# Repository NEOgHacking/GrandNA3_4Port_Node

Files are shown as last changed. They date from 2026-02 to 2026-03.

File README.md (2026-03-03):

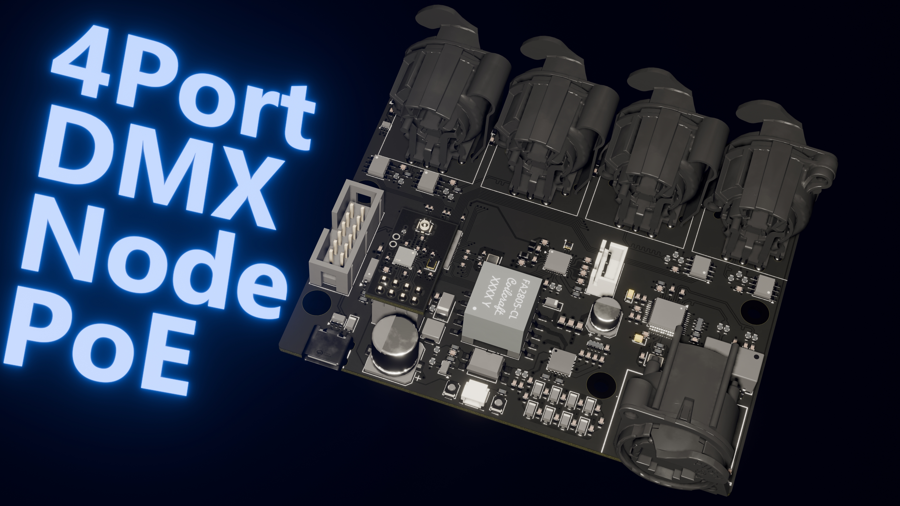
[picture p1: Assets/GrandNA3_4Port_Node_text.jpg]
Render

# GrandNA3_4Port_Node
GrandNA3_4Port_Node is a DMX network node based on the official grandMA3 onPC 4Port Node 4k. My version also has 4DMX outputs with RDM support, a EtherCON connector for sturdy Ethernet connections and a display with a rotating knob for configuration. It also uses the Neutrik halo connectors with adressable rgb leds to show the status of the connection. But it also has some differences. First it unfortunately doesn't unlock any parameters in the GrandMA onPC software, but its 20x cheaper. About $100 instead of $2000.

# Features
This specific DMX node has some really usefull features.
1. 4DMX outputs with RDM support.
2. Neutrik EtherCON connector for a sturdy and lasting connection. Also support for ARTNET and sACN
3. Color display with a rotary encoder for configuration straigt from the unit itself.
4. UPS (uniteruptable power supply) For when the power cuts out but you still need it or just for battery operation.
5. Wifi card slot for wireless operation with the battery.
6. Powered by a rp2350 for its PIO modules so DMX is correctly implemented and not via a hacked uart or bitbanging a pin.
7. PoE (Power over Ethernet) For easy setup and as little wires as possible.
8. USB-C port for power and data to program the rp2350 or configure it.
9. Cheap PCB. The PCB is 100x72mm 4 layer so its cost is low only $7.

# Motivation
I started on making this DMX network node for a few reasons. First i was using a raspberry pi with a usb DMX dongle, this worked but was hard to set up and only got me 1 DMX universe without RDM. It also wasn't the cheapest setup. I wanted it to be cheaper and have more functionallity. Second I once had the opurtunity to use a grandMA3 onPC 4Port Node 4k at school once and realized how usefull it would be. Then my dumb brain said the same sentence it always says: "I can build that myself for cheaper right?" Next thing you know you are 100 hours deep into the project.

# Design
The design process was a heck of a ride, at first i started with the simple DMX part but then got to the ethernet. I really wanted PoE so started with the ride. It was a heck of a long ride, i think it took up 1/3 of the projects time its really complex. Also the most complex schematic from the whole project. The rest went pretty smooth. I had recently done another big project my 3D Printer mainboard and learned allot from that! So the rest was pretty straight forward, always some small chip changes here and there but apart from that it went well. The case design also went quick didn't have to high of standards for that but still wanted it to look good. After a whole day that was done. 
I used KiCad for PCB design, Onshape for 3D design and VScode for Firmware.

# Use
To use this product first get the firmware uploaded via the arduino IDE or PlatformIO Then just plug it into a ethernet setup and plug in your DMX devices. Thats it! Its that simple! For config use the display with the rotating knob to select universes, ethernet settings, ext.

# Schematic
This is a very long schematic. You can find the whole schematics in .PDF format in the individual PCB design folders. But here are some important ones.
First the main schematic of the main PCB.
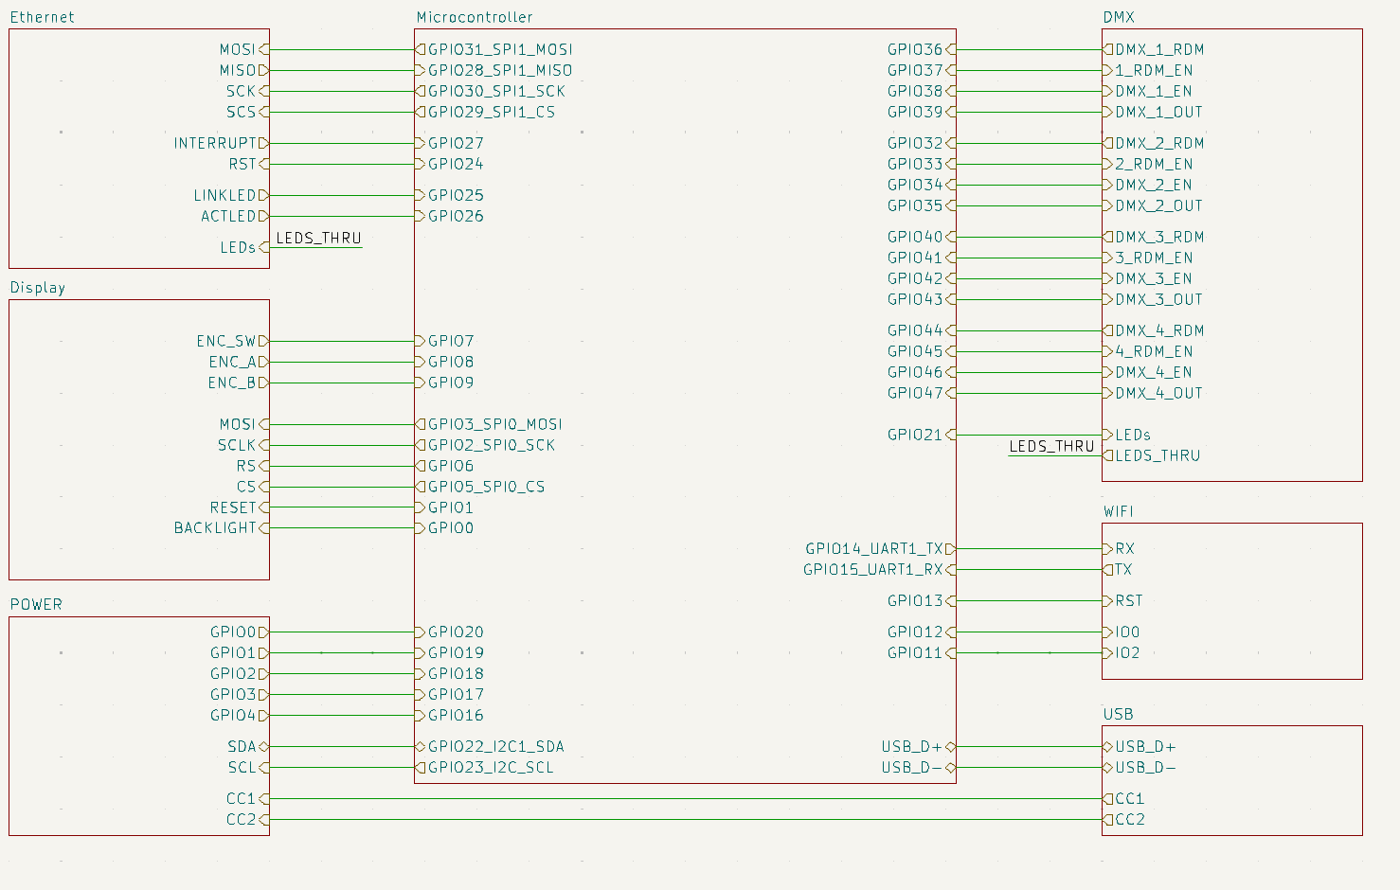
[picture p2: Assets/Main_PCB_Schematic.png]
Main schematic

Then the schematic of the display module.
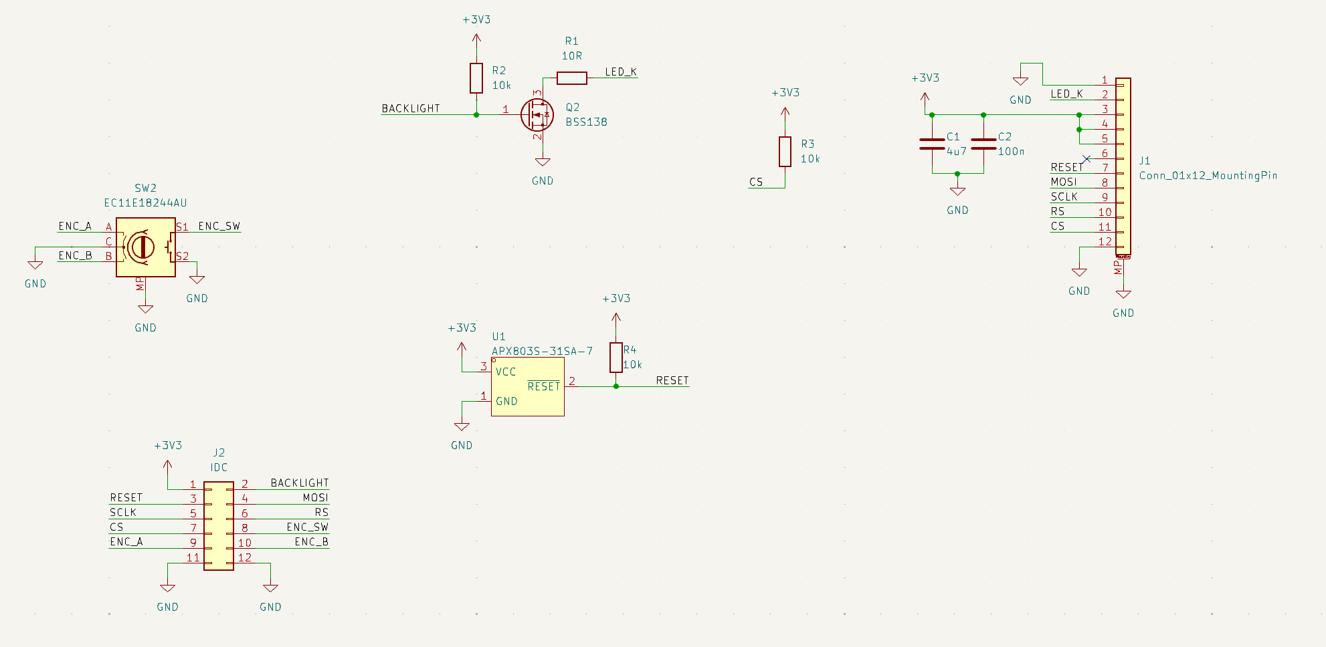
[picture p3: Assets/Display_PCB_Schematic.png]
Display module schematic

And finally the esp wifi module.
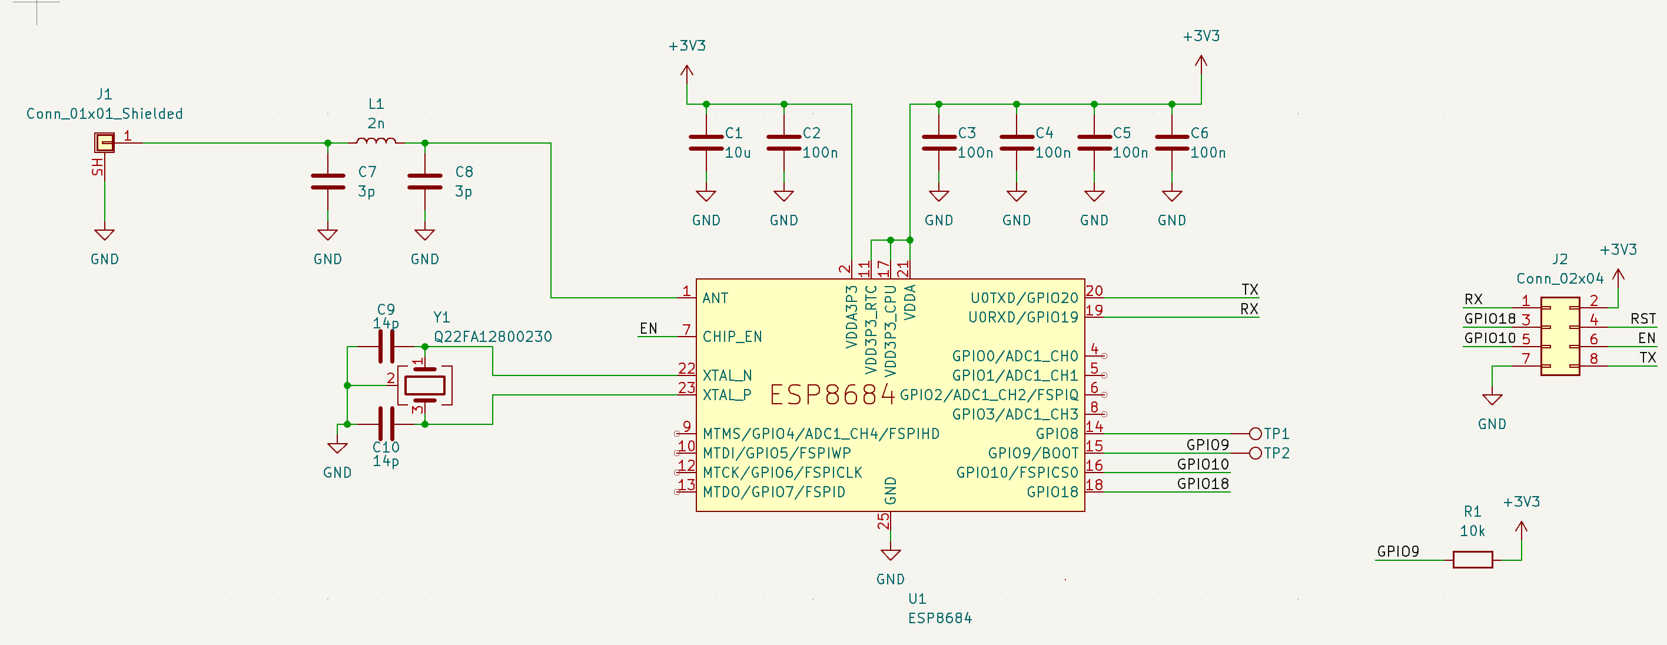
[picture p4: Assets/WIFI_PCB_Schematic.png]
WIFI module schematic


# PCB's
So this project has 3 PCB's, first the main PCB that does all the hard work, then a display PCB with a rotary encoder and support components for a bare LCD and finally a custom made WIFI module PCB based on the esp.
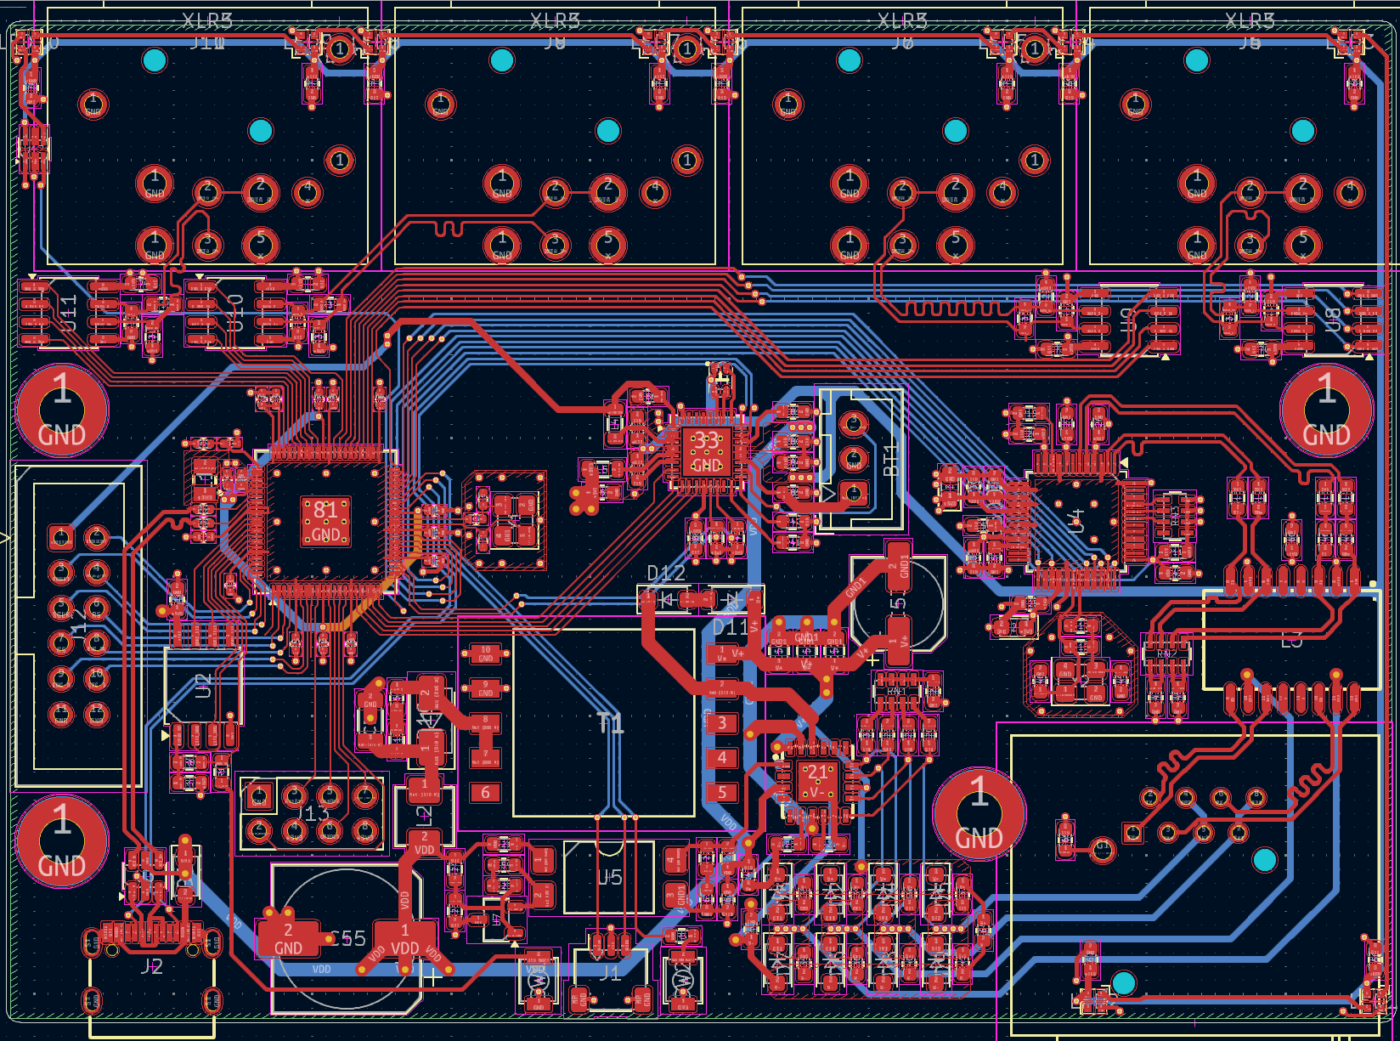
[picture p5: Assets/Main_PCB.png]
Main PCB

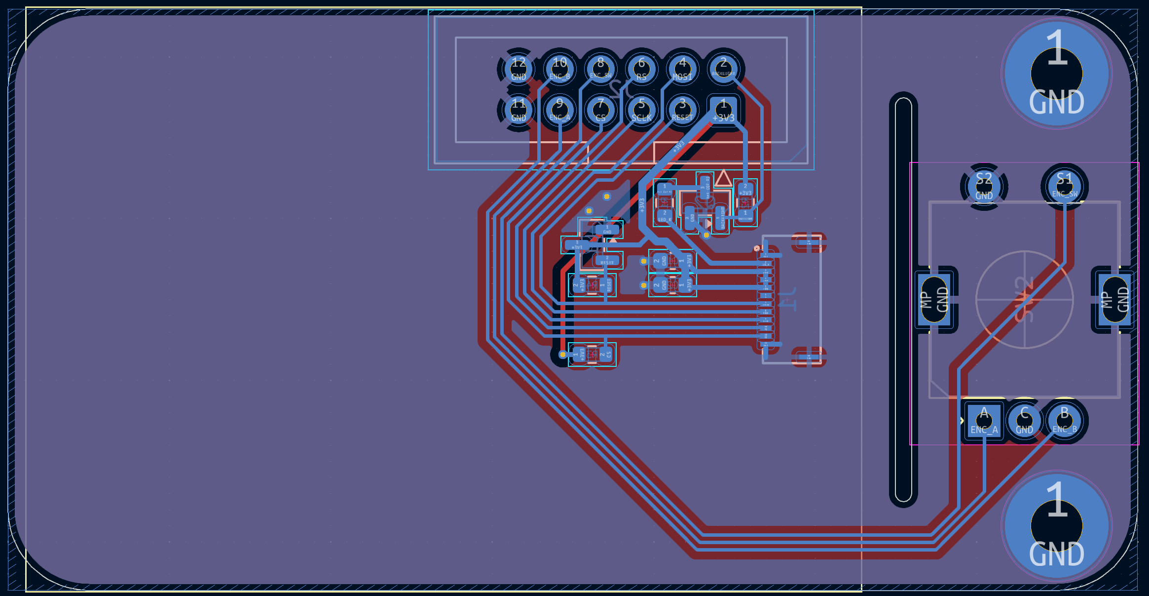
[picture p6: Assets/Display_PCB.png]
Display_module PCB

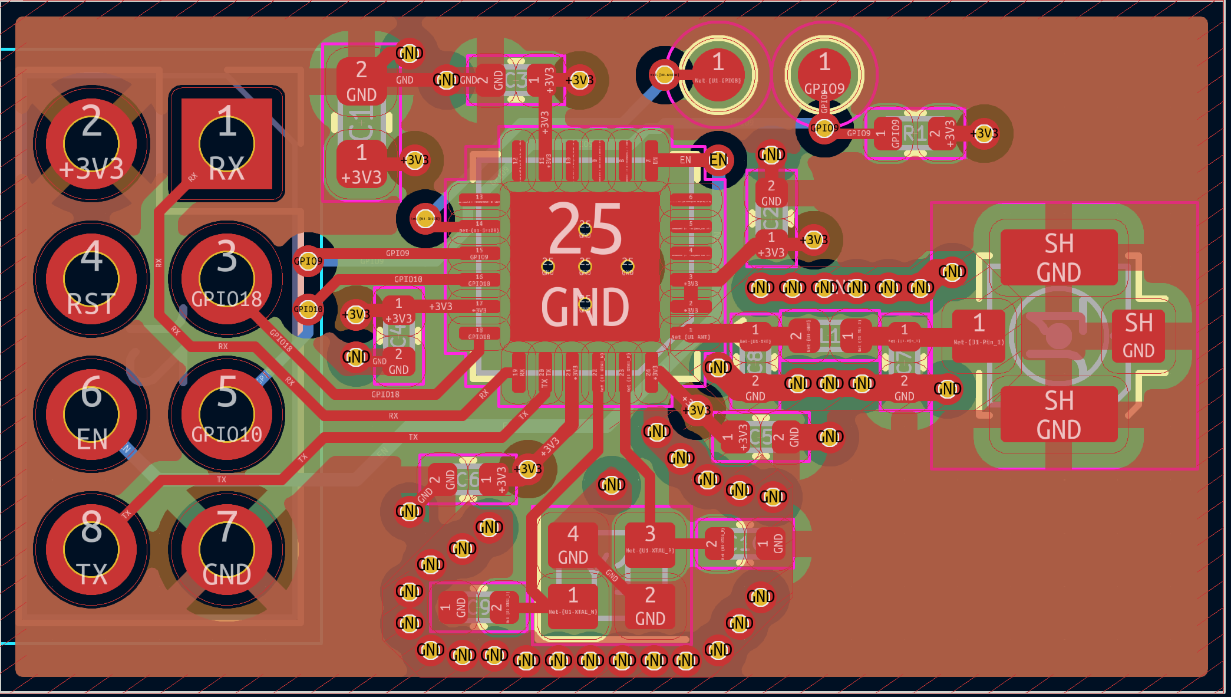
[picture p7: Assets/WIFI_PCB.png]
WIFI_module PCB

(there is a glitch in this game, every project i do i get exactly 3 PCB's)

# Case
For this project there needed to be a case to protect the PCB from the outside world. I did this in onshape and am happy with the end result.
Open_case
Full_case
Here is the Onshape link:
https://cad.onshape.com/documents/7a1aa90c6a7c74ef8699231e/w/3ea57ea1703701009a206be9/e/21fe65d6bda3912845cd8de3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
<details>
  <summary>BOM</summary>
  
# BOM
| Id | Designator | Footprint | Quantity | Designation | Supplier and ref | Column1 | Needed quantity | - | LCSC | MOUSER | Already in another pcb | Enough? | Mrf# | Mfr. | Order Qty. | Unit Price(USD) | Ext.Price(USD) | LCSC#/MOUSER | Package | Min | Mult | SPQ | Availability | Stock Status | Customer Notes | Description | Matched status | Product Link |  |  |  |  |  |  |  |  |  |  |  |  |  |  |  |  |  |  |  |
| --- | --- | --- | --- | --- | --- | --- | --- | --- | --- | --- | --- | --- | --- | --- | --- | --- | --- | --- | --- | --- | --- | --- | --- | --- | --- | --- | --- | --- | --- | --- | --- | --- | --- | --- | --- | --- | --- | --- | --- | --- | --- | --- | --- | --- | --- | --- | --- |
| 17 | BT1 | JST_XH_B3B-XH-A_1x03_P2.50mm_Vertical | 1 | Battery_Cell |  |  | 2 |  | x |  |  |  | B3B-XH-A(LF)(SN) | JST | 10 | $0.05 | $0.50 | C144394 | Through Hole,P=2.5mm | 10 | 10 | 1000 | 61980 | In Stock |  | Connector Header 3 position 2.5mm Pitch 3A Through Hole -25?~+85? | Exact Matches | https://www.lcsc.com/product-detail/C144394.html |  |  |  |  |  |  |  |  |  |  |  |  |  |  |  |  |  |  |  |
| 6 | C12,C7,C5,C13,C11,C4,C6,C3,C9,C10,C8,C1 | C_0402_1005Metric | 12 | 100n |  |  | 24 |  | x |  |  |  | CL05B104KO5NNNC | Samsung Electro-Mechanics | 100 | $0.00 | $0.13 | C1525 | 402 | 100 | 100 | 10000 | 22016000 | In Stock |  | 100nF �10% 16V Ceramic Capacitor X7R 0402 | Exact Matches | https://www.lcsc.com/product-detail/C1525.html |  |  |  |  |  |  |  |  |  |  |  |  |  |  |  |  |  |  |  |
| 37 | C17,C19 | C_0402_1005Metric | 2 | 15p |  |  | 4 |  | x |  |  |  | CL05C150JB5NNNC | Samsung Electro-Mechanics | 100 | $0.00 | $0.37 | C86285 | 402 | 100 | 100 | 10000 | 454800 | In Stock |  | 15pF �5% 50V Ceramic Capacitor C0G 0402 | Exact Matches | https://www.lcsc.com/product-detail/C86285.html |  |  |  |  |  |  |  |  |  |  |  |  |  |  |  |  |  |  |  |
| 3 | C2,C15,C16,C14 | C_0402_1005Metric | 4 | 4u7 |  |  | 8 |  | x |  |  |  | CL05A475KP5NRNC | Samsung Electro-Mechanics | 50 | $0.01 | $0.31 | C368809 | 402 | 50 | 50 | 10000 | 5001000 | In Stock |  | 4.7uF �10% 10V Ceramic Capacitor X5R 0402 | Exact Matches | https://www.lcsc.com/product-detail/C368809.html |  |  |  |  |  |  |  |  |  |  |  |  |  |  |  |  |  |  |  |
| 9 | C20,C23,C57,C33,C21 | C_0603_1608Metric | 5 | 10n |  |  | 10 |  | x |  |  |  | CL10B103KC8NNNC | Samsung Electro-Mechanics | 100 | $0.01 | $0.62 | C84709 | 603 | 100 | 100 | 4000 | 18800 | In Stock |  | 10nF �10% 100V Ceramic Capacitor X7R 0603 | Exact Matches | https://www.lcsc.com/product-detail/C84709.html |  |  |  |  |  |  |  |  |  |  |  |  |  |  |  |  |  |  |  |
| 15 | C22,C36,C39,C41,C34,C38,C63,C37,C65,C47,C40,C35 | C_0603_1608Metric | 12 | 1n |  |  | 24 |  | x |  |  |  | CL10B102KC8NNNC | Samsung Electro-Mechanics | 50 | $0.01 | $0.25 | C153291 | 603 | 50 | 50 | 4000 | 107650 | In Stock |  | 1nF �10% 100V Ceramic Capacitor X7R 0603 | Exact Matches | https://www.lcsc.com/product-detail/C153291.html |  |  |  |  |  |  |  |  |  |  |  |  |  |  |  |  |  |  |  |
| 5 | C27,C76,C72,C70,C73,C64,C79,C60,C28,C74,C29,C88,C43,C78,C61,C71,C30,C66,C69,C68,C25,C42,C75,C67,C45,C31,C18,C26,C77 | C_0603_1608Metric | 29 | 100n |  |  | 58 |  | x |  |  |  | CL10B104KC8NNNC | Samsung Electro-Mechanics | 100 | $0.01 | $0.65 | C15725 | 603 | 50 | 50 | 4000 | 175750 | In Stock |  | 100nF �10% 100V Ceramic Capacitor X7R 0603 | Exact Matches | https://www.lcsc.com/product-detail/C15725.html |  |  |  |  |  |  |  |  |  |  |  |  |  |  |  |  |  |  |  |
| 63 | C32,C24 | CP_EIA-2012-12_Kemet-R | 2 | 10u |  |  | 4 |  | x |  |  |  | T491A106K006AT | KEMET | 5 | $0.18 | $0.91 | C122260 | CASE-A-3216-18(mm) | 5 | 5 | 2000 | 1980 | In Stock |  | 10uF �10% 6.3V Tantalum Capacitors 4?@100kHz CASE-A-3216-18(mm) | Exact Matches | https://www.lcsc.com/product-detail/C122260.html |  |  |  |  |  |  |  |  |  |  |  |  |  |  |  |  |  |  |  |
| 50 | C46,C44 | C_0603_1608Metric | 2 | 6.8n |  |  | 4 |  | x |  |  |  | CL10B682KB8NNNC | Samsung Electro-Mechanics | 100 | $0.01 | $0.68 | C84723 | 603 | 100 | 100 | 4000 | 5300 | In Stock |  | 6.8nF �10% 50V Ceramic Capacitor X7R 0603 | Exact Matches | https://www.lcsc.com/product-detail/C84723.html |  |  |  |  |  |  |  |  |  |  |  |  |  |  |  |  |  |  |  |
| 8 | C48,C49 | C_0603_1608Metric | 2 | 10p |  |  | 4 |  | x |  |  |  | CL10C100JB8NNNC | Samsung Electro-Mechanics | 100 | $0.01 | $0.50 | C1634 | 603 | 100 | 100 | 4000 | 1498600 | In Stock |  | 10pF �5% 50V Ceramic Capacitor C0G 0603 | Exact Matches | https://www.lcsc.com/product-detail/C1634.html |  |  |  |  |  |  |  |  |  |  |  |  |  |  |  |  |  |  |  |
| 41 | C52,C51,C50 | C_0805_2012Metric | 3 | 1u |  |  | 6 |  | x |  |  |  | C2012X7S2A105KT000N | TDK | 10 | $0.11 | $1.12 | C342785 | 805 | 5 | 5 | 2000 | 5645 | In Stock |  | 1uF �10% 100V Ceramic Capacitor X7S 0805 | Exact Matches | https://www.lcsc.com/product-detail/C342785.html |  |  |  |  |  |  |  |  |  |  |  |  |  |  |  |  |  |  |  |
| 57 | C53 | CP_Elec_6.3x5.8 | 1 | 10u |  |  | 2 |  | x |  |  |  | EEEFK1J100P | PANASONIC | 5 | $0.14 | $0.71 | C128459 | SMD,D6.3xL5.8mm | 5 | 5 | 1000 | 1420 | In Stock |  | 10uF �20% 63V Aluminum Electrolytic Capacitors 2000hrs@105? | Exact Matches | https://www.lcsc.com/product-detail/C128459.html |  |  |  |  |  |  |  |  |  |  |  |  |  |  |  |  |  |  |  |
| 69 | C54 | C_0603_1608Metric | 1 | 470p |  |  | 2 |  | x |  |  |  | CL10B471KB8NNNC | Samsung Electro-Mechanics | 100 | $0.01 | $0.56 | C22396 | 603 | 100 | 100 | 4000 | 189700 | In Stock |  | 470pF �10% 50V Ceramic Capacitor X7R 0603 | Exact Matches | https://www.lcsc.com/product-detail/C22396.html |  |  |  |  |  |  |  |  |  |  |  |  |  |  |  |  |  |  |  |
| 44 | C55 | CP_Elec_10x10.5 | 1 | 1000u |  |  | 2 |  | x |  |  |  | EEEFT1E102UP | PANASONIC | 2 | $0.78 | $1.55 | C401766 | SMD,D10xL10.2mm | 1 | 1 | 500 | 4041 | In Stock |  | 1000uF �20% 25V Aluminum Electrolytic Capacitors 2000hrs@105? | Exact Matches | https://www.lcsc.com/product-detail/C401766.html |  |  |  |  |  |  |  |  |  |  |  |  |  |  |  |  |  |  |  |
| 52 | C56 | C_1206_3216Metric | 1 | 100u |  |  | 2 |  | x |  |  |  | CL31A107MQHNNNE | Samsung Electro-Mechanics | 10 | $0.06 | $0.61 | C15008 | 1206 | 10 | 10 | 2000 | 6009890 | In Stock |  | 100uF �20% 6.3V Ceramic Capacitor X5R 1206 | Exact Matches | https://www.lcsc.com/product-detail/C15008.html |  |  |  |  |  |  |  |  |  |  |  |  |  |  |  |  |  |  |  |
| 14 | C58 | C_0603_1608Metric | 1 | 4u7 |  |  | 2 |  | x |  |  |  | CL10A475KP8NNNC | Samsung Electro-Mechanics | 50 | $0.01 | $0.28 | C1705 | 603 | 50 | 50 | 4000 | 13333100 | In Stock |  | 4.7uF �10% 10V Ceramic Capacitor X5R 0603 | Exact Matches | https://www.lcsc.com/product-detail/C1705.html |  |  |  |  |  |  |  |  |  |  |  |  |  |  |  |  |  |  |  |
| 20 | C59 | C_0603_1608Metric | 1 | 3.3n |  |  | 2 |  | x |  |  |  | CL10B332KB8NNNC | Samsung Electro-Mechanics | 20 | $0.01 | $0.11 | C1613 | 603 | 20 | 20 | 4000 | 61420 | In Stock |  | 3.3nF �10% 50V Ceramic Capacitor X7R 0603 | Exact Matches | https://www.lcsc.com/product-detail/C1613.html |  |  |  |  |  |  |  |  |  |  |  |  |  |  |  |  |  |  |  |
| 42 | C62 | C_0603_1608Metric | 1 | 15n |  |  | 2 |  | x |  |  |  | CL10B153KB8NNNC | Samsung Electro-Mechanics | 20 | $0.01 | $0.16 | C296713 | 603 | 20 | 20 | 4000 | 39800 | In Stock |  | 15nF �10% 50V Ceramic Capacitor X7R 0603 | Exact Matches | https://www.lcsc.com/product-detail/C296713.html |  |  |  |  |  |  |  |  |  |  |  |  |  |  |  |  |  |  |  |
| 10 | C80,C81 | C_0603_1608Metric | 2 | 1u |  |  | 4 |  | x |  |  |  | CL10A105KB8NNNC | Samsung Electro-Mechanics | 50 | $0.01 | $0.28 | C15849 | 603 | 50 | 50 | 4000 | 4548950 | In Stock |  | 1uF �10% 50V Ceramic Capacitor X5R 0603 | Exact Matches | https://www.lcsc.com/product-detail/C15849.html |  |  |  |  |  |  |  |  |  |  |  |  |  |  |  |  |  |  |  |
| 53 | C82,C86,C87,C83,C84 | C_0603_1608Metric | 5 | 10u |  |  | 10 |  | x |  |  |  | CL10A106KP8NNNC | Samsung Electro-Mechanics | 50 | $0.01 | $0.33 | C19702 | 603 | 50 | 50 | 4000 | 13475400 | In Stock |  | 10uF �10% 10V Ceramic Capacitor X5R 0603 | Exact Matches | https://www.lcsc.com/product-detail/C19702.html |  |  |  |  |  |  |  |  |  |  |  |  |  |  |  |  |  |  |  |
| 58 | C85 | C_0603_1608Metric | 1 | 2u2 |  |  | 2 |  | x |  |  |  | CL10A225KO8NNNC | Samsung Electro-Mechanics | 50 | $0.01 | $0.31 | C23630 | 603 | 50 | 50 | 4000 | 5941500 | In Stock |  | 2.2uF �10% 16V Ceramic Capacitor X5R 0603 | Exact Matches | https://www.lcsc.com/product-detail/C23630.html |  |  |  |  |  |  |  |  |  |  |  |  |  |  |  |  |  |  |  |
| 32 | D1 | D_SOD-123F | 1 | DSK24L |  |  | 2 |  | x |  |  |  | DSK24L | LGE | 10 | $0.06 | $0.62 | C19272974 | SOD-123FL | 10 | 10 | 3000 | 2600 | In Stock |  | Diode Independent 40V 2A Surface Mount SOD-123FL | Exact Matches | https://www.lcsc.com/product-detail/C19272974.html |  |  |  |  |  |  |  |  |  |  |  |  |  |  |  |  |  |  |  |
| 56 | D10 | D_SMA | 1 | SS34 |  |  | 2 |  | x |  |  |  | SS34 | GOODWORK | 20 | $0.03 | $0.56 | C908680 | SMA(DO-214AC) | 20 | 20 | 5000 | 202260 | In Stock |  | Diode Independent 40V 3A Surface Mount SMA(DO-214AC) | Exact Matches | https://www.lcsc.com/product-detail/C908680.html |  |  |  |  |  |  |  |  |  |  |  |  |  |  |  |  |  |  |  |
| 49 | D11 | D_SOD-123 | 1 | 1N4148W |  |  | 2 |  | x |  |  |  | 1N4148W-E3-08 | VISHAY | 5 | $0.03 | $0.17 | C241939 | SOD-123 | 5 | 5 | 3000 | 71145 | In Stock |  | Diode Independent 75V 150mA Surface Mount SOD-123 | Exact Matches | https://www.lcsc.com/product-detail/C241939.html |  |  |  |  |  |  |  |  |  |  |  |  |  |  |  |  |  |  |  |
| 66 | D12 | D_SOD-123F | 1 | DFTL30A |  |  | 2 |  | x |  |  |  | P4FL30A_R1_00001 | PANJIT | 5 | $0.09 | $0.43 | C2902532 | SOD-123FL | 5 | 5 | 3000 | 2220 | In Stock |  | 48.4VC Clamp 8.3A@10/1000us Ipp TVS DIODE SOD-123FL | Exact Matches | https://www.lcsc.com/product-detail/C2902532.html |  |  |  |  |  |  |  |  |  |  |  |  |  |  |  |  |  |  |  |
| 11 | D13 | LED-SMD_4P-L1.6-W1.5-TR | 1 | LED_ABGR |  |  | 2 |  | x |  |  |  | DY-S161506BRGC-T5-4T-03 | TONYU | 10 | $0.04 | $0.37 | C7280953 | SMD,1.6x1.5mm | 10 | 10 | 4000 | 1640 | In Stock |  | Red, Green, Blue 630nm LED Indication - Discrete 1.8V~2.4V SMD,1.5x1.6mm | Exact Matches | https://www.lcsc.com/product-detail/C7280953.html |  |  |  |  |  |  |  |  |  |  |  |  |  |  |  |  |  |  |  |
| 28 | D2,D7,D5,D6,D9,D3,D4,D8 | D_SOD-123F | 8 | SL110PL-TP |  |  | 16 |  | x |  |  |  | SL110PL-TP | MCC | 20 | $0.15 | $3.07 | C7080765 | SOD-123FL | 10 | 10 | 2500 | 4140 | In Stock |  | Diode 100V 1A Surface Mount SOD-123FL | Exact Matches | https://www.lcsc.com/product-detail/C7080765.html |  |  |  |  |  |  |  |  |  |  |  |  |  |  |  |  |  |  |  |
| 62 | IC1 | QFN-32-1EP_5x5mm_P0.5mm_EP3.45x3.45mm_ThermalVias | 1 | NPM1300-QEAA-R7 |  |  | 2 |  |  | x |  |  | nPM1300-QEAA-R7 | Nordic Semiconductor | 2 | $1.54 | $3.08 | 949-NPM1300-QEAA-R7 |  |  |  |  |  |  |  |  |  | https://nl.mouser.com/ProductDetail/Nordic-Semiconductor/nPM1300-QEAA-R7?qs=3pZoU%2F6IRTj0hxAp51B2zA%3D%3D |  |  |  |  |  |  |  |  |  |  |  |  |  |  |  |  |  |  |  |
| 33 | J1 | JST_SH_SM03B-SRSS-TB_1x03-1MP_P1.00mm_Horizontal | 1 | Conn_01x03_MountingPin |  |  | 2 |  | x |  |  |  | SM03B-SRSS-TB(LF)(SN) | JST | 5 | $0.17 | $0.87 | C160403 | SMD,P=1mm,Surface Mount,Right Angle | 5 | 5 | 3000 | 47315 | In Stock |  | Connector Header 3 position 1mm Pitch 1A Surface Mount, Right Angle -25?~+85? | Exact Matches | https://www.lcsc.com/product-detail/C160403.html |  |  |  |  |  |  |  |  |  |  |  |  |  |  |  |  |  |  |  |
| 39 | J12 | IDC-Header_2x06_P2.54mm_Vertical | 1 | IDC |  |  | 2 |  | x |  |  |  | 2.54-2*6P | BOOMELE(Boom Precision Elec) | 5 | $0.11 | $0.57 | C9136 | Through Hole,P=2.54mm | 5 | 5 | 220 | 19840 | In Stock |  | Connector IDC Header Through Hole 12 position 2.54mm | Exact Matches | https://www.lcsc.com/product-detail/C9136.html |  |  |  |  |  |  |  |  |  |  |  |  |  |  |  |  |  |  |  |
| 51 | J13 | PinSocket_2x04_P2.54mm_Vertical | 1 | Conn_02x04 |  |  | 2 |  | x |  |  |  | PM254V-12-08-H85 | XFCN | 5 | $0.11 | $0.56 | C2834799 | Through Hole,P=2.54mm | 5 | 5 | 1000 | 26375 | In Stock |  | Female Header 8 Position 2.54mm Pitch Dual Row Through Hole -40?~+105? | Exact Matches | https://www.lcsc.com/product-detail/C2834799.html |  |  |  |  |  |  |  |  |  |  |  |  |  |  |  |  |  |  |  |
| 13 | J2 | USB-C_SMD-TYPE-C-31-M-12_1 | 1 | USB_C_Receptacle_USB2.0_14P |  |  | 2 |  | x |  |  |  | TYPE-C-31-M-12 | Korean Hroparts Elec | 5 | $0.17 | $0.84 | C165948 | SMD | 5 | 5 | 1000 | 263130 | In Stock |  | USB-C (USB TYPE-C) Receptacle Connector 16 Position Surface Mount | Exact Matches | https://www.lcsc.com/product-detail/C165948.html |  |  |  |  |  |  |  |  |  |  |  |  |  |  |  |  |  |  |  |
| 1 | J3 | NE8FAHLRDAE | 1 | RJ45 |  |  | 2 |  |  | x |  |  | NE8FAH-LR-DAE | Neutrik | 2 | $6.73 | $13.46 | 568-NE8FAH-LR-DAE |  |  |  |  |  |  |  |  |  | https://nl.mouser.com/ProductDetail/Neutrik/NE8FAH-LR-DAE?qs=4ASt3YYao0WhX9cY4j%252BFSA%3D%3D |  |  |  |  |  |  |  |  |  |  |  |  |  |  |  |  |  |  |  |
| 12 | J4,J8,J10,J6 | NC5FAH1-LR-DAE | 4 | XLR5 |  |  | 4 |  |  | x |  |  | NC5FAH1-LR-DAE | Neutrik | 4 | $7.79 | $31.16 | 568-NC5FAH1-LR-DAE |  |  |  |  |  |  |  |  |  | https://nl.mouser.com/ProductDetail/Neutrik/NC5FAH1-LR-DAE?qs=6avfeC6zeS5u3oz5Q9UQlw%3D%3D |  |  |  |  |  |  |  |  |  |  |  |  |  |  |  |  |  |  |  |
| 47 | J7,J11,J5,J9 | NC3FAH2-LR-DAE | 4 | XLR3 |  |  | 4 |  |  | x |  |  | NC3FAH2-LR-DAE | Neutrik | 4 | $4.33 | $17.32 | 568-NC3FAH2-LR-DAE |  |  |  |  |  |  |  |  |  | https://nl.mouser.com/ProductDetail/Neutrik/NC3FAH2-LR-DAE?qs=4ASt3YYao0XSl5KoEkZrIA%3D%3D |  |  |  |  |  |  |  |  |  |  |  |  |  |  |  |  |  |  |  |
| 21 | L1 | IND-SMD_L2.0-W1.6_AOTA-B201610S3R3-101-T | 1 | 3.3u |  |  | 2 |  | x |  |  |  | AOTA-B201610S3R3-101-T | ABRACON | 5 | $0.29 | $1.44 | C42411119 | 806 | 5 | 5 | 3000 | 15360 | In Stock |  | 2.1A 3.3uH 115m? 2.4A Molded Inductor 0806 Fixed Inductors RoHS | Exact Matches | https://www.lcsc.com/product-detail/C42411119.html |  |  |  |  |  |  |  |  |  |  |  |  |  |  |  |  |  |  |  |
| 48 | L2 | L_Vishay_IHLP-1616 | 1 | 1u |  |  | 2 |  | x |  |  |  | IHLP1616BZER1R0M11 | VISHAY | 2 | $1.63 | $3.26 | C844978 | 1616 | 1 | 1 | 4000 | 79 | In Stock |  | 4.5A 1uH 27m? 5A �20% 1616 Fixed Inductors RoHS | Exact Matches | https://www.lcsc.com/product-detail/C844978.html |  |  |  |  |  |  |  |  |  |  |  |  |  |  |  |  |  |  |  |
| 22 | L3 | XFMR-SMD_16P-L12.7-W7.1-P1.27-LS9.4-BL | 1 | H2019NLT |  |  | 2 |  | x |  |  |  | H2019NLT | PULSE | 2 | $0.74 | $1.49 | C110250 | SMD,12.7x7.1mm | 1 | 1 | 600 | 2085 | In Stock |  | LAN Transformer 1CT:1CT Surface Mount,12.7x7.1mm | Exact Matches | https://www.lcsc.com/product-detail/C110250.html |  |  |  |  |  |  |  |  |  |  |  |  |  |  |  |  |  |  |  |
| 30 | L4,L5 | L_0805_2012Metric | 2 | 2u2 |  |  | 4 |  | x |  |  |  | MLP2012H2R2MT0S1 | TDK | 10 | $0.08 | $0.84 | C383369 | 805 | 10 | 10 | 4000 | 89820 | In Stock |  | 1A 2.2uH 195m? �20% 0805 Fixed Inductors RoHS | Exact Matches | https://www.lcsc.com/product-detail/C383369.html |  |  |  |  |  |  |  |  |  |  |  |  |  |  |  |  |  |  |  |
| 16 | LED1,LED5,LED6,LED3,LED8,LED10,LED9,LED2,LED4,LED7 | LED-SMD_4P-L1.5-W1.5-BL | 10 | SK6805-EC15 |  |  | 20 |  | x |  |  |  | SK6805-EC15 | OPSCO Optoelectronics | 45 | $0.09 | $4.04 | C2890035 | SMD-4P,1.5x1.5mm | 5 | 5 | 4500 | 259070 | In Stock |  | SMD-4P,1.5x1.5mm LED Addressable, Specialty RoHS | Exact Matches | https://www.lcsc.com/product-detail/C2890035.html |  |  |  |  |  |  |  |  |  |  |  |  |  |  |  |  |  |  |  |
| 29 | R1,R27,R3 | R_0603_1608Metric | 3 | 1k |  |  | 6 |  | x |  |  |  | RC0603FR-071KL | YAGEO | 100 | $0.00 | $0.14 | C22548 | 603 | 100 | 100 | 5000 | 4596000 | In Stock |  | 100mW 1k? 75V Thick Film Resistor �100ppm/? �1% 0603 Chip Resistor - Surface Mount RoHS | Exact Matches | https://www.lcsc.com/product-detail/C22548.html |  |  |  |  |  |  |  |  |  |  |  |  |  |  |  |  |  |  |  |
| 34 | R11,R43,R7,R42 | R_0603_1608Metric | 4 | 10k |  |  | 8 |  | x |  |  |  | RC0603FR-0710KL | YAGEO | 100 | $0.00 | $0.14 | C98220 | 603 | 100 | 100 | 5000 | 9034300 | In Stock |  | 100mW 10k? 75V Thick Film Resistor �100ppm/? �1% 0603 Chip Resistor - Surface Mount RoHS | Exact Matches | https://www.lcsc.com/product-detail/C98220.html |  |  |  |  |  |  |  |  |  |  |  |  |  |  |  |  |  |  |  |
| 19 | R13,R12,R15,R14 | R_0603_1608Metric | 4 | 33R |  |  | 8 |  | x |  |  |  | RC0603FR-0733RL | YAGEO | 100 | $0.00 | $0.15 | C108661 | 603 | 100 | 100 | 5000 | 1912100 | In Stock |  | 100mW 33? 75V Thick Film Resistor �100ppm/? �1% 0603 Chip Resistor - Surface Mount RoHS | Exact Matches | https://www.lcsc.com/product-detail/C108661.html |  |  |  |  |  |  |  |  |  |  |  |  |  |  |  |  |  |  |  |
| 38 | R16 | R_0603_1608Metric | 1 | 1M |  |  | 2 |  | x |  |  |  | RC0603FR-071ML | YAGEO | 100 | $0.00 | $0.15 | C105578 | 603 | 100 | 100 | 5000 | 711300 | In Stock |  | 100mW 1M? 75V Thick Film Resistor �100ppm/? �1% 0603 Chip Resistor - Surface Mount RoHS | Exact Matches | https://www.lcsc.com/product-detail/C105578.html |  |  |  |  |  |  |  |  |  |  |  |  |  |  |  |  |  |  |  |
| 2 | R18 | R_0603_1608Metric | 1 | 10R |  |  | 2 |  | x |  |  |  | RC0603FR-0710RL | YAGEO | 100 | $0.00 | $0.43 | C109318 | 603 | 100 | 100 | 5000 | 1937200 | In Stock |  | 100mW 10? 75V Thick Film Resistor �1% �200ppm/? 0603 Chip Resistor - Surface Mount RoHS | Exact Matches | https://www.lcsc.com/product-detail/C109318.html |  |  |  |  |  |  |  |  |  |  |  |  |  |  |  |  |  |  |  |
| 72 | R19 | R_0603_1608Metric | 1 | 12.4k |  |  | 2 |  | x |  |  |  | RC0603FR-0712K4L | YAGEO | 100 | $0.00 | $0.15 | C137798 | 603 | 100 | 100 | 5000 | 38200 | In Stock |  | 100mW 12.4k? 75V Thick Film Resistor �100ppm/? �1% 0603 Chip Resistor - Surface Mount RoHS | Exact Matches | https://www.lcsc.com/product-detail/C137798.html |  |  |  |  |  |  |  |  |  |  |  |  |  |  |  |  |  |  |  |
| 54 | R2 | R_0402_1005Metric | 1 | 33R |  |  | 2 |  | x |  |  |  | RC0402FR-0733RL | YAGEO | 100 | $0.00 | $0.08 | C138002 | 402 | 100 | 100 | 10000 | 1384200 | In Stock |  | 62.5mW 33? 50V Thick Film Resistor �100ppm/? �1% 0402 Chip Resistor - Surface Mount RoHS | Exact Matches | https://www.lcsc.com/product-detail/C138002.html |  |  |  |  |  |  |  |  |  |  |  |  |  |  |  |  |  |  |  |
| 73 | R20 | R_0603_1608Metric | 1 | 4.99k |  |  | 2 |  | x |  |  |  | RC0603FR-074K99L | YAGEO | 100 | $0.00 | $0.15 | C114621 | 603 | 100 | 100 | 5000 | 164800 | In Stock |  | 100mW 4.99k? 75V Thick Film Resistor �100ppm/? �1% 0603 Chip Resistor - Surface Mount RoHS | Exact Matches | https://www.lcsc.com/product-detail/C114621.html |  |  |  |  |  |  |  |  |  |  |  |  |  |  |  |  |  |  |  |
| 24 | R21 | R_0603_1608Metric | 1 | 2.05k |  |  | 2 |  | x |  |  |  | RC0603FR-072K05L | YAGEO | 100 | $0.00 | $0.14 | C137751 | 603 | 100 | 100 | 5000 | 7700 | In Stock |  | 100mW 2.05k? 75V Thick Film Resistor �100ppm/? �1% 0603 Chip Resistor - Surface Mount RoHS | Exact Matches | https://www.lcsc.com/product-detail/C137751.html |  |  |  |  |  |  |  |  |  |  |  |  |  |  |  |  |  |  |  |
| 46 | R22,R40,R23,R17,R8 | R_0603_1608Metric | 5 | 0R |  |  | 10 |  | x |  |  |  | RC0603FR-070RL | YAGEO | 100 | $0.00 | $0.13 | C100044 | 603 | 100 | 100 | 5000 | 2174100 | In Stock |  | 0? 100mW 75V Thick Film Resistor �1% 0603 Chip Resistor - Surface Mount RoHS | Exact Matches | https://www.lcsc.com/product-detail/C100044.html |  |  |  |  |  |  |  |  |  |  |  |  |  |  |  |  |  |  |  |
| 55 | R24 | R_0603_1608Metric | 1 | 36.5k |  |  | 2 |  | x |  |  |  | RC0603FR-0736K5L | YAGEO | 100 | $0.00 | $0.14 | C137738 | 603 | 100 | 100 | 5000 | 20500 | In Stock |  | 36.5k? 100mW 75V Thick Film Resistor �100ppm/? �1% 0603 Chip Resistor - Surface Mount RoHS | Exact Matches | https://www.lcsc.com/product-detail/C137738.html |  |  |  |  |  |  |  |  |  |  |  |  |  |  |  |  |  |  |  |
| 68 | R25 | R_0603_1608Metric | 1 | 12.1k |  |  | 2 |  | x |  |  |  | RC0603FR-0712K1L | YAGEO | 100 | $0.00 | $0.18 | C123417 | 603 | 100 | 100 | 5000 | 0 | Backordered |  | 100mW 12.1k? 75V Thick Film Resistor �100ppm/? �1% 0603 Chip Resistor - Surface Mount RoHS | Exact Matches | https://www.lcsc.com/product-detail/C123417.html |  |  |  |  |  |  |  |  |  |  |  |  |  |  |  |  |  |  |  |
| 67 | R26 | R_0603_1608Metric | 1 | 24.9k |  |  | 2 |  | x |  |  |  | RC0603FR-0724K9L | YAGEO | 100 | $0.00 | $0.15 | C137761 | 603 | 100 | 100 | 5000 | 0 | Backordered |  | 100mW 24.9k? 75V Thick Film Resistor �100ppm/? �1% 0603 Chip Resistor - Surface Mount RoHS | Exact Matches | https://www.lcsc.com/product-detail/C137761.html |  |  |  |  |  |  |  |  |  |  |  |  |  |  |  |  |  |  |  |
| 4 | R29,R38,R28,R30,R39,R31,R36,R37 | R_0603_1608Metric | 8 | 348R |  |  | 16 |  | x |  |  |  | RC0603FR-07348RL | YAGEO | 100 | $0.00 | $0.14 | C137742 | 603 | 100 | 100 | 5000 | 6700 | In Stock |  | 100mW 348? 75V Thick Film Resistor �100ppm/? �1% 0603 Chip Resistor - Surface Mount RoHS | Exact Matches | https://www.lcsc.com/product-detail/C137742.html |  |  |  |  |  |  |  |  |  |  |  |  |  |  |  |  |  |  |  |
| 26 | R33,R32,R35,R34 | R_0603_1608Metric | 4 | 133R |  |  | 8 |  | x |  |  |  | RC0603FR-07133RL | YAGEO | 100 | $0.00 | $0.07 | C273752 | 603 | 100 | 100 | 5000 | 0 | Backordered |  | 133? 100mW 75V Thick Film Resistor �100ppm/? �1% 0603 Chip Resistor - Surface Mount RoHS | Exact Matches | https://www.lcsc.com/product-detail/C273752.html |  |  |  |  |  |  |  |  |  |  |  |  |  |  |  |  |  |  |  |
| 61 | R41 | R_0603_1608Metric | 1 | 430k |  |  | 2 |  | x |  |  |  | RC0603FR-07430KL | YAGEO | 100 | $0.00 | $0.15 | C482869 | 603 | 100 | 100 | 5000 | 30900 | In Stock |  | 430k? 100mW 75V Thick Film Resistor �100ppm/? �1% 0603 Chip Resistor - Surface Mount RoHS | Exact Matches | https://www.lcsc.com/product-detail/C482869.html |  |  |  |  |  |  |  |  |  |  |  |  |  |  |  |  |  |  |  |
| 7 | R5,R4 | R_0402_1005Metric | 2 | 27R |  |  | 4 |  | x |  |  |  | RC0402FR-0727RL | YAGEO | 100 | $0.00 | $0.09 | C138021 | 402 | 100 | 100 | 10000 | 134000 | In Stock |  | 27? �1% 62.5mW 0402 Thick Film Resistor | Exact Matches | https://www.lcsc.com/product-detail/C138021.html |  |  |  |  |  |  |  |  |  |  |  |  |  |  |  |  |  |  |  |
| 64 | R6 | R_0402_1005Metric | 1 | 1k |  |  | 2 |  | x |  |  |  | RC0402FR-071KL | YAGEO | 100 | $0.00 | $0.08 | C106235 | 402 | 100 | 100 | 10000 | 5619500 | In Stock |  | 1k? 62.5mW 50V Thick Film Resistor �100ppm/? �1% 0402 Chip Resistor - Surface Mount RoHS | Exact Matches | https://www.lcsc.com/product-detail/C106235.html |  |  |  |  |  |  |  |  |  |  |  |  |  |  |  |  |  |  |  |
| 45 | REF**,REF**,REF** | NLR-LB | 3 | NLR-LB |  |  | 6 |  |  | x |  |  | NLR-LB | Neutrik | 6 | $1.01 | $6.06 | 568-NLR-LB |  |  |  |  |  |  |  |  |  | https://nl.mouser.com/ProductDetail/Neutrik/NLR-LB?qs=Imq1NPwxi76abBKVKeKReg%3D%3D |  |  |  |  |  |  |  |  |  |  |  |  |  |  |  |  |  |  |  |
| 36 | RN1,RN2 | R_Array_Concave_4x0603 | 2 | 75R |  |  | 4 |  | x |  |  |  | RTA03-4D750JTP | RALEC | 100 | $0.01 | $0.50 | C102680 | 0603x4 | 100 | 100 | 5000 | 584400 | In Stock |  | 4 �5% 75? 62.5mW �200ppm/? 0603x4 Resistor Networks, Arrays RoHS | Exact Matches | https://www.lcsc.com/product-detail/C102680.html |  |  |  |  |  |  |  |  |  |  |  |  |  |  |  |  |  |  |  |
| 59 | RN3 | R_Array_Concave_4x0603 | 1 | 10k |  |  | 2 |  | x |  |  |  | YC164-FR-0710KL | YAGEO | 50 | $0.01 | $0.47 | C110924 | 0603x4 | 50 | 50 | 5000 | 15400 | In Stock |  | 4 �1% 10k? 62.5mW �200ppm/? 0603x4 Resistor Networks, Arrays RoHS | Exact Matches | https://www.lcsc.com/product-detail/C110924.html |  |  |  |  |  |  |  |  |  |  |  |  |  |  |  |  |  |  |  |
| 18 | SW2,SW1 | SW_SPST_B3U-1000P | 2 | SW_Push |  |  | 4 |  | x |  |  |  | B3U-1000P | OMRON | 5 | $0.22 | $1.09 | C231329 | SMD,3x2.5mm | 5 | 5 | 3500 | 107795 | In Stock |  | Tactile Switch SPST 153gf 1.6mm SMD (SMT) Tab 3mm x 2.5mm Surface Mount | Exact Matches | https://www.lcsc.com/product-detail/C231329.html |  |  |  |  |  |  |  |  |  |  |  |  |  |  |  |  |  |  |  |
| 65 | T1 | FA2924ALD | 1 | FA2805 |  |  | 2 |  |  | x |  |  | FA2805-CLD | Coilcraft | 2 | $4.94 | $9.88 | 994-FA2805-CLD |  |  |  |  |  |  |  |  |  | https://nl.mouser.com/ProductDetail/Coilcraft/FA2805-CLD?qs=ZYnrCdKdyef%252BZjF1kFFBVA%3D%3D |  |  |  |  |  |  |  |  |  |  |  |  |  |  |  |  |  |  |  |
| 43 | U1 | QFN-80-1EP_10x10mm_P0.4mm_EP3.4x3.4mm | 1 | RP2350B |  |  | 2 |  |  | x |  |  | SC1510(13)-A4 | Raspberry Pi | 2 | $0.90 | $1.79 | 358-SC151013 |  |  |  |  |  |  |  |  |  | https://nl.mouser.com/ProductDetail/Raspberry-Pi/SC151013-A4?qs=jcD%2FCkGBYeM5TtP1Ew4BSg%3D%3D |  |  |  |  |  |  |  |  |  |  |  |  |  |  |  |  |  |  |  |
| 31 | U10,U8,U9,U11 | SOIC-8_3.9x4.9mm_P1.27mm | 4 | MAX3485 |  |  | 8 |  | x |  |  |  | MAX3485EESA+T | MAXIM | 8 | $2.30 | $18.38 | C9943 | SOIC-8 | 1 | 1 | 2500 | 12603 | In Stock |  | 3V~3.6V Transceiver 12Mbps Half-Duplex SOIC-8 Drivers, Receivers, Transceivers RoHS | Exact Matches | https://www.lcsc.com/product-detail/C9943.html |  |  |  |  |  |  |  |  |  |  |  |  |  |  |  |  |  |  |  |
| 25 | U12 | SOT-363_SC-70-6 | 1 | TXS0101DCK |  |  | 2 |  | x |  |  |  | TXS0101DCKR | TI | 2 | $0.52 | $1.04 | C132031 | SC-70-6 | 1 | 1 | 3000 | 660 | In Stock |  | 24Mbps 1 1 SC-70-6 Translators, Level Shifters RoHS | Exact Matches | https://www.lcsc.com/product-detail/C132031.html |  |  |  |  |  |  |  |  |  |  |  |  |  |  |  |  |  |  |  |
| 70 | U2 | SOIC-8_5.3x5.3mm_P1.27mm | 1 | W25Q128JVS |  |  | 2 |  | x |  |  |  | W25Q128JVSIQ | Winbond | 5 | $2.34 | $11.69 | C97521 | SOIC-8-208mil | 5 | 5 | 2000 | 59900 | In Stock |  | 2.7V~3.6V 128Mbit 133MHz SPI SOIC-8-208mil Memory (ICs) RoHS | Exact Matches | https://www.lcsc.com/product-detail/C97521.html |  |  |  |  |  |  |  |  |  |  |  |  |  |  |  |  |  |  |  |
| 27 | U3 | SOT-23-6 | 1 | USBLC6-2SC6 |  |  | 2 |  | x |  |  |  | USBLC6-2SC6 | ST | 5 | $0.14 | $0.69 | C7519 | SOT-23-6L | 5 | 5 | 3000 | 29740 | In Stock |  | 17VC Clamp 5A Ipp ESD DIODE SOT-23-6L | Exact Matches | https://www.lcsc.com/product-detail/C7519.html |  |  |  |  |  |  |  |  |  |  |  |  |  |  |  |  |  |  |  |
| 60 | U4 | LQFP-48_7x7mm_P0.5mm | 1 | W5500 |  |  | 2 |  | x |  |  |  | W5500 | WIZNET | 2 | $2.78 | $5.56 | C32843 | LQFP-48(7x7) | 1 | 1 | 2500 | 40852 | In Stock |  | 8 SPI LQFP-48(7x7) Interface Controllers RoHS | Exact Matches | https://www.lcsc.com/product-detail/C32843.html |  |  |  |  |  |  |  |  |  |  |  |  |  |  |  |  |  |  |  |
| 71 | U5 | SMDIP-4_W9.53mm_Clearance8mm | 1 | VO618A-3X017T |  |  | 2 |  | x |  |  |  | VO618A-3X017T | VISHAY | 5 | $0.38 | $1.89 | C143748 | SMD-4P | 5 | 5 | 1000 | 4355 | In Stock |  | 50mA 250mV@2.5mA,1mA 80V 6V 1.1V DC SMD-4P Transistor, Photovoltaic Output Optoisolators RoHS | Exact Matches | https://www.lcsc.com/product-detail/C143748.html |  |  |  |  |  |  |  |  |  |  |  |  |  |  |  |  |  |  |  |
| 74 | U6 | QFN-20_L5.0-W5.0-P0.80-TL-EP2.8 | 1 | SI3402-B-GMR |  |  | 2 |  | x |  |  |  | SI3402-B-GMR | SILICON LABS | 2 | $2.96 | $5.93 | C510771 | QFN-20-EP(5x5) | 1 | 1 | 2500 | 91 | In Stock |  | 37V~57V QFN-20-EP(5x5) Drivers, Receivers, Transceivers RoHS | Exact Matches | https://www.lcsc.com/product-detail/C510771.html |  |  |  |  |  |  |  |  |  |  |  |  |  |  |  |  |  |  |  |
| 35 | U7 | TSOT-23 | 1 | TLV431 |  |  | 2 |  | x |  |  |  | TLV431BQDBZR | TI | 5 | $0.23 | $1.16 | C398374 | SOT-23-3 | 5 | 5 | 3000 | 11190 | In Stock |  | 1.24V~6V �0.5% 1.24V~6V 15mA Adjustable SOT-23-3 Voltage Reference RoHS | Exact Matches | https://www.lcsc.com/product-detail/C398374.html |  |  |  |  |  |  |  |  |  |  |  |  |  |  |  |  |  |  |  |
| 40 | Y1 | Crystal_SMD_3225-4Pin_3.2x2.5mm | 1 | ABM8-272-T3 |  |  | 2 |  | x |  |  |  | ABM8-272-T3 | ABRACON | 5 | $0.33 | $1.64 | C20625731 | SMD3225-4P | 5 | 5 | 3000 | 0 | Backordered |  | �30ppm 10pF �30ppm SMD3225-4P Crystals RoHS | Exact Matches | https://www.lcsc.com/product-detail/C20625731.html |  |  |  |  |  |  |  |  |  |  |  |  |  |  |  |  |  |  |  |
| 23 | Y2 | Crystal_SMD_3225-4Pin_3.2x2.5mm | 1 | ABM8-25.000MHZ-10-D1G-T |  |  | 2 |  | x |  |  |  | ABM8-25.000MHZ-10-D1G-T | ABRACON | 2 | $0.84 | $1.68 | C5366868 | SMD3225-4P | 1 | 1 | 1000 | 436 | In Stock |  | �15ppm 10pF �10ppm SMD3225-4P Crystals RoHS | Exact Matches | https://www.lcsc.com/product-detail/C5366868.html |  |  |  |  |  |  |  |  |  |  |  |  |  |  |  |  |  |  |  |
| Id | Designator | Footprint | Quantity | Designation | Supplier and ref | Column1 | Needed quantity | - | LCSC | MOUSER | Already in another pcb | -- | Mrf# | Mfr. | Order Qty. | Unit Price(USD) | Ext.Price(USD) | LCSC#/MOUSER | Package | Min | Mult | SPQ | Availability | Stock Status | Customer Notes | Description | Matched status | Product Link |  |  |  |  |  |  |  |  |  |  |  |  |  |  |  |  |  |  |  |
| 5 | C1 | C_0603_1608Metric | 1 | 4u7 |  |  | 2 |  |  |  | x |  |  |  |  |  |  |  |  |  |  |  |  |  |  |  |  |  |  |  |  |  |  |  |  |  |  |  |  |  |  |  |  |  |  |  |  |
| 8 | C2 | C_0603_1608Metric | 1 | 100n |  |  | 2 |  |  |  | x |  |  |  |  |  |  |  |  |  |  |  |  |  |  |  |  |  |  |  |  |  |  |  |  |  |  |  |  |  |  |  |  |  |  |  |  |
| 4 | J1 | FPC-SMD_5034801200 | 1 | Conn_01x12_MountingPin |  |  | 2 |  | x |  |  |  | 5034801200 | MOLEX | 5 | $0.36 | $1.78 | C587969 | SMD,P=0.5mm,Surface Mount,Right Angle | 5 | 5 | 3000 | 19735 | In Stock |  | FFC/FPC Connector 12 Position 0.5mm Pitch Double-Sided Contacts, Top and Bottom Entry Surface Mount, Right Angle -40?~+85? | Exact Matches | https://www.lcsc.com/product-detail/C587969.html |  |  |  |  |  |  |  |  |  |  |  |  |  |  |  |  |  |  |  |
| 9 | J2 | IDC-Header_2x06_P2.54mm_Vertical | 1 | IDC |  |  | 2 |  |  |  | x |  |  |  |  |  |  |  |  |  |  |  |  |  |  |  |  |  |  |  |  |  |  |  |  |  |  |  |  |  |  |  |  |  |  |  |  |
| 3 | Q2 | SOT-23 | 1 | BSS138 |  |  | 2 |  | x |  |  |  | BSS138LT1G | onsemi | 10 | $0.04 | $0.41 | C82045 | SOT-23 | 10 | 10 | 3000 | 267340 | In Stock |  | N-Channel 50V 200mA 225mW Surface Mount SOT-23 | Exact Matches | https://www.lcsc.com/product-detail/C82045.html |  |  |  |  |  |  |  |  |  |  |  |  |  |  |  |  |  |  |  |
| 7 | R1 | R_0603_1608Metric | 1 | 10R |  |  | 2 |  |  |  | x |  |  |  |  |  |  |  |  |  |  |  |  |  |  |  |  |  |  |  |  |  |  |  |  |  |  |  |  |  |  |  |  |  |  |  |  |
| 2 | R2,R4,R3 | R_0603_1608Metric | 3 | 10k |  |  | 6 |  |  |  | x |  |  |  |  |  |  |  |  |  |  |  |  |  |  |  |  |  |  |  |  |  |  |  |  |  |  |  |  |  |  |  |  |  |  |  |  |
| 1 | SW2 | RotaryEncoder_Alps_EC11E-Switch_Vertical_H20mm | 1 | EC11E18244AU |  |  | 2 |  | x |  |  |  | EC11E18244AU | ALPSALPINE | 2 | $2.12 | $4.23 | C202365 | Through Hole | 1 | 1 | 120 | 2382 | In Stock |  | Through Hole Encoders RoHS | Exact Matches | https://www.lcsc.com/product-detail/C202365.html |  |  |  |  |  |  |  |  |  |  |  |  |  |  |  |  |  |  |  |
| 6 | U1 | SOT-23 | 1 | APX803S-31SA-7 |  |  | 2 |  | x |  |  |  | APX803S-31SA-7 | DIODES | 5 | $0.18 | $0.90 | C129757 | SOT-23 | 5 | 5 | 3000 | 4525 | In Stock |  | 240ms Active Low 1V~5.5V 1 SOT-23 Supervisors RoHS | Exact Matches | https://www.lcsc.com/product-detail/C129757.html |  |  |  |  |  |  |  |  |  |  |  |  |  |  |  |  |  |  |  |
| Id | Designator | Footprint | Quantity | Designation | Supplier and ref | Column1 | Needed quantity | - | LCSC | MOUSER | Already in another pcb | -- | Mrf# | Mfr. | Order Qty. | Unit Price(USD) | Ext.Price(USD) | LCSC#/MOUSER | Package | Min | Mult | SPQ | Availability | Stock Status | Customer Notes | Description | Matched status | Product Link |  |  |  |  |  |  |  |  |  |  |  |  |  |  |  |  |  |  |  |
| 6 | C1 | C_0603_1608Metric | 1 | 10u |  |  | 2 |  | x |  |  |  | CL10B106MQ8NRNC | Samsung Electro-Mechanics | 2 | $0.08 | $0.15 | C3039698 | 603 | 2 | 2 | 4000 | 25412 | In Stock |  | 10uF �20% 6.3V Ceramic Capacitor X7R 0603 | Exact Matches | https://www.lcsc.com/product-detail/C3039698.html |  |  |  |  |  |  |  |  |  |  |  |  |  |  |  |  |  |  |  |
| 7 | C10,C9 | C_0402_1005Metric | 2 | 14p |  |  | 4 |  | x |  |  |  | 0402CG140J500NT | FH | 100 | $0.00 | $0.16 | C3037644 | 402 | 100 | 100 | 10000 | 41300 | In Stock |  | 14pF �5% 50V Ceramic Capacitor C0G 0402 | Exact Matches | https://www.lcsc.com/product-detail/C3037644.html |  |  |  |  |  |  |  |  |  |  |  |  |  |  |  |  |  |  |  |
| 1 | C2,C4,C5,C3,C6 | C_0402_1005Metric | 5 | 100n |  |  | 10 |  |  |  | x |  |  |  |  |  |  |  |  |  |  |  |  |  |  |  |  |  |  |  |  |  |  |  |  |  |  |  |  |  |  |  |  |  |  |  |  |
| 5 | C7,C8 | C_0402_1005Metric | 2 | 3p |  |  | 4 |  | x |  |  |  | CC0402BRNPO9BN3R0 | YAGEO | 100 | $0.00 | $0.26 | C327228 | 402 | 100 | 100 | 10000 | 17400 | In Stock |  | 3pF 50V Ceramic Capacitor NP0 0402 | Exact Matches | https://www.lcsc.com/product-detail/C327228.html |  |  |  |  |  |  |  |  |  |  |  |  |  |  |  |  |  |  |  |
| 9 | J1 | U.FL_Molex_MCRF_73412-0110_Vertical | 1 | Conn_01x01_Shielded |  |  | 2 |  | x |  |  |  | 734120110 | MOLEX | 2 | $0.62 | $1.25 | C434806 | SMD | 1 | 1 | 5000 | 279 | In Stock |  | Connector Receptacle IPEX Male Pin Surface Mount | Exact Matches | https://www.lcsc.com/product-detail/C434806.html |  |  |  |  |  |  |  |  |  |  |  |  |  |  |  |  |  |  |  |
| 11 | J2 | PinHeader_2x04_P2.54mm_Vertical | 1 | Conn_02x04 |  |  | 2 |  | x |  |  |  | PZ254V-12-8P | XFCN | 10 | $0.04 | $0.40 | C492421 | Through Hole,P=2.54mm | 10 | 10 | 1000 | 148950 | In Stock |  | Pin Header 8 Position 2.54mm Pitch Dual Row Through Hole -40?~+105? | Exact Matches | https://www.lcsc.com/product-detail/C492421.html |  |  |  |  |  |  |  |  |  |  |  |  |  |  |  |  |  |  |  |
| 3 | L1 | L_0402_1005Metric | 1 | 2n |  |  | 2 |  | x |  |  |  | MLG1005S2N0BT000 | TDK | 10 | $0.01 | $0.09 | C76769 | 402 | 10 | 10 | 10000 | 67470 | In Stock |  | 900mA 2nH 70m? Multilayer inductor 0402 Fixed Inductors RoHS | Exact Matches | https://www.lcsc.com/product-detail/C76769.html |  |  |  |  |  |  |  |  |  |  |  |  |  |  |  |  |  |  |  |
| 4 | R1 | R_0402_1005Metric | 1 | 10k |  |  | 2 |  | x |  |  |  | RC0402FR-0710KL | YAGEO | 100 | $0.00 | $0.08 | C60490 | 402 | 100 | 100 | 10000 | 5173500 | In Stock |  | 62.5mW 10k? 50V Thick Film Resistor �100ppm/? �1% 0402 Chip Resistor - Surface Mount RoHS | Exact Matches | https://www.lcsc.com/product-detail/C60490.html |  |  |  |  |  |  |  |  |  |  |  |  |  |  |  |  |  |  |  |
| 2 | TP2,TP1 | TestPoint_Pad_D1.0mm | 2 | TestPoint |  |  | 4 |  |  |  |  |  |  |  |  |  |  |  |  |  |  |  |  |  |  |  |  |  |  |  |  |  |  |  |  |  |  |  |  |  |  |  |  |  |  |  |  |
| 8 | U1 | QFN-24-1EP_4x4mm_P0.5mm_EP2.8x2.8mm | 1 | ESP8684 |  |  | 2 |  | x |  |  |  | ESP8684H4X | ESPRESSIF | 2 | $1.54 | $3.08 | C48929155 | QFN-24(4x4) | 1 | 1 | 5000 | 4843 | In Stock |  | QFN-24(4x4) RF Transceiver ICs RoHS | Exact Matches | https://www.lcsc.com/product-detail/C48929155.html |  |  |  |  |  |  |  |  |  |  |  |  |  |  |  |  |  |  |  |
| 10 | Y1 | Crystal_SMD_SeikoEpson_FA128-4Pin_2.0x1.6mm | 1 | Q22FA12800230 |  |  | 2 |  |  |  |  |  | Q22FA12800230 | EPSON | 5 | $0.33 | $1.63 | C255886 | SMD2016-4P | 5 | 5 | 3000 | 1585 | In Stock |  | Crystal 26MHz �10ppm 10pF 60? SMD2016-4P | Exact Matches | https://www.lcsc.com/product-detail/C255886.html |  |  |  |  |  |  |  |  |  |  |  |  |  |  |  |  |  |  |  |
| x | x | x | 1 | IDC interconnect cable |  |  | 2 |  | x |  |  |  | IDC-265126-200-12P | DEALON | 2 | $0.30 | $0.60 | C7465811 | - | 1 | 1 | 250 | 119 | In Stock |  | Wire Wrap RoHS | Exact Matches | https://www.lcsc.com/product-detail/C7465811.html |  |  |  |  |  |  |  |  |  |  |  |  |  |  |  |  |  |  |  |
| x | x | x | 1 | 2 Inch 240x320 lcd display |  |  | 2 |  | x |  |  |  | HS20HS072RX | HS | 2 | $3.46 | $6.93 | C5329582 | - | 1 | 1 | 1 | 242 | In Stock |  | 2 320x240 ST7789 SPI LCD, OLED, Graphic RoHS | Exact Matches | https://www.lcsc.com/product-detail/C5329582.html |  |  |  |  |  |  |  |  |  |  |  |  |  |  |  |  |  |  |  |
|  |  |  |  | PKCELL Li-Po Battery 3.7V 2000mAh |  |  | 2 |  |  |  |  |  | Li-Po Battery 3.7V 2000mAh - JST-PH - LP803860 | PKCELL | 2 | $8.69 | $17.37 |  |  |  |  |  |  |  |  | Li-Po Battery 3.7V 2000mAh - JST-PH - LP803860 |  | https://www.tinytronics.nl/en/power/batteries/li-po/pkcell-li-po-battery-3.7v-2000mah-jst-ph-lp803860 |  |  |  |  |  |  |  |  |  |  |  |  |  |  |  |  |  |  |  |
|  |  |  |  |  |  |  |  |  |  |  |  |  | JLCPCB Main PCB inc. Stencil |  |  |  | $14.11 |  |  |  |  |  |  |  |  |  |  |  |  |  |  |  |  |  |  |  |  |  |  |  |  |  |  |  |  |  |  |
|  |  |  |  |  |  |  |  |  |  |  |  |  | JLCPCB WIFI PCB inc. Stencil |  |  |  | $5.05 |  |  |  |  |  |  |  |  |  |  |  |  |  |  |  |  |  |  |  |  |  |  |  |  |  |  |  |  |  |  |
|  |  |  |  |  |  |  |  |  |  |  |  |  | JLCPCB Display PCB inc. Stencil |  |  |  | $7.05 |  |  |  |  |  |  |  |  |  |  |  |  |  |  |  |  |  |  |  |  |  |  |  |  |  |  |  |  |  |  |
|  |  |  |  |  |  |  |  |  |  |  |  |  | shipping LCSC |  |  |  | $14.87 |  |  |  |  |  |  |  |  |  |  |  |  |  |  |  |  |  |  |  |  |  |  |  |  |  |  |  |  |  |  |
|  |  |  |  |  |  |  |  |  |  |  |  |  | Shipping JLCPCB |  |  |  | $14.89 |  |  |  |  |  |  |  |  |  |  |  |  |  |  |  |  |  |  |  |  |  |  |  |  |  |  |  |  |  |  |
|  |  |  |  |  |  |  |  |  |  |  |  |  | Shipping Tinytronics |  |  |  | $6.90 |  |  |  |  |  |  |  |  |  |  |  |  |  |  |  |  |  |  |  |  |  |  |  |  |  |  |  |  |  |  |
|  |  |  |  |  |  |  |  |  |  |  |  |  | Shipping Mouser |  |  |  | $- |  |  |  |  |  |  |  |  |  |  |  |  |  |  |  |  |  |  |  |  |  |  |  |  |  |  |  |  |  |  |
|  |  |  |  |  |  |  |  |  |  |  |  |  | Total |  |  |  | $269.39 |  |  |  |  |  |  |  |  |  |  |  |  |  |  |  |  |  |  |  |  |  |  |  |  |  |  |  |  |  |  |

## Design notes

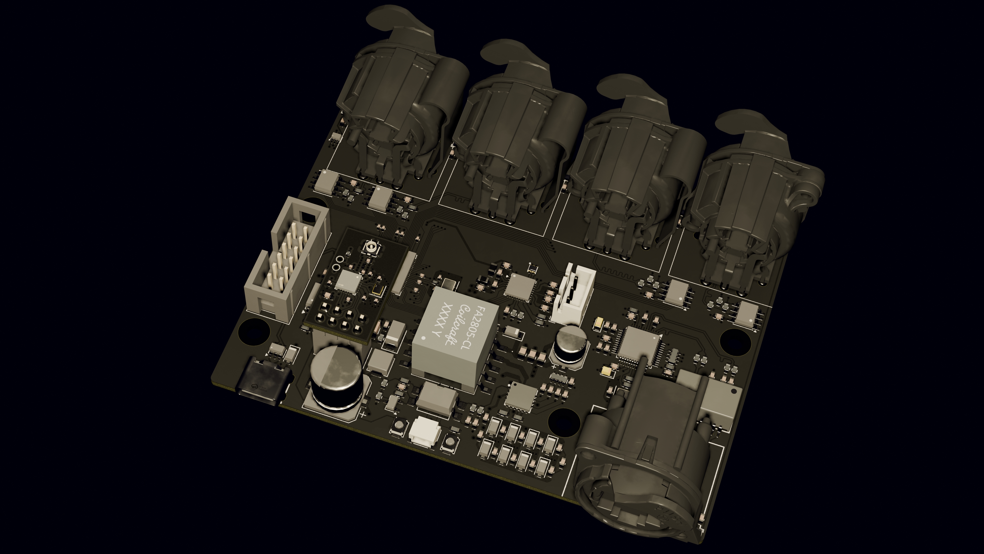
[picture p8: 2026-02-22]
3D/GrandNA3_4Port_Node.jpg

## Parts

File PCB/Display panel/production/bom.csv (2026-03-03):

Designator | Footprint | Quantity | Value | LCSC Part #
C1 | 0603 | 1 | 4u7
C2 | 0603 | 1 | 100n
J1 | FPC-SMD_5034801200 | 1 | Conn_01x12_MountingPin
J2 | IDC-Header_2x06_P2.54mm_Vertical | 1 | IDC
Q2 | SOT-23 | 1 | BSS138
R1 | 0603 | 1 | 10R
R2, R3, R4 | 0603 | 3 | 10k
SW2 | RotaryEncoder_Alps_EC11E-Switch_Vertical_H20mm | 1 | EC11E18244AU
U1 | SOT-23 | 1 | APX803S-31SA-7 | C129757

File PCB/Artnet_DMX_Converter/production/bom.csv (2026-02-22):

Designator | Footprint | Quantity | Value | LCSC Part #
BT1 | JST_XH_B3B-XH-A_1x03_P2.50mm_Vertical | 1 | Battery_Cell
C1, C10, C11, C12, C13, C3, C4, C5, C6, C7, C8, C9 | 0402 | 12 | 100n
C14, C15, C16 | 0402 | 3 | 4.7u
C17, C19 | 0402 | 2 | 15p
C18, C25, C26, C27, C28, C29, C30, C31, C42, C43, C45, C60, C61, C64, C66, C67, C68, C69, C70, C71, C72, C73, C74, C75, C76, C77, C78, C79, C88 | 0603 | 29 | 100n
C2 | 0402 | 1 | 4u7
C20, C21, C23, C33, C57 | 0603 | 5 | 10n
C22, C34, C35, C36, C37, C38, C39, C40, C41, C47, C63, C65 | 0603 | 12 | 1n
C24, C32 | CP_EIA-2012-12_Kemet-R | 2 | 10u
C44, C46 | 0603 | 2 | 6.8n
C48, C49 | 0603 | 2 | 10p
C50, C51, C52 | 0805 | 3 | 1u
C53 | CP_Elec_6.3x5.8 | 1 | 12u
C54 | 0603 | 1 | 470p
C55 | CP_Elec_10x10.5 | 1 | 1000u
C56 | 1206 | 1 | 100u
C58 | 0603 | 1 | 4u7
C59 | 0603 | 1 | 3.3n
C62 | 0603 | 1 | 15n
C80, C81 | 0603 | 2 | 1u
C82, C83, C84, C86, C87 | 0603 | 5 | 10u
C85 | 0603 | 1 | 2u2
D1 | D_SOD-123F | 1 | DSK24L
D10 | D_SMA | 1 | SS34
D11 | D_SOD-123 | 1 | 1N4148W
D12 | D_SOD-123F | 1 | DFTL30A
D13 | LED-SMD_4P-L1.6-W1.5-TR | 1 | LED_ABGR
D2, D3, D4, D5, D6, D7, D8, D9 | D_SOD-123F | 8 | SL110PL-TP
IC1 | QFN-32-1EP_5x5mm_P0.5mm_EP3.45x3.45mm_ThermalVias | 1 | NPM1300-QEAA-R7
J1 | JST_SH_SM03B-SRSS-TB_1x03-1MP_P1.00mm_Horizontal | 1 | Conn_01x03_MountingPin
J10, J4, J6, J8 | NC5FAH1-LR-DAE | 4 | XLR5
J11, J5, J7, J9 | NC3FAH2-LR-DAE | 4 | XLR3
J12 | IDC-Header_2x06_P2.54mm_Vertical | 1 | IDC
J13 | PinSocket_2x04_P2.54mm_Vertical | 1 | Conn_02x04
J2 | USB-C_SMD-TYPE-C-31-M-12_1 | 1 | USB_C_Receptacle_USB2.0_14P
J3 | NE8FAHLRDAE | 1 | RJ45
L1 | IND-SMD_L2.0-W1.6_AOTA-B201610S3R3-101-T | 1 | 3.3u
L2 | L_Vishay_IHLP-1616 | 1 | 1u
L3 | XFMR-SMD_16P-L12.7-W7.1-P1.27-LS9.4-BL | 1 | H2019NLT | C110250
L4, L5 | 0805 | 2 | 2u2
LED1, LED10, LED2, LED3, LED4, LED5, LED6, LED7, LED8, LED9 | LED-SMD_4P-L1.5-W1.5-BL | 10 | SK6805-EC15 | C2890035
R1, R27, R3 | 0603 | 3 | 1k
R11, R42, R43, R7 | 0603 | 4 | 10k
R12, R13, R14, R15 | 0603 | 4 | 33R
R16 | 0603 | 1 | 1M
R17, R22, R23, R8 | 0603 | 4 | 0R
R18 | 0603 | 1 | 10R
R19 | 0603 | 1 | 12.4k
R2 | 0402 | 1 | 33R
R20 | 0603 | 1 | 4.99k
R21 | 0603 | 1 | 2.05k
R24 | 0603 | 1 | 36.5k
R25 | 0603 | 1 | 12.1k
R26 | 0603 | 1 | 24.9k
R28, R29, R30, R31, R36, R37, R38, R39 | 0603 | 8 | 348R
R32, R33, R34, R35 | 0603 | 4 | 133R
R4, R5 | 0402 | 2 | 27R
R40, R41 | 0603 | 2 | 430k
R6 | 0402 | 1 | 1k
RN1, RN2 | R_Array_Concave_4x0603 | 2 | 75R
RN3 | R_Array_Concave_4x0603 | 1 | 10k
SW1, SW2 | SW_SPST_B3U-1000P | 2 | SW_Push
T1 | FA2924ALD | 1 | FA2805
U1 | QFN-80-1EP_10x10mm_P0.4mm_EP3.4x3.4mm | 1 | RP2350B
U10, U11, U8, U9 | SOIC-8_3.9x4.9mm_P1.27mm | 4 | MAX3485
U12 | SOT-363_SC-70-6 | 1 | TXS0101DCK
U2 | SOIC-8_5.3x5.3mm_P1.27mm | 1 | W25Q128JVS
U3 | SOT-23-6 | 1 | USBLC6-2SC6
U4 | LQFP-48_7x7mm_P0.5mm | 1 | W5500
U5 | SMDIP-4_W9.53mm_Clearance8mm | 1 | VO618A-3X019T
U6 | QFN-20_L5.0-W5.0-P0.80-TL-EP2.8 | 1 | SI3402-B-GMR | C510771
U7 | TSOT-23 | 1 | TLV431
Y1 | Crystal_SMD_3225-4Pin_3.2x2.5mm | 1 | ABM8-272-T3
Y2 | Crystal_SMD_3225-4Pin_3.2x2.5mm | 1 | ABM8-25.000MHZ-10-D1G-T

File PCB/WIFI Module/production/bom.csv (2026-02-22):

Designator | Footprint | Quantity | Value | LCSC Part #
C1 | 0603 | 1 | 10u
C10, C9 | 0402 | 2 | 14p
C2, C3, C4, C5, C6 | 0402 | 5 | 100n
C7, C8 | 0402 | 2 | 3p
J1 | U.FL_Molex_MCRF_73412-0110_Vertical | 1 | Conn_01x01_Shielded
J2 | PinHeader_2x04_P2.54mm_Vertical | 1 | Conn_02x04
L1 | 0402 | 1 | 2n
R1 | 0402 | 1 | 10k
TP1, TP2 | TestPoint_Pad_D1.0mm | 2 | TestPoint
U1 | QFN-24-1EP_4x4mm_P0.5mm_EP2.8x2.8mm | 1 | ESP8684
Y1 | Crystal_SMD_SeikoEpson_FA128-4Pin_2.0x1.6mm | 1 | Q22FA12800230

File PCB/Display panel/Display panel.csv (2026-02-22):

Id | Designator | Footprint | Quantity | Designation | Supplier and ref
1 | SW2 | RotaryEncoder_Alps_EC11E-Switch_Vertical_H20mm | 1 | EC11E18244AU
2 | R2,R4,R3 | R_0603_1608Metric | 3 | 10k
3 | Q2 | SOT-23 | 1 | BSS138
4 | J1 | FPC-SMD_5034801200 | 1 | Conn_01x12_MountingPin
5 | C1 | C_0603_1608Metric | 1 | 4u7
6 | U1 | SOT-23 | 1 | APX803S-31SA-7
7 | R1 | R_0603_1608Metric | 1 | 10R
8 | C2 | C_0603_1608Metric | 1 | 100n
9 | J2 | IDC-Header_2x06_P2.54mm_Vertical | 1 | IDC

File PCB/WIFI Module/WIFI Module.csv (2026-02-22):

Id | Designator | Footprint | Quantity | Designation | Supplier and ref
1 | C2,C4,C5,C3,C6 | C_0402_1005Metric | 5 | 100n
2 | TP2,TP1 | TestPoint_Pad_D1.0mm | 2 | TestPoint
3 | L1 | L_0402_1005Metric | 1 | 2n
4 | R1 | R_0402_1005Metric | 1 | 10k
5 | C7,C8 | C_0402_1005Metric | 2 | 3p
6 | C1 | C_0603_1608Metric | 1 | 10u
7 | C10,C9 | C_0402_1005Metric | 2 | 14p
8 | U1 | QFN-24-1EP_4x4mm_P0.5mm_EP2.8x2.8mm | 1 | ESP8684
9 | J1 | U.FL_Molex_MCRF_73412-0110_Vertical | 1 | Conn_01x01_Shielded
10 | Y1 | Crystal_SMD_SeikoEpson_FA128-4Pin_2.0x1.6mm | 1 | Q22FA12800230
11 | J2 | PinHeader_2x04_P2.54mm_Vertical | 1 | Conn_02x04

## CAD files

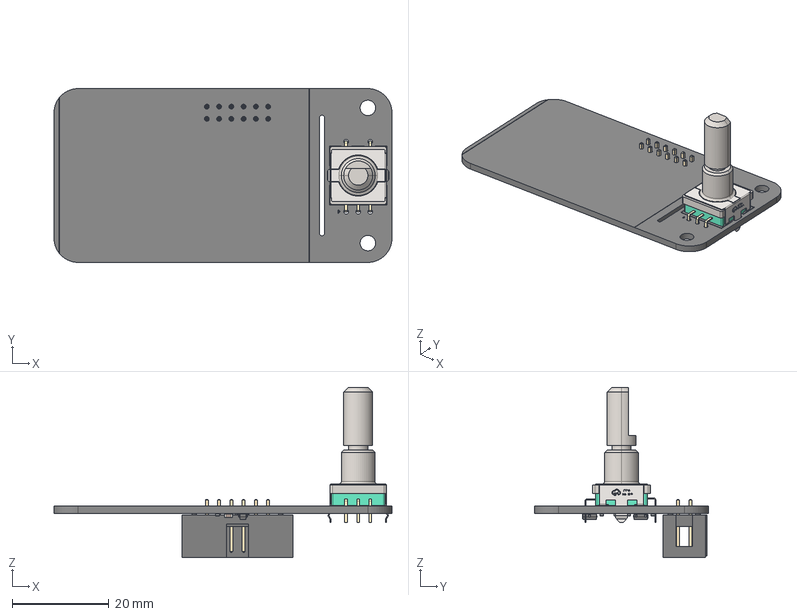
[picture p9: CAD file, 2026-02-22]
PCB/Display panel/Display panel.step
70.0 x 36.0 x 35.3 mm
SW-TH_EC11XXXXXXXX-L11.7-W12.0-H24.5-P2.5-LS14.5
R_0603_1608Metric x 4
SOT-23 x 2
C_0603_1608Metric x 2
IDC-Header_2x06_P2.54mm_Vertical
Display panel_silkscreen x 2
Display panel_PCB

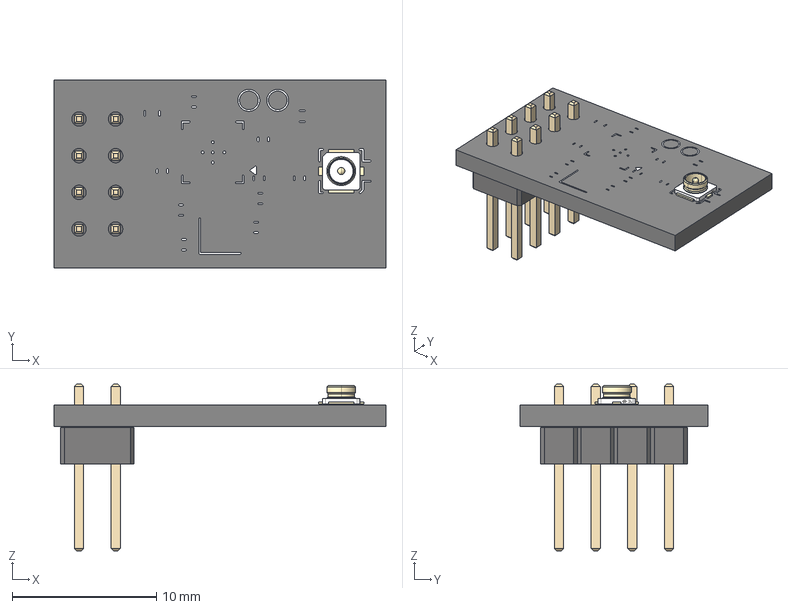
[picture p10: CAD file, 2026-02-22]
PCB/WIFI Module/WIFI Module.step
23.0 x 13.0 x 11.5 mm
ANT-SMD_73412-0110
PinHeader_2x04_P2.54mm_Vertical
WIFI Module_silkscreen x 2
WIFI Module_PCB

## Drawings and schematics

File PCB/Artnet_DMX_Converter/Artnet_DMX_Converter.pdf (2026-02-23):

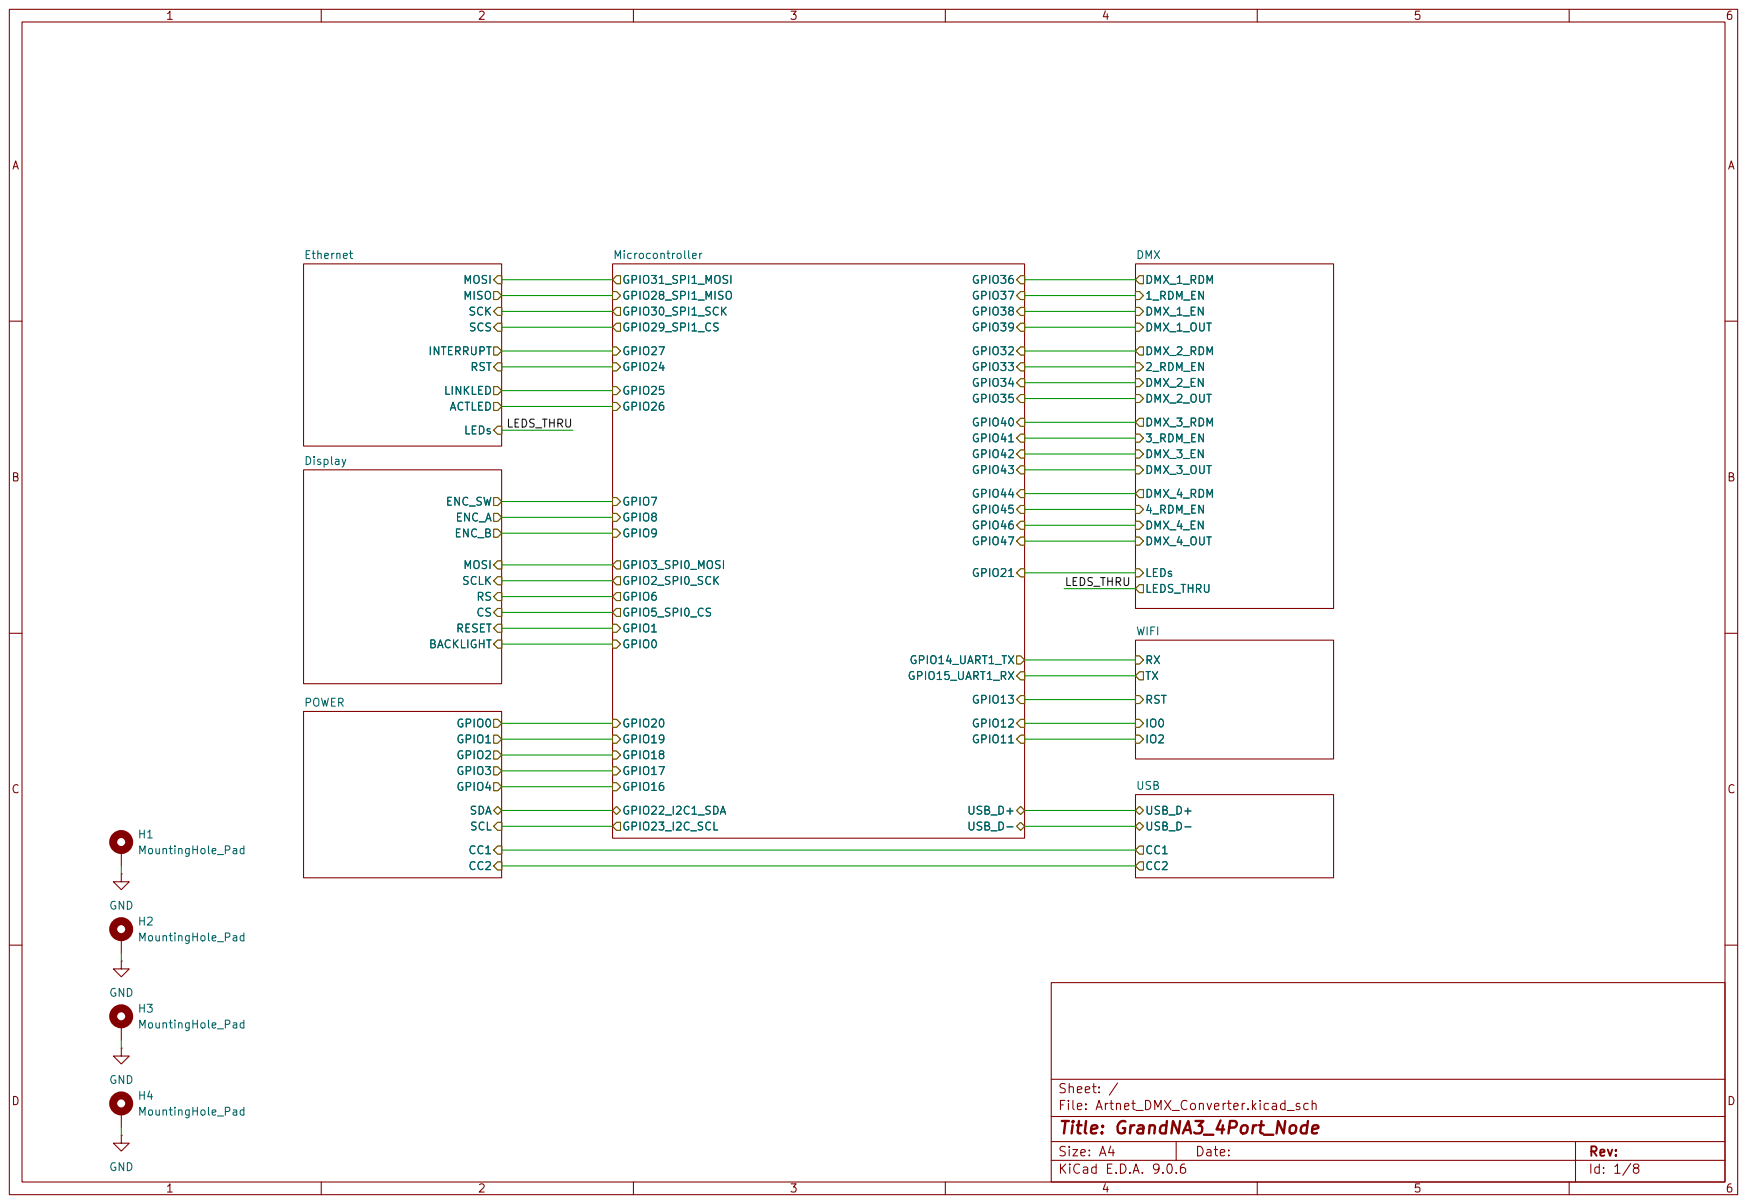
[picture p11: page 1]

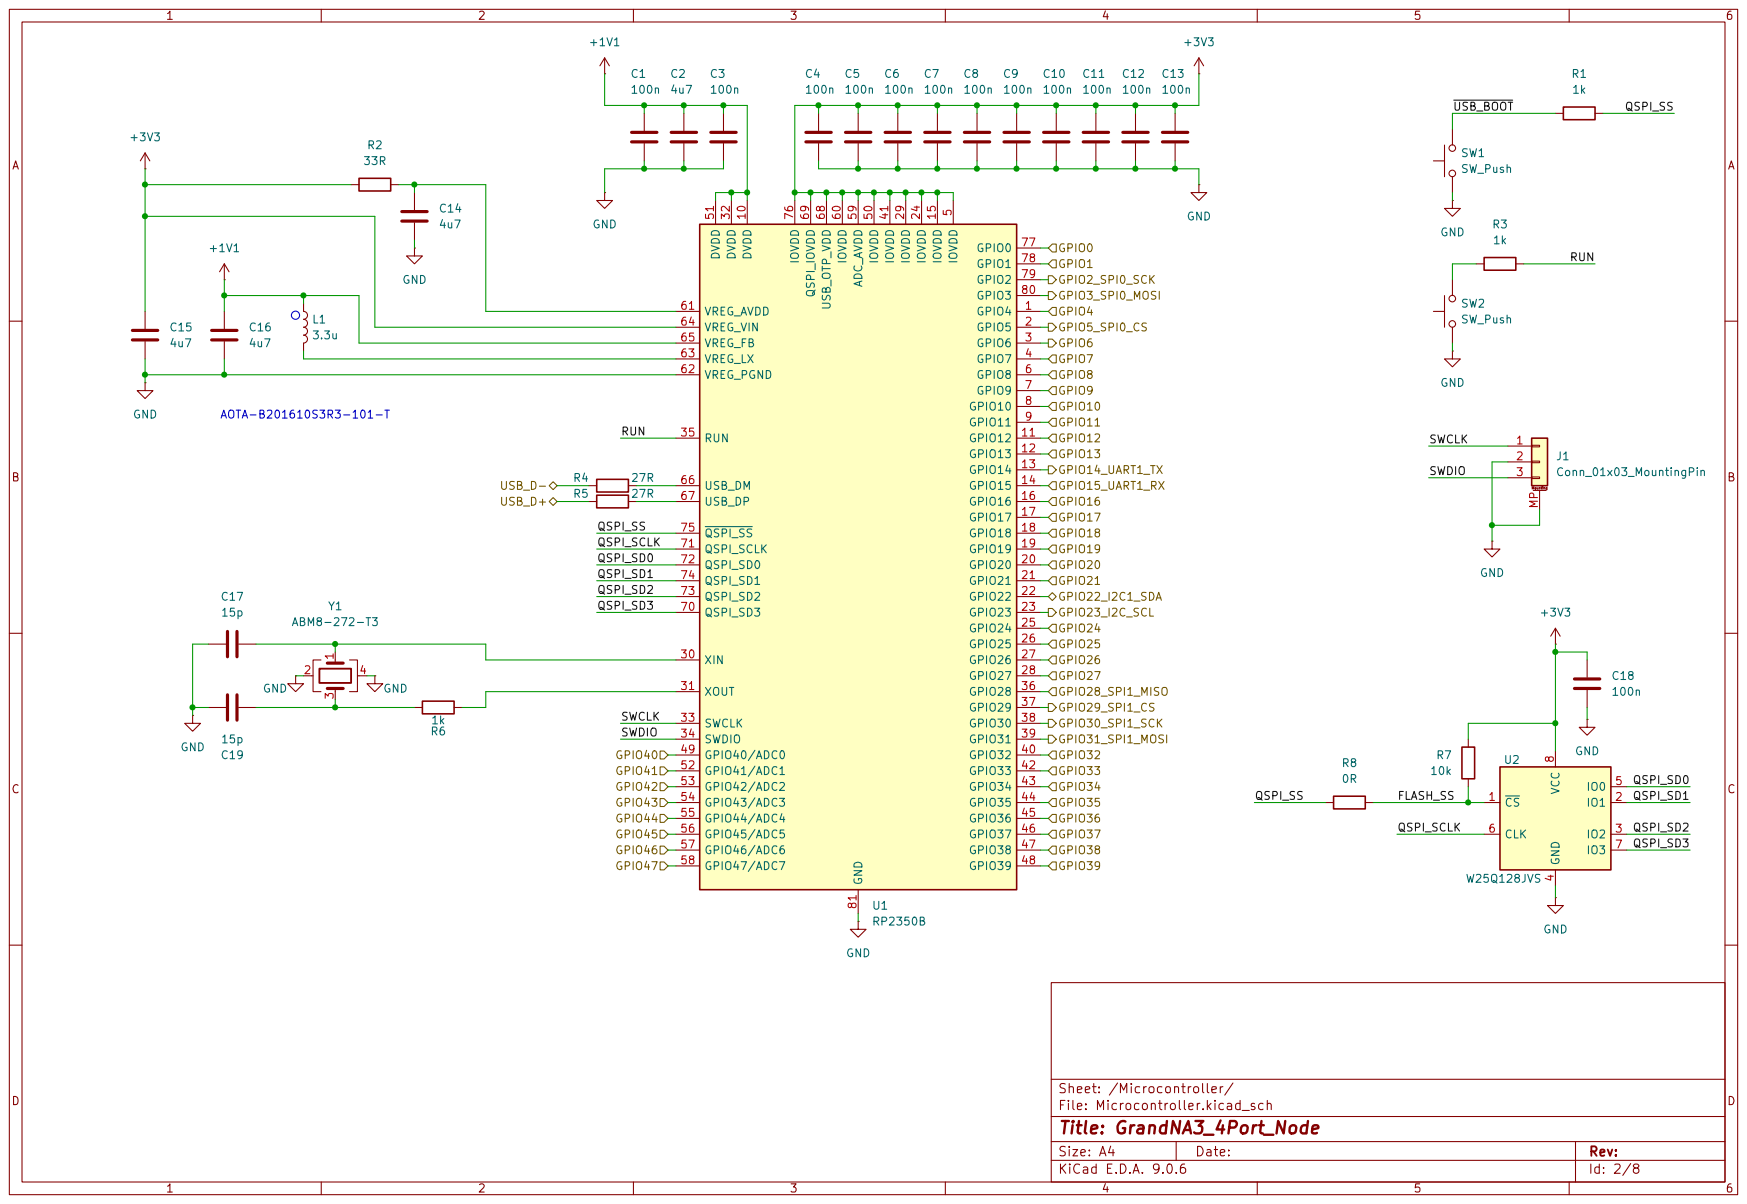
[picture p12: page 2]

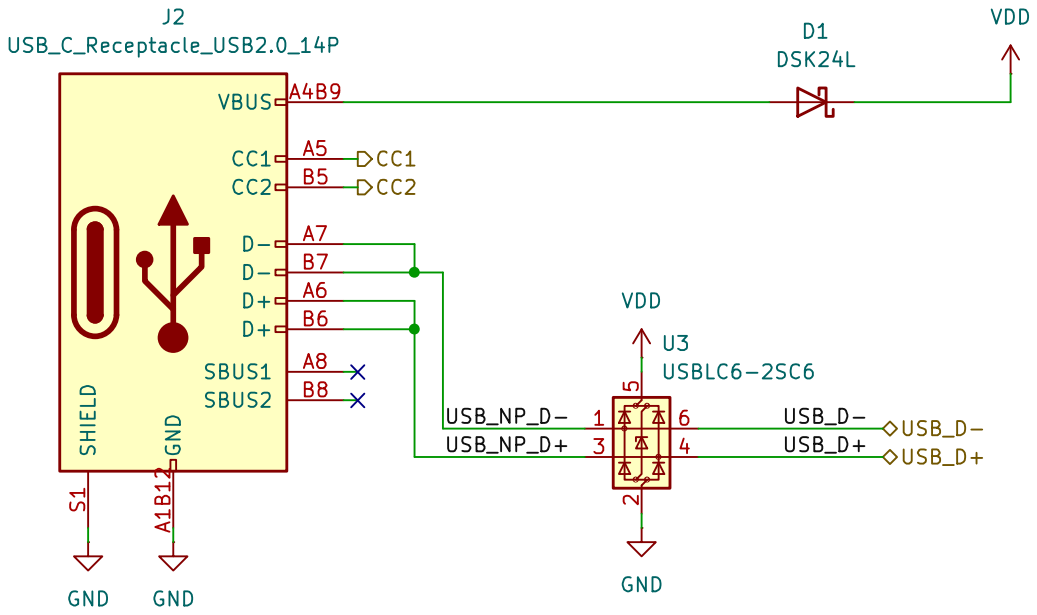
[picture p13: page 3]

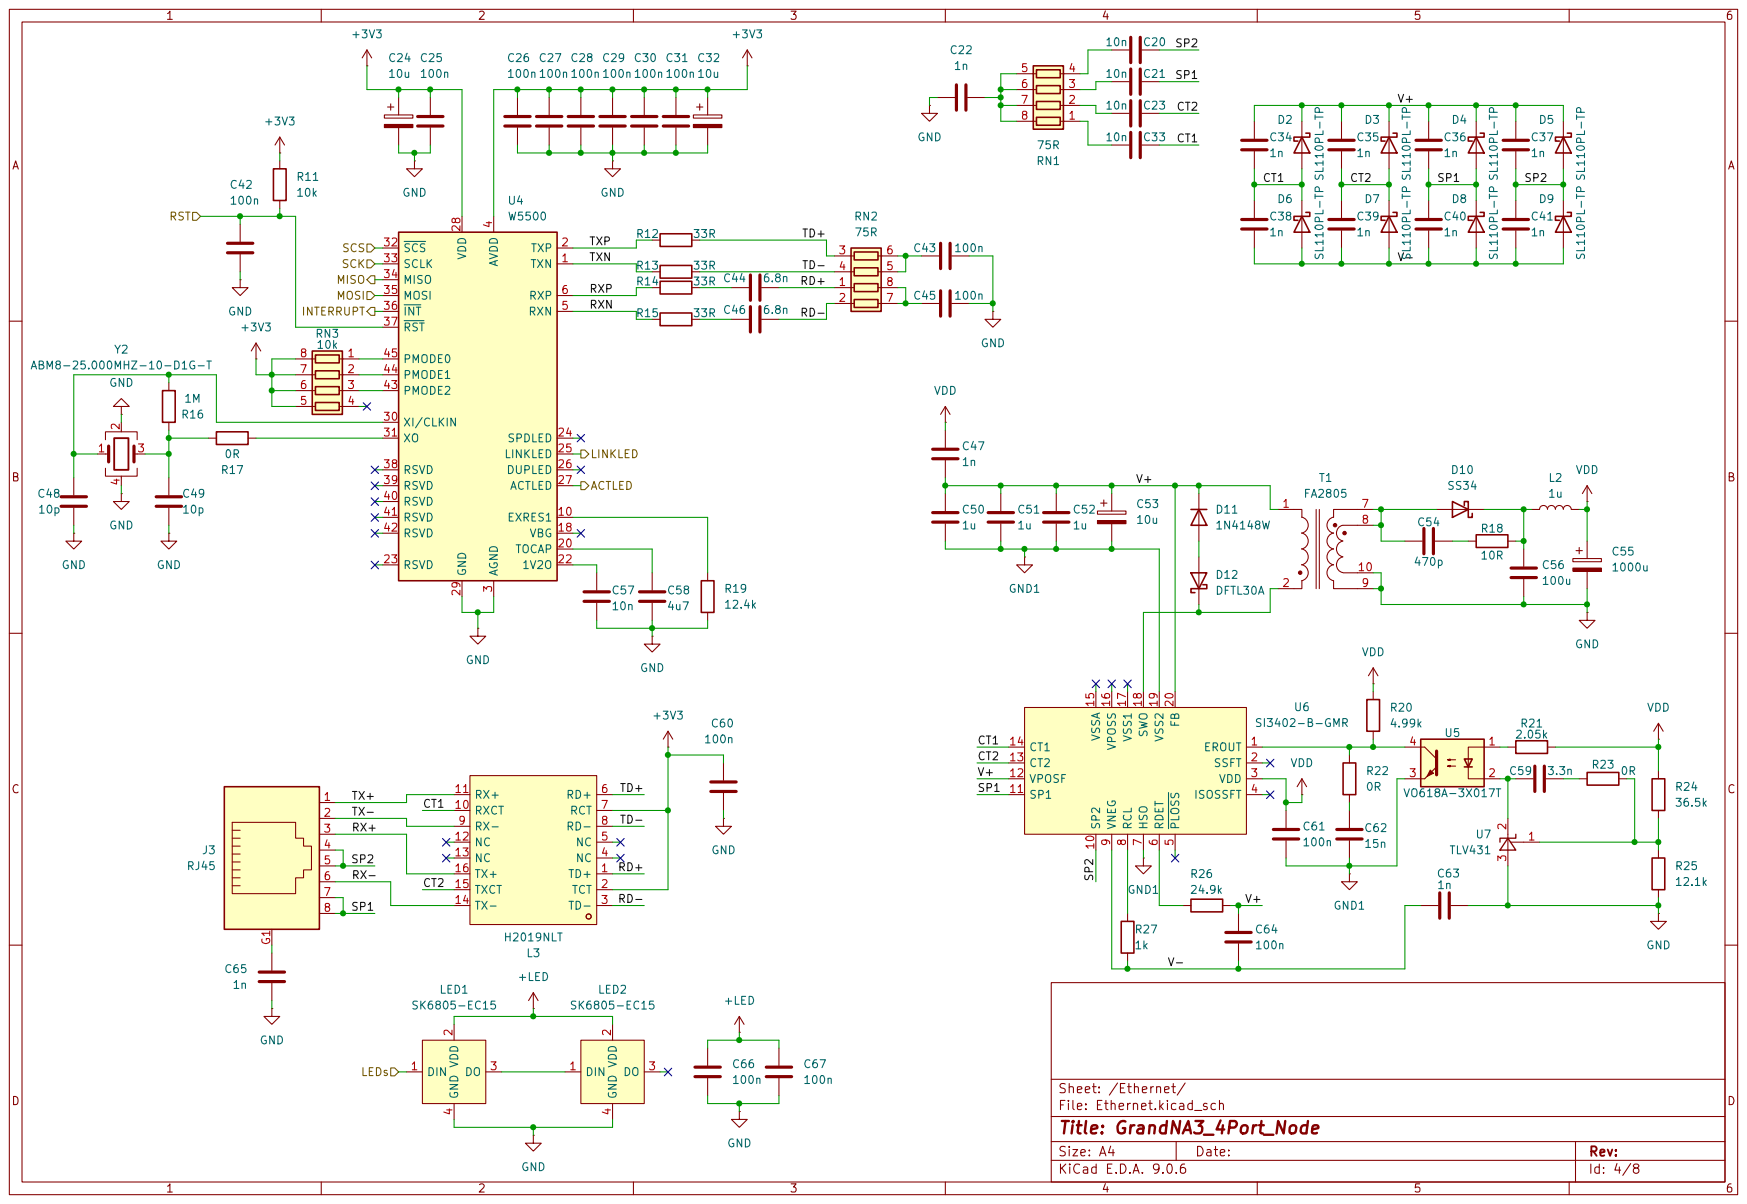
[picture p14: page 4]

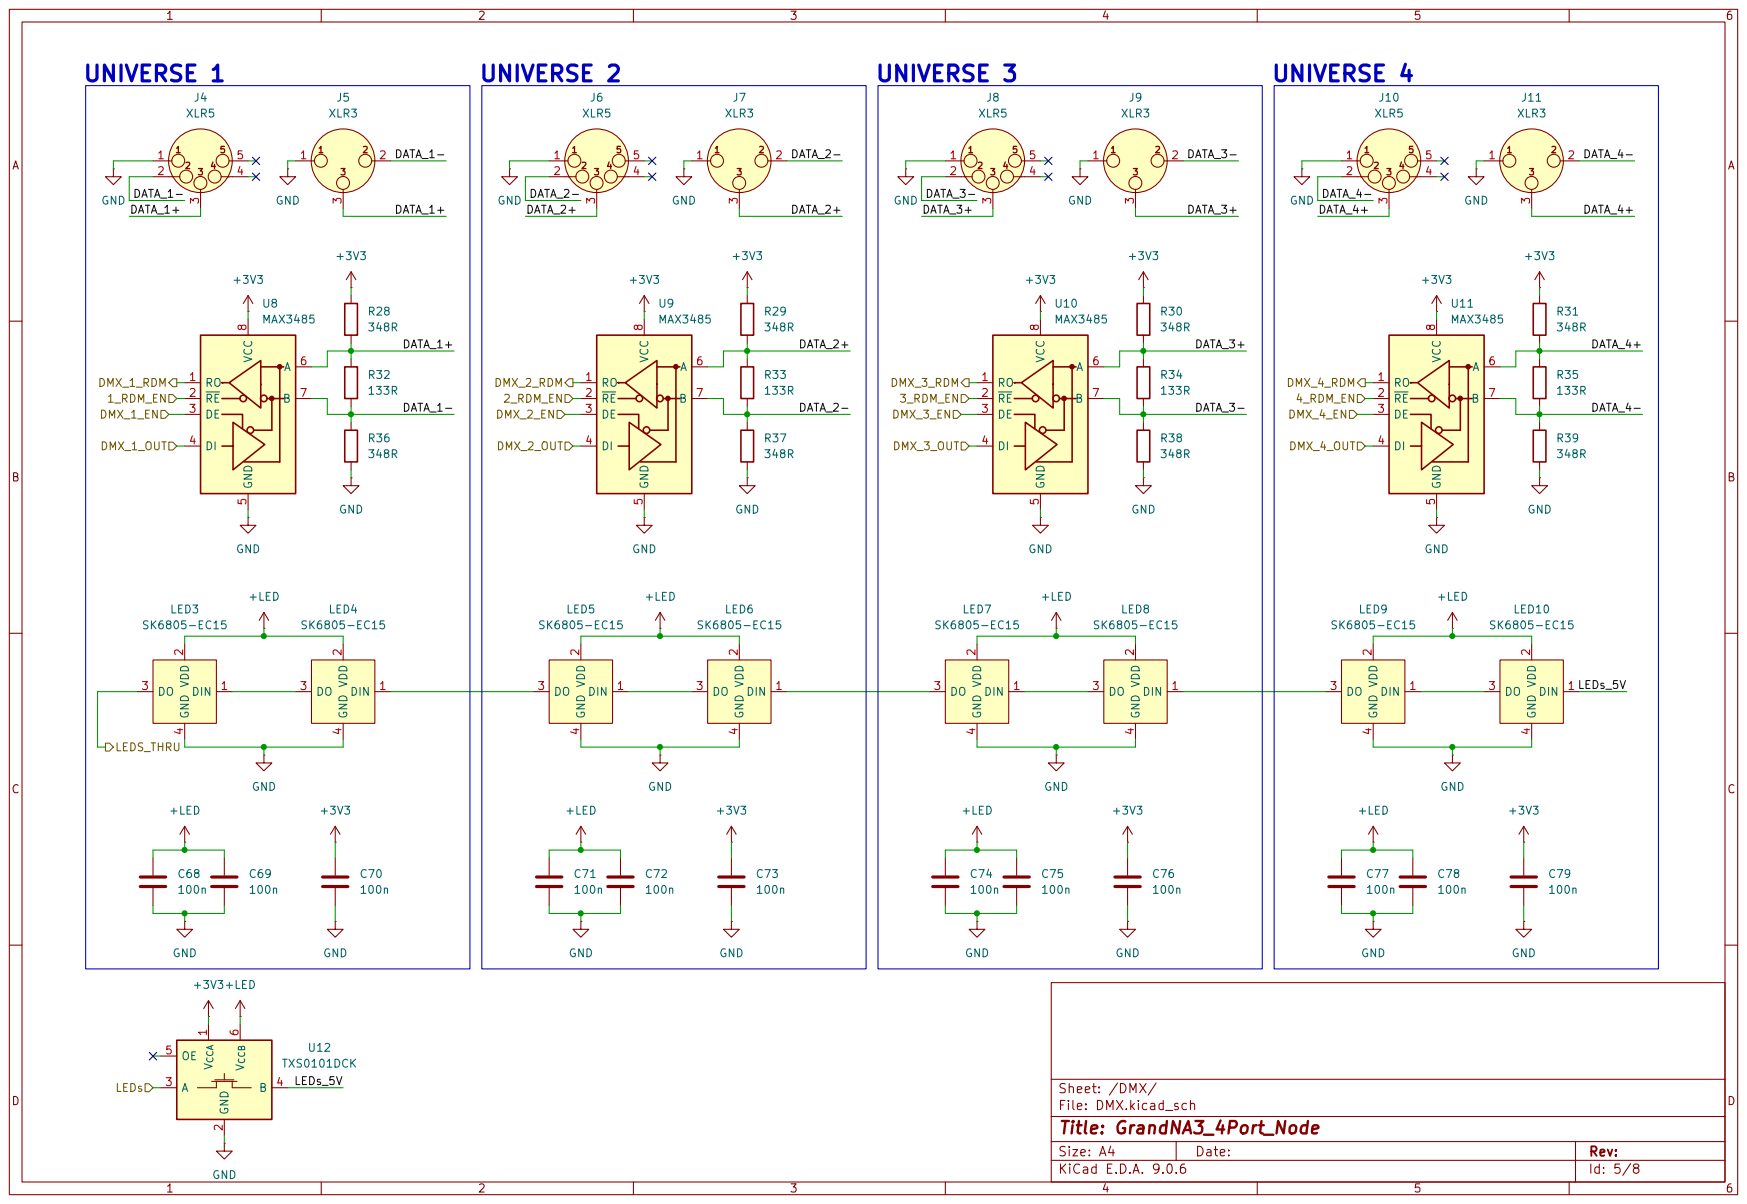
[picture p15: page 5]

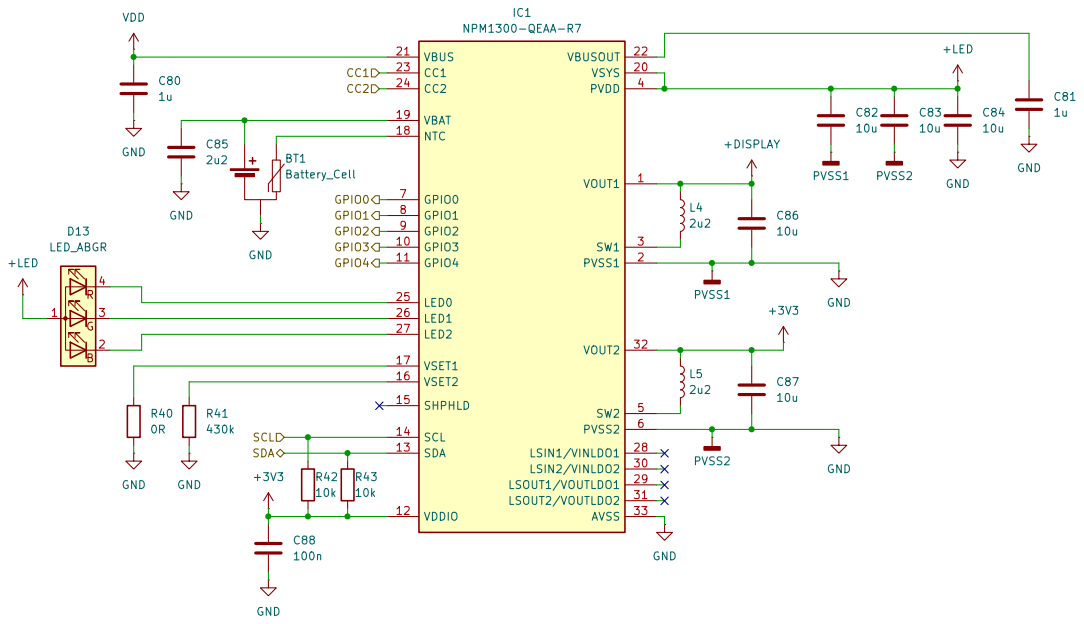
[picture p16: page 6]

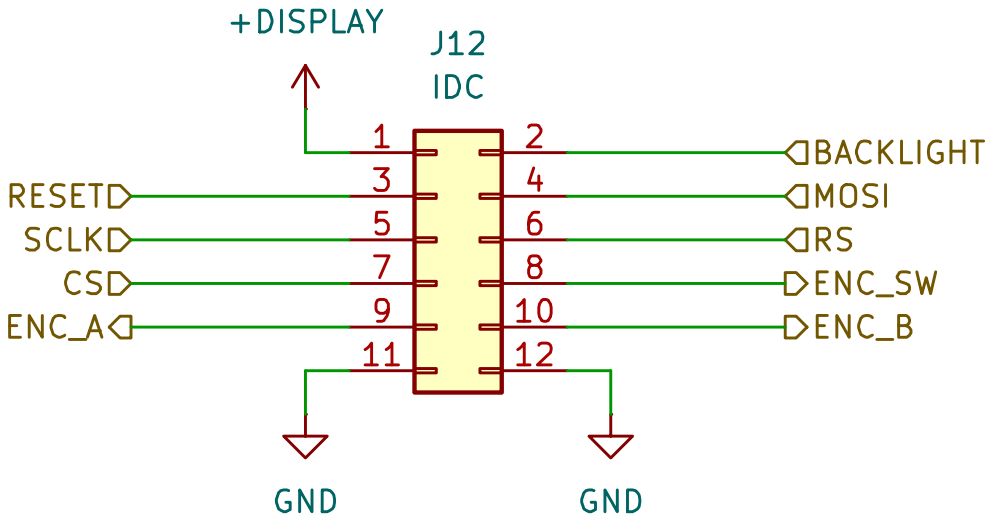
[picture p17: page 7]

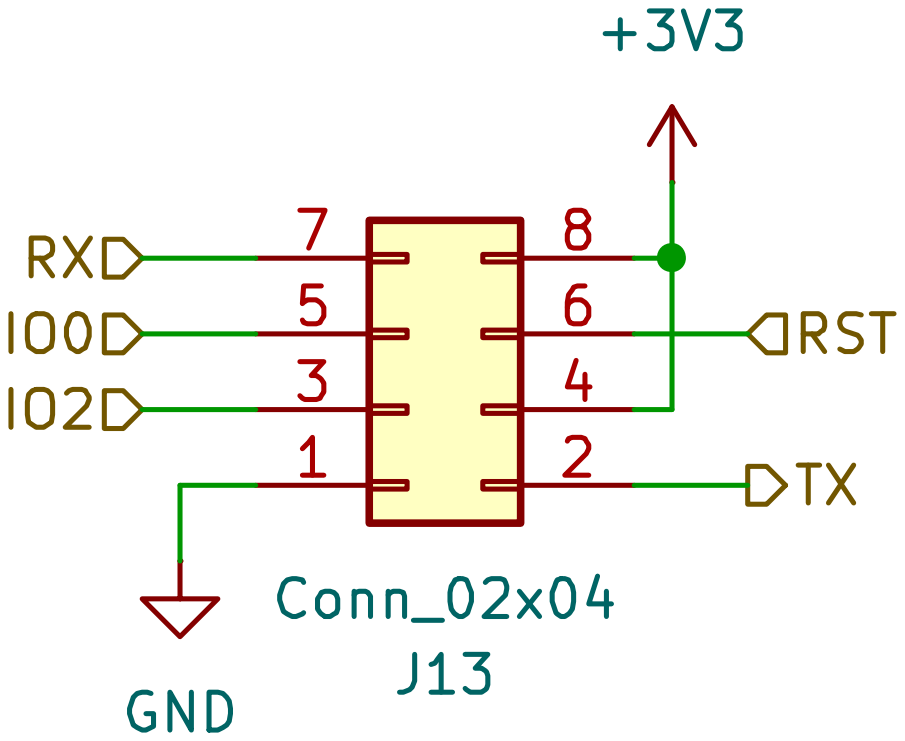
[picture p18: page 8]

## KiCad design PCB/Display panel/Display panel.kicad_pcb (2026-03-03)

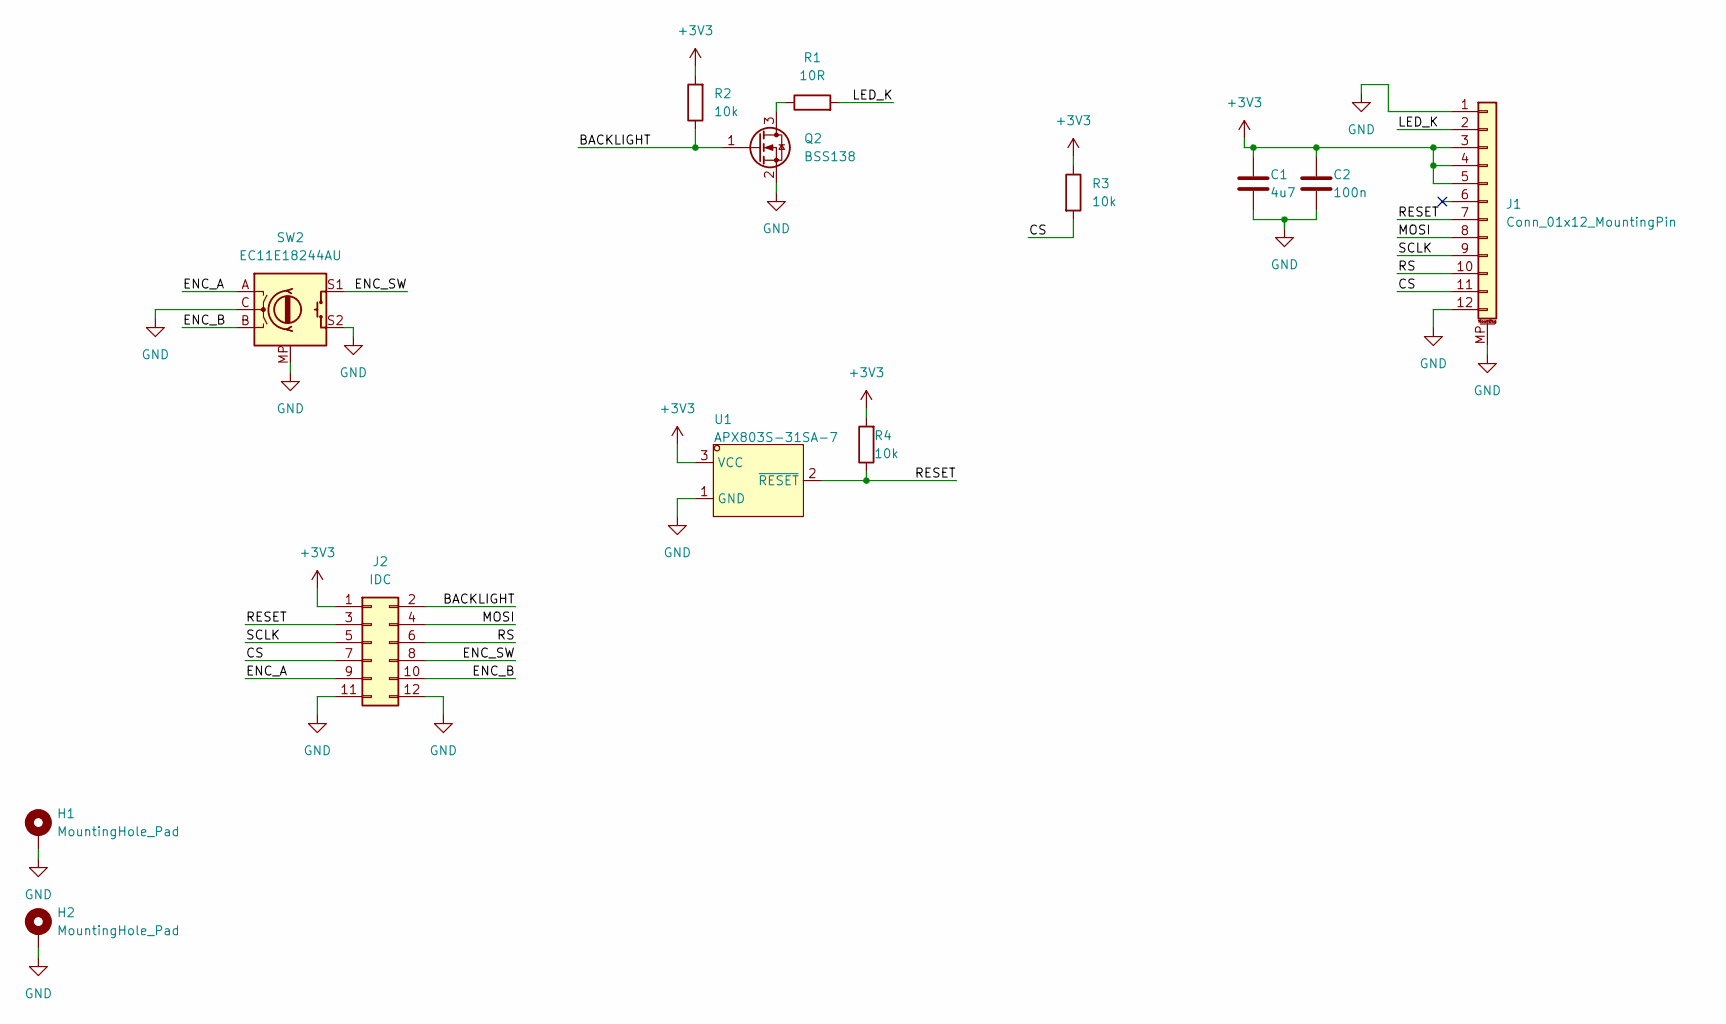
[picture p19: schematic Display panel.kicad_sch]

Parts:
C1: 4u7; C_0603_1608Metric
C2: 100n; C_0603_1608Metric
H1, H2: MountingHole_Pad; MountingHole_3.2mm_M3_Pad
J1: Conn_01x12_MountingPin; FPC-SMD_5034801200
J2: IDC; IDC-Header_2x06_P2.54mm_Vertical
Q2: BSS138; SOT-23
R1: 10R; R_0603_1608Metric
R2, R3, R4: 10k; R_0603_1608Metric
SW2: EC11E18244AU; RotaryEncoder_Alps_EC11E-Switch_Vertical_H20mm
U1: APX803S-31SA-7; SOT-23; LCSC Part C129757

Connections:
+3V3: C1.1, C2.1, J1.3, J1.4, J1.5, J2.1, R2.2, R3.1, R4.2, U1.3 (VCC)
/BACKLIGHT: J2.2, Q2.1 (G), R2.1
/CS: J1.11, J2.7, R3.2
/ENC_A: J2.9, SW2.A
/ENC_B: J2.10, SW2.B
/ENC_SW: J2.8, SW2.S1
/LED_K: J1.2, R1.2
/MOSI: J1.8, J2.4
/RESET: J1.7, J2.3, R4.1, U1.2 (~RESET)
/RS: J1.10, J2.6
/SCLK: J1.9, J2.5
GND: C1.2, C2.2, H1.1, H2.1, J1.1, J1.12, J1.MP (MountPin), J2.11, J2.12, Q2.2 (S), SW2.C, SW2.MP, SW2.S2, U1.1 (GND)
unnamed: Q2.3 (D), R1.1

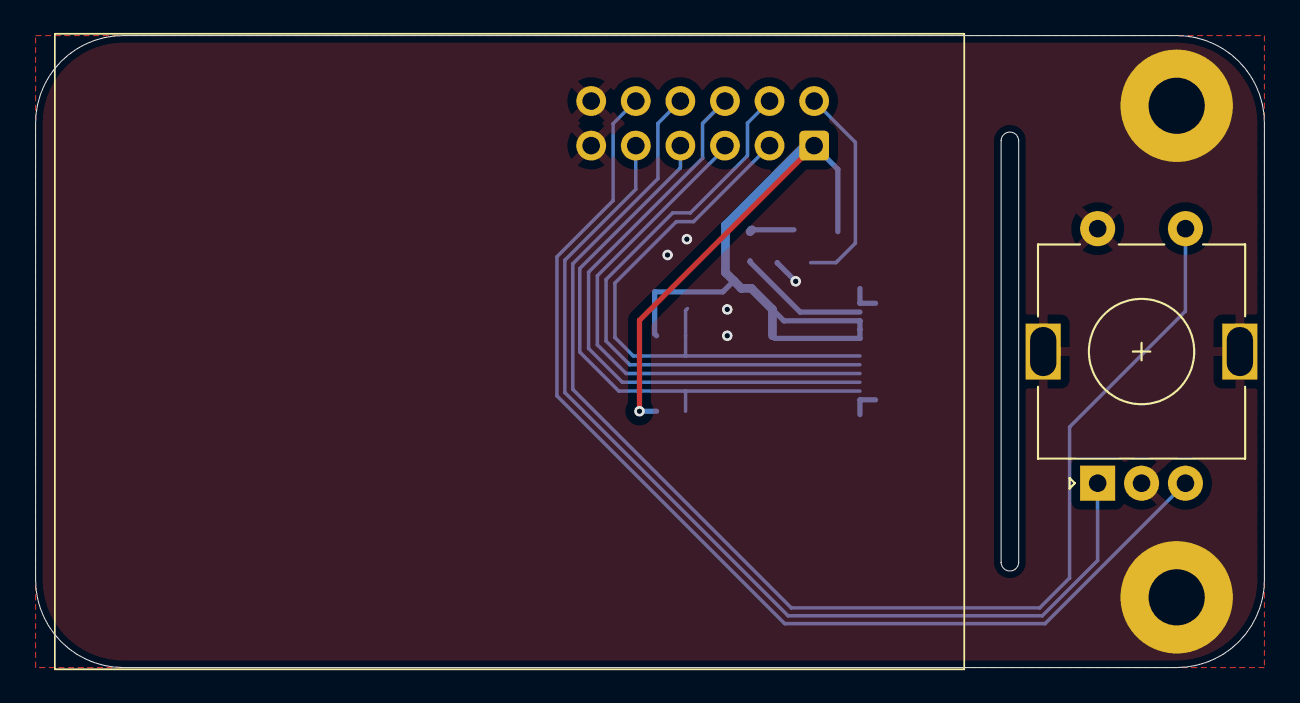
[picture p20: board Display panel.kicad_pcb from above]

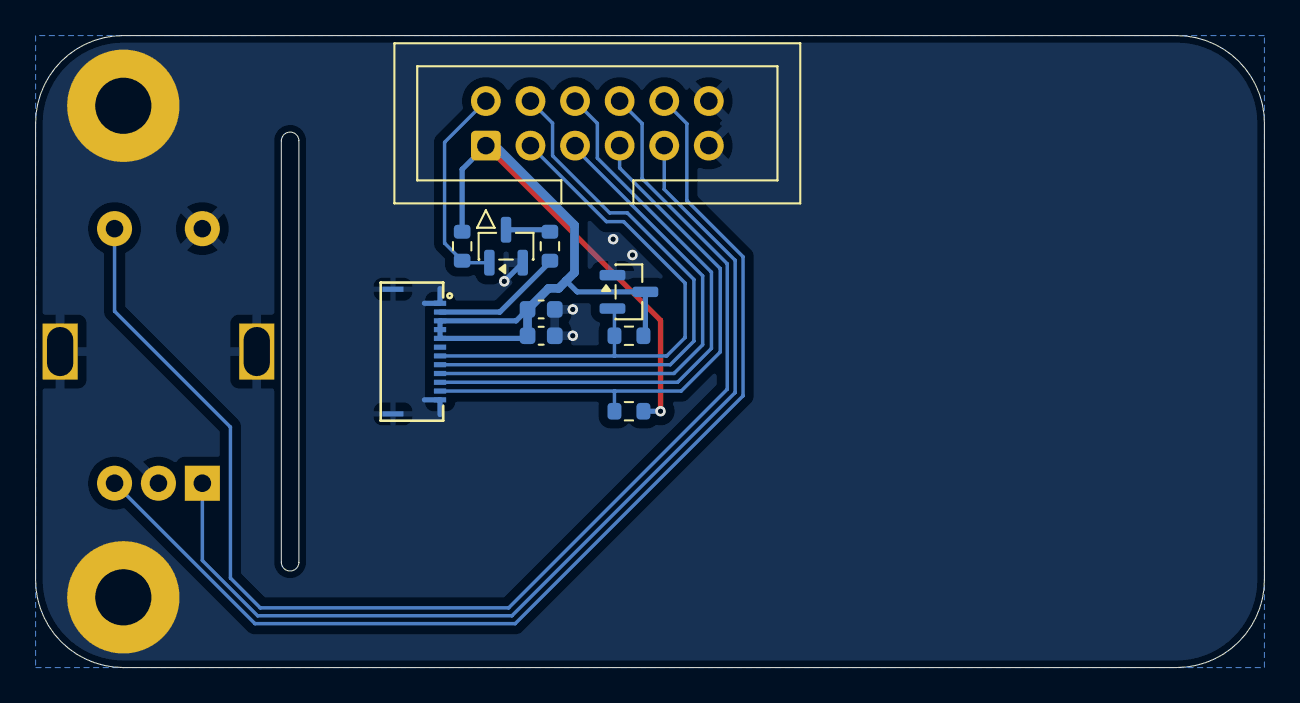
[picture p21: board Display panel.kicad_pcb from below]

Board: 2 copper layers, 70.0 x 36.0 mm, 13 parts (10 on the bottom side), 13 nets.

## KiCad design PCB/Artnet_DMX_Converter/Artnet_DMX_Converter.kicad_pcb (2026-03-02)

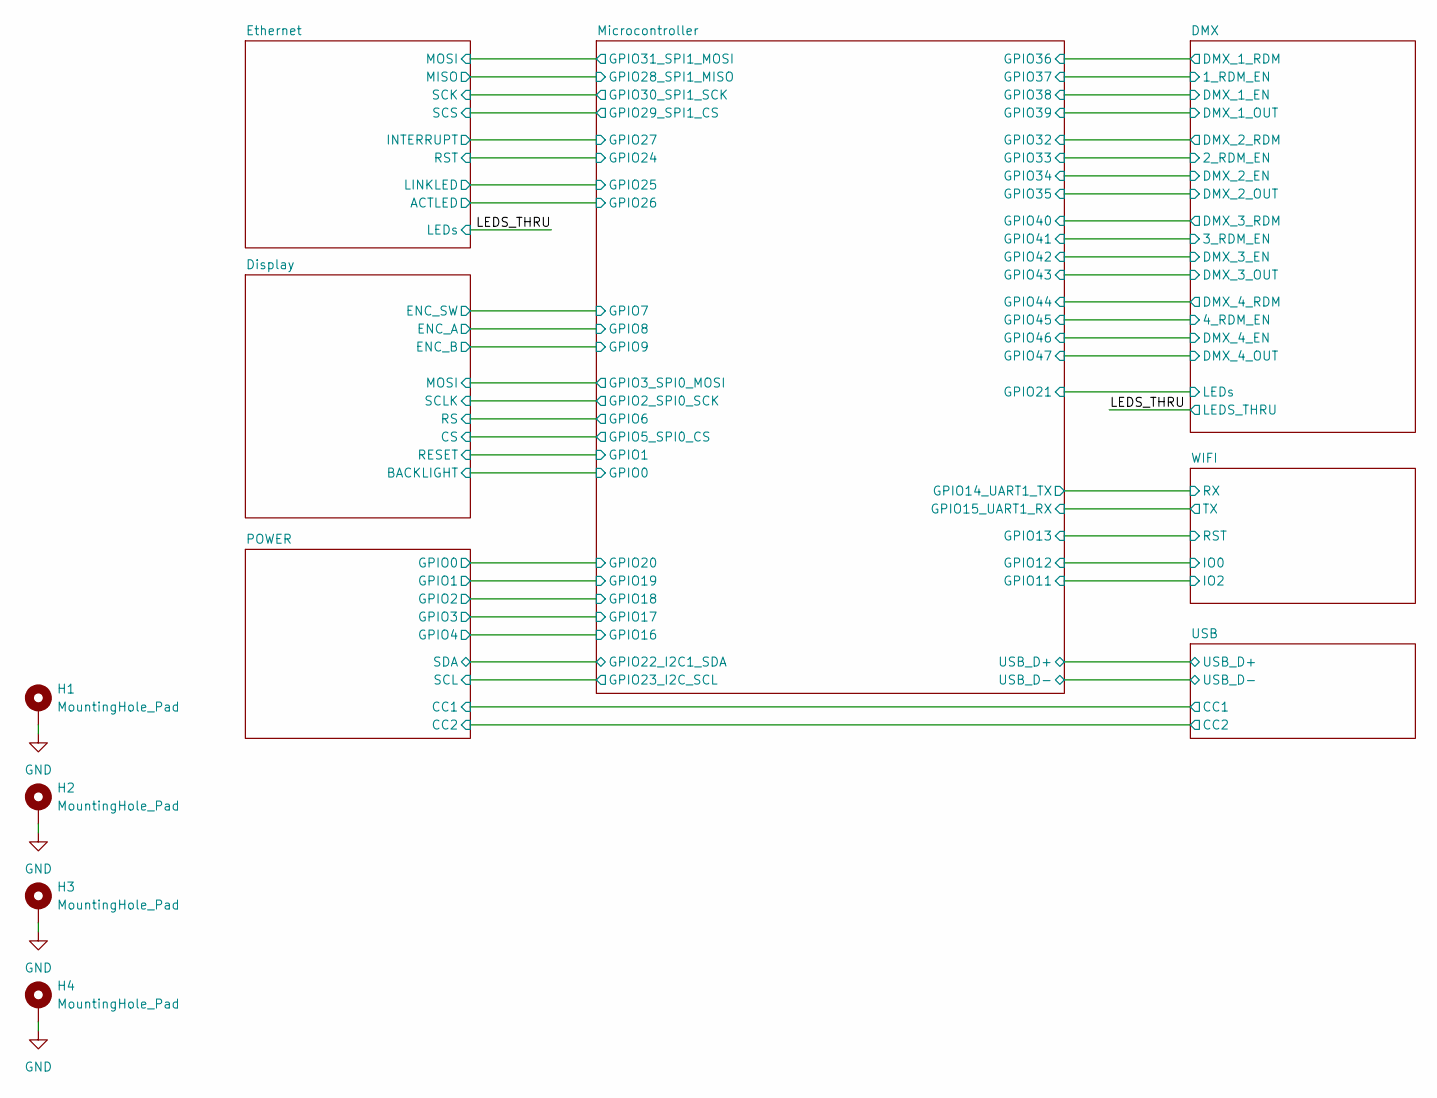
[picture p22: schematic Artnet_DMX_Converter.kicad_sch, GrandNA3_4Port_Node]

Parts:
H1, H2, H3, H4: MountingHole_Pad; MountingHole_3.2mm_M3_Pad

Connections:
GND: H1.1, H2.1, H3.1, H4.1; also elsewhere on the board

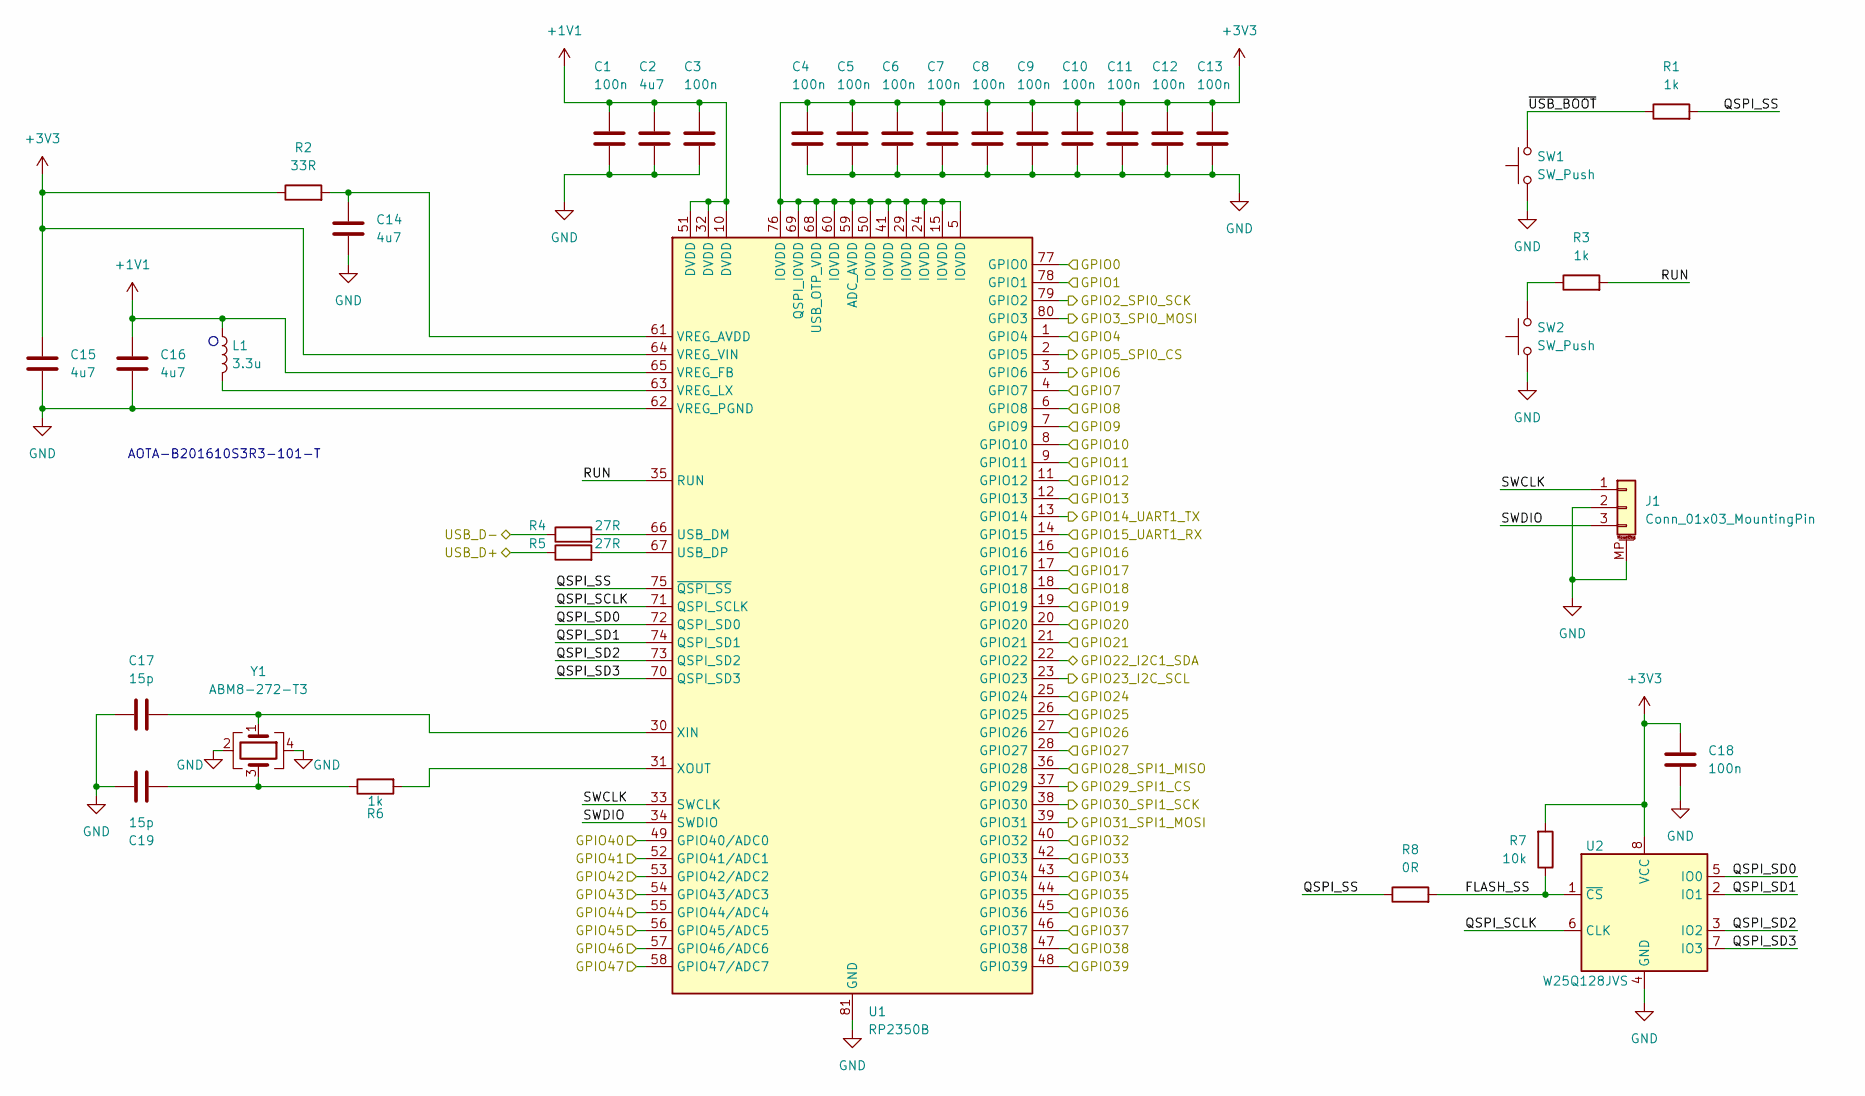
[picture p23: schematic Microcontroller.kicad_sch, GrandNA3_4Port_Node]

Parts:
C1, C3, C4, C5, C6, C7, C8, C9, C10, C11, C12, C13: 100n; C_0402_1005Metric
C2, C14, C15, C16: 4u7; C_0402_1005Metric
C17, C19: 15p; C_0402_1005Metric
C18: 100n; C_0603_1608Metric
J1: Conn_01x03_MountingPin; JST_SH_SM03B-SRSS-TB_1x03-1MP_P1.00mm_Horizontal
L1: 3.3u; IND-SMD_L2.0-W1.6_AOTA-B201610S3R3-101-T
R1, R3: 1k; R_0603_1608Metric
R2: 33R; R_0402_1005Metric
R4, R5: 27R; R_0402_1005Metric
R6: 1k; R_0402_1005Metric
R7: 10k; R_0603_1608Metric
R8: 0R; R_0603_1608Metric
SW1, SW2: SW_Push; SW_SPST_B3U-1000P
U1: RP2350B; QFN-80-1EP_10x10mm_P0.4mm_EP3.4x3.4mm
U2: W25Q128JVS; SOIC-8_5.3x5.3mm_P1.27mm
Y1: ABM8-272-T3; Crystal_SMD_3225-4Pin_3.2x2.5mm

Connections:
+1V1: C1.1, C2.1, C3.1, C16.1, L1.1, U1.10 (DVDD), U1.32 (DVDD), U1.51 (DVDD), U1.65 (VREG_FB)
+3V3: C4.1, C5.1, C6.1, C7.1, C8.1, C9.1, C10.1, C11.1, C12.1, C13.1, C15.1, C18.1, R2.1, R7.2, U1.5 (IOVDD), U1.15 (IOVDD), U1.24 (IOVDD), U1.29 (IOVDD), U1.41 (IOVDD), U1.50 (IOVDD), U1.59 (ADC_AVDD), U1.60 (IOVDD), U1.64 (VREG_VIN), U1.68 (USB_OTP_VDD), U1.69 (QSPI_IOVDD), U1.76 (IOVDD), U2.8 (VCC); also elsewhere on the board
/DMX/1_RDM_EN: U1.46 (GPIO37); also elsewhere on the board
/DMX/2_RDM_EN: U1.42 (GPIO33); also elsewhere on the board
/DMX/3_RDM_EN: U1.52 (GPIO41/ADC1); also elsewhere on the board
/DMX/4_RDM_EN: U1.56 (GPIO45/ADC5); also elsewhere on the board
/DMX/DMX_1_EN: U1.47 (GPIO38); also elsewhere on the board
/DMX/DMX_1_OUT: U1.48 (GPIO39); also elsewhere on the board
/DMX/DMX_1_RDM: U1.45 (GPIO36); also elsewhere on the board
/DMX/DMX_2_EN: U1.43 (GPIO34); also elsewhere on the board
/DMX/DMX_2_OUT: U1.44 (GPIO35); also elsewhere on the board
/DMX/DMX_2_RDM: U1.40 (GPIO32); also elsewhere on the board
/DMX/DMX_3_EN: U1.53 (GPIO42/ADC2); also elsewhere on the board
/DMX/DMX_3_OUT: U1.54 (GPIO43/ADC3); also elsewhere on the board
/DMX/DMX_3_RDM: U1.49 (GPIO40/ADC0); also elsewhere on the board
/DMX/DMX_4_EN: U1.57 (GPIO46/ADC6); also elsewhere on the board
/DMX/DMX_4_OUT: U1.58 (GPIO47/ADC7); also elsewhere on the board
/DMX/DMX_4_RDM: U1.55 (GPIO44/ADC4); also elsewhere on the board
/DMX/LEDs: U1.21 (GPIO21); also elsewhere on the board
/Display/BACKLIGHT: U1.77 (GPIO0); also elsewhere on the board
/Display/CS: U1.2 (GPIO5); also elsewhere on the board
/Display/ENC_A: U1.6 (GPIO8); also elsewhere on the board
/Display/ENC_B: U1.7 (GPIO9); also elsewhere on the board
/Display/ENC_SW: U1.4 (GPIO7); also elsewhere on the board
/Display/MOSI: U1.80 (GPIO3); also elsewhere on the board
/Display/RESET: U1.78 (GPIO1); also elsewhere on the board
/Display/RS: U1.3 (GPIO6); also elsewhere on the board
/Display/SCLK: U1.79 (GPIO2); also elsewhere on the board
/Ethernet/ACTLED: U1.27 (GPIO26); also elsewhere on the board
/Ethernet/INTERRUPT: U1.28 (GPIO27); also elsewhere on the board
/Ethernet/LINKLED: U1.26 (GPIO25); also elsewhere on the board
/Ethernet/MISO: U1.36 (GPIO28); also elsewhere on the board
/Ethernet/MOSI: U1.39 (GPIO31); also elsewhere on the board
/Ethernet/RST: U1.25 (GPIO24); also elsewhere on the board
/Ethernet/SCK: U1.38 (GPIO30); also elsewhere on the board
/Ethernet/SCS: U1.37 (GPIO29); also elsewhere on the board
/Microcontroller/FLASH_SS: R7.1, R8.2, U2.1 (~CS)
/Microcontroller/GPIO4: U1.1 (GPIO4)
/Microcontroller/GPIO10: U1.8 (GPIO10)
/Microcontroller/GPIO11: U1.9 (GPIO11); also elsewhere on the board
/Microcontroller/GPIO12: U1.11 (GPIO12); also elsewhere on the board
/Microcontroller/GPIO13: U1.12 (GPIO13); also elsewhere on the board
/Microcontroller/GPIO14_UART1_TX: U1.13 (GPIO14); also elsewhere on the board
/Microcontroller/GPIO15_UART1_RX: U1.14 (GPIO15); also elsewhere on the board
/Microcontroller/GPIO16: U1.16 (GPIO16); also elsewhere on the board
/Microcontroller/GPIO17: U1.17 (GPIO17); also elsewhere on the board
/Microcontroller/GPIO18: U1.18 (GPIO18); also elsewhere on the board
/Microcontroller/GPIO19: U1.19 (GPIO19); also elsewhere on the board
/Microcontroller/GPIO20: U1.20 (GPIO20); also elsewhere on the board
/Microcontroller/GPIO22_I2C1_SDA: U1.22 (GPIO22); also elsewhere on the board
/Microcontroller/GPIO23_I2C_SCL: U1.23 (GPIO23); also elsewhere on the board
/Microcontroller/QSPI_SCLK: U1.71 (QSPI_SCLK), U2.6 (CLK)
/Microcontroller/QSPI_SD0: U1.72 (QSPI_SD0), U2.5 (IO0)
/Microcontroller/QSPI_SD1: U1.74 (QSPI_SD1), U2.2 (IO1)
/Microcontroller/QSPI_SD2: U1.73 (QSPI_SD2), U2.3 (IO2)
/Microcontroller/QSPI_SD3: U1.70 (QSPI_SD3), U2.7 (IO3)
/Microcontroller/QSPI_SS: R1.2, R8.1, U1.75 (~QSPI_SS)
/Microcontroller/RUN: R3.2, U1.35 (RUN)
/Microcontroller/SWCLK: J1.1, U1.33 (SWCLK)
/Microcontroller/SWDIO: J1.3, U1.34 (SWDIO)
/Microcontroller/~USB_BOOT: R1.1, SW1.2
/USB/USB_D+: R5.1; also elsewhere on the board
/USB/USB_D-: R4.1; also elsewhere on the board
GND: C1.2, C2.2, C3.2, C4.2, C5.2, C6.2, C7.2, C8.2, C9.2, C10.2, C11.2, C12.2, C13.2, C14.2, C15.2, C16.2, C17.1, C18.2, C19.1, J1.2, J1.MP (MountPin), SW1.1, SW2.1, U1.62 (VREG_PGND), U1.81 (GND), U2.4 (GND), Y1.2 (G), Y1.4 (G); also elsewhere on the board
unnamed: C19.2, R6.1, Y1.3
unnamed: R3.1, SW2.2
unnamed: R4.2, U1.66 (USB_DM)
unnamed: R5.2, U1.67 (USB_DP)
unnamed: C14.1, R2.2, U1.61 (VREG_AVDD)
unnamed: L1.2, U1.63 (VREG_LX)
unnamed: C17.2, U1.30 (XIN), Y1.1
unnamed: R6.2, U1.31 (XOUT)

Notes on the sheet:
AOTA-B201610S3R3-101-T

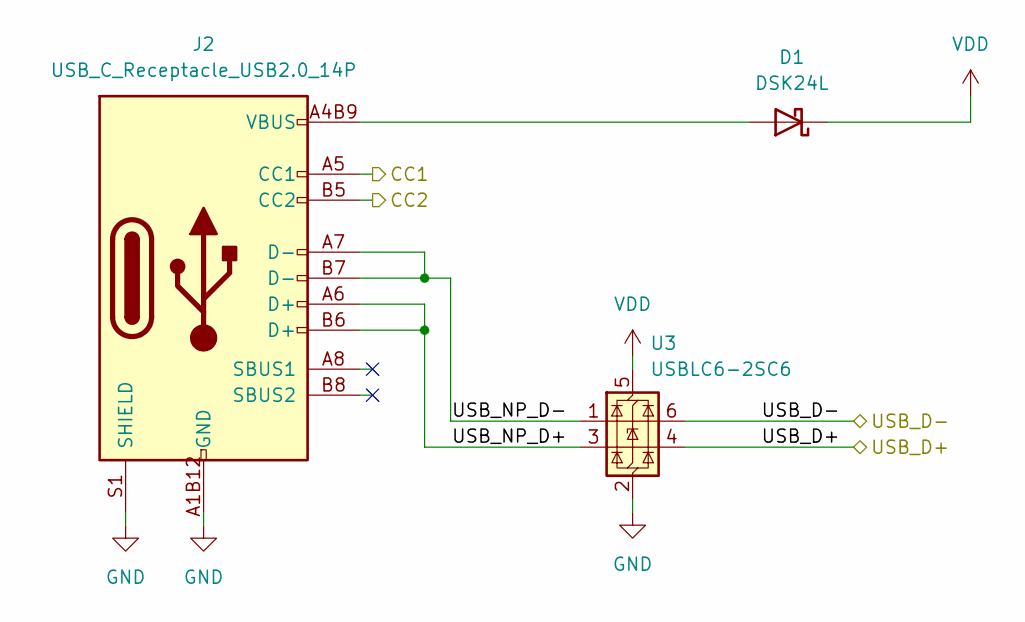
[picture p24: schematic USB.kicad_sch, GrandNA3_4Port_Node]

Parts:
D1: DSK24L; D_SOD-123F
J2: USB_C_Receptacle_USB2.0_14P; USB-C_SMD-TYPE-C-31-M-12_1
U3: USBLC6-2SC6; SOT-23-6

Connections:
/POWER/CC1: J2.A5 (CC1); also elsewhere on the board
/POWER/CC2: J2.B5 (CC2); also elsewhere on the board
/USB/USB_D+: U3.4 (I/O2); also elsewhere on the board
/USB/USB_D-: U3.6 (I/O1); also elsewhere on the board
/USB/USB_NP_D+: J2.A6 (D+), J2.B6 (D+), U3.3 (I/O2)
/USB/USB_NP_D-: J2.A7 (D-), J2.B7 (D-), U3.1 (I/O1)
GND: J2.A1B12 (GND), J2.B1A12 (GND), J2.S1 (SHIELD), U3.2 (GND); also elsewhere on the board
unnamed: D1.2 (A), J2.A4B9 (VBUS), J2.B4A9 (VBUS)
VDD: D1.1 (K), U3.5 (VBUS); also elsewhere on the board

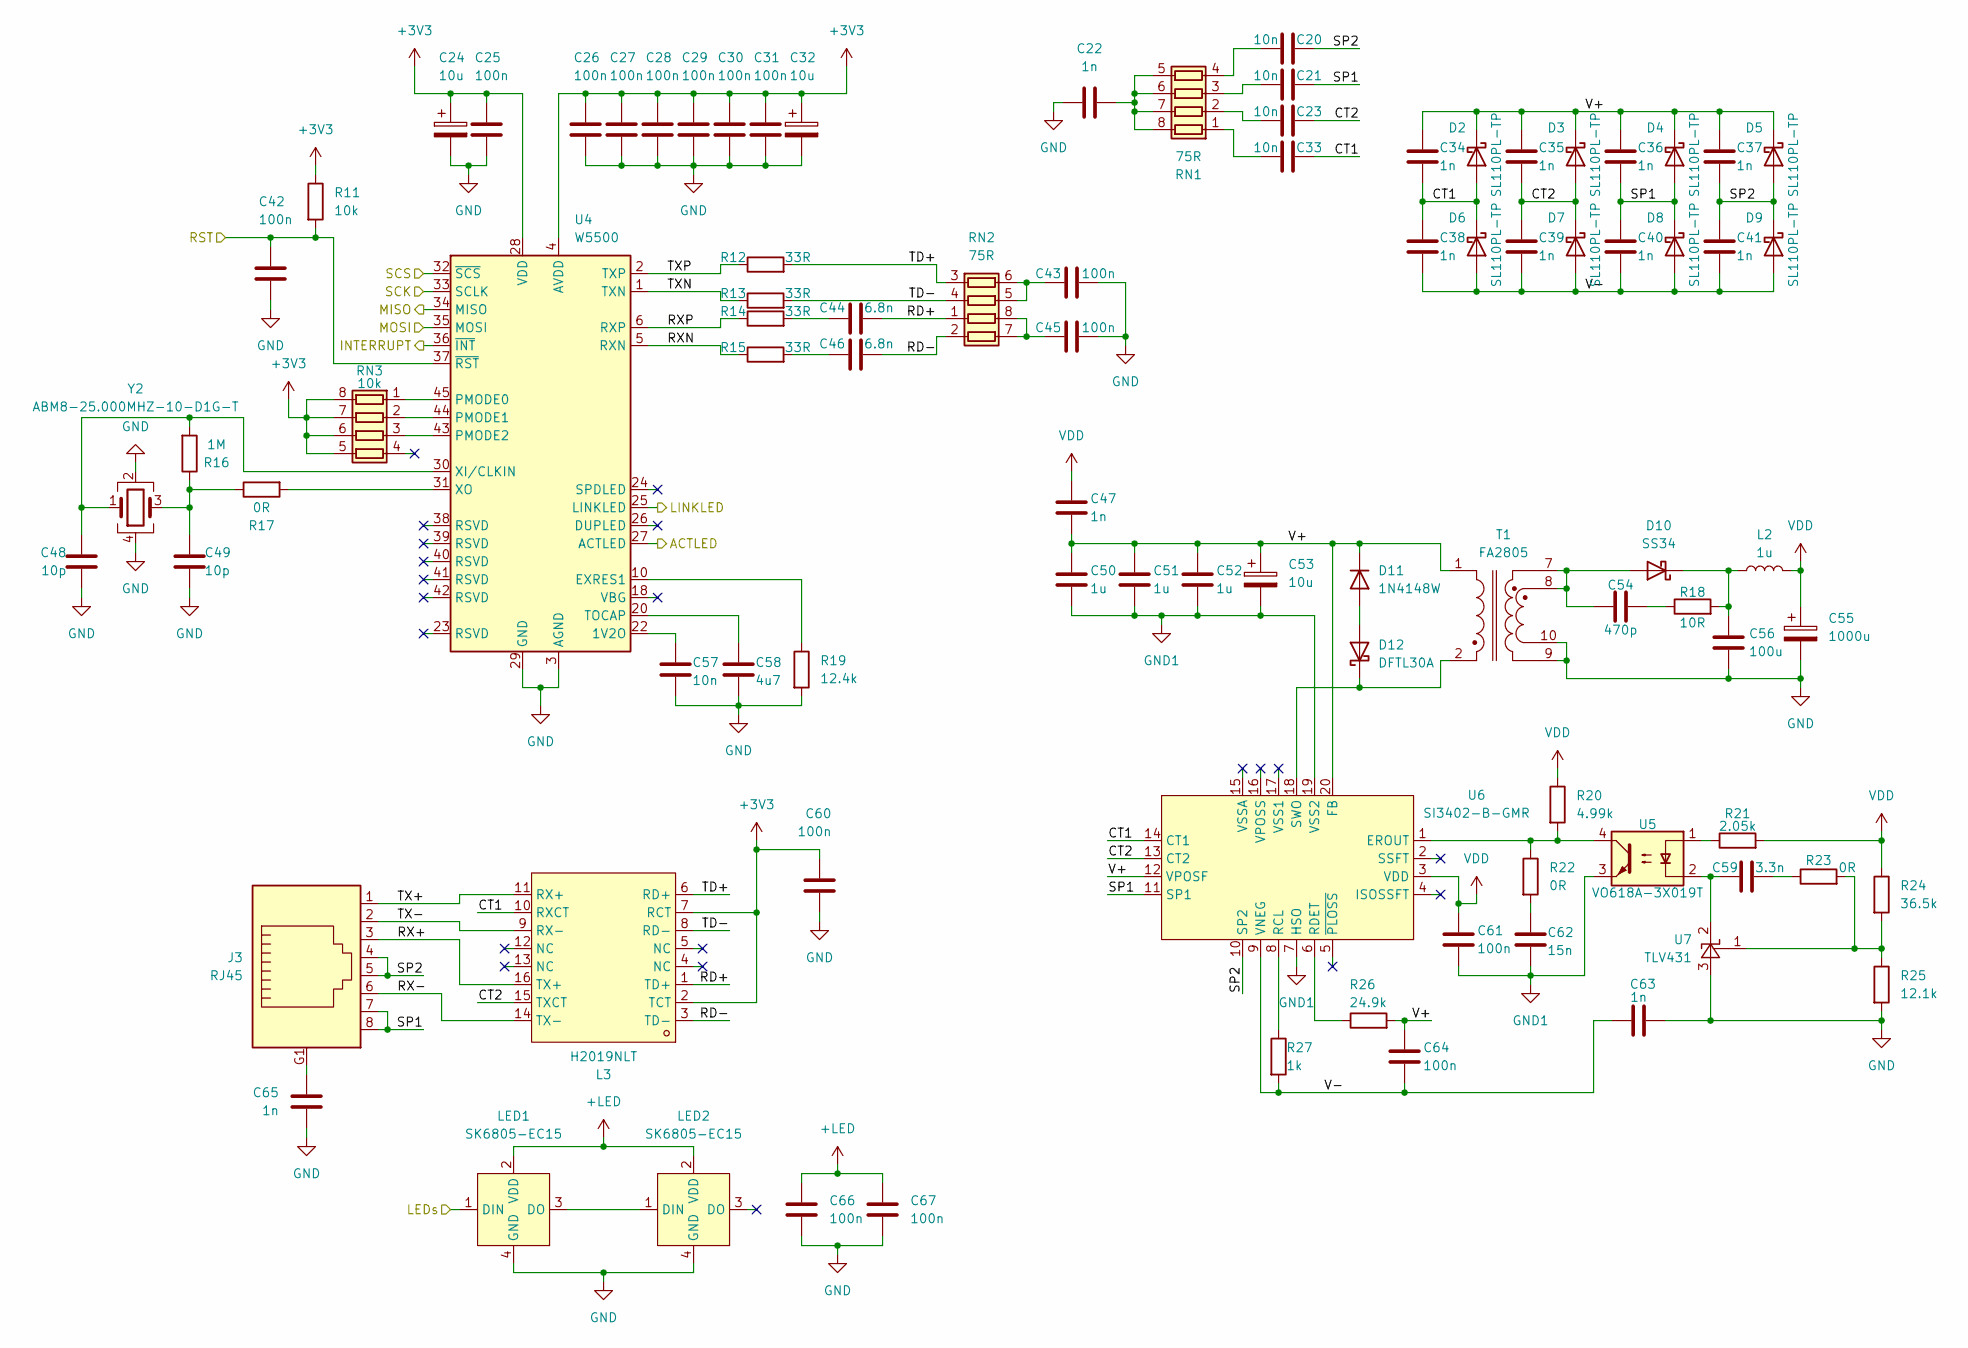
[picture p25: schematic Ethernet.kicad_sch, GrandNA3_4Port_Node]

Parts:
C20, C21, C23, C33, C57: 10n; C_0603_1608Metric
C22, C34, C35, C36, C37, C38, C39, C40, C41, C47, C63, C65: 1n; C_0603_1608Metric
C24, C32: 10u; CP_EIA-2012-12_Kemet-R
C25, C26, C27, C28, C29, C30, C31, C42, C43, C45, C60, C61, C64, C66, C67: 100n; C_0603_1608Metric
C44, C46: 6.8n; C_0603_1608Metric
C48, C49: 10p; C_0603_1608Metric
C50, C51, C52: 1u; C_0805_2012Metric
C53: 10u; CP_Elec_6.3x5.8
C54: 470p; C_0603_1608Metric
C55: 1000u; CP_Elec_10x10.5
C56: 100u; C_1206_3216Metric
C58: 4u7; C_0603_1608Metric
C59: 3.3n; C_0603_1608Metric
C62: 15n; C_0603_1608Metric
D2, D3, D4, D5, D6, D7, D8, D9: SL110PL-TP; D_SOD-123F
D10: SS34; D_SMA
D11: 1N4148W; D_SOD-123
D12: DFTL30A; D_SOD-123F
J3: RJ45; NE8FAHLRDAE
L2: 1u; L_Vishay_IHLP-1616
L3: H2019NLT; XFMR-SMD_16P-L12.7-W7.1-P1.27-LS9.4-BL; LCSC Part C110250
LED1, LED2: SK6805-EC15; LED-SMD_4P-L1.5-W1.5-BL; LCSC Part C2890035
R11: 10k; R_0603_1608Metric
R12, R13, R14, R15: 33R; R_0603_1608Metric
R16: 1M; R_0603_1608Metric
R17, R22, R23: 0R; R_0603_1608Metric
R18: 10R; R_0603_1608Metric
R19: 12.4k; R_0603_1608Metric
R20: 4.99k; R_0603_1608Metric
R21: 2.05k; R_0603_1608Metric
R24: 36.5k; R_0603_1608Metric
R25: 12.1k; R_0603_1608Metric
R26: 24.9k; R_0603_1608Metric
R27: 1k; R_0603_1608Metric
RN1, RN2: 75R; R_Array_Concave_4x0603
RN3: 10k; R_Array_Concave_4x0603
T1: FA2805; FA2924ALD
U4: W5500; LQFP-48_7x7mm_P0.5mm
U5: VO618A-3X019T; SMDIP-4_W9.53mm_Clearance8mm
U6: SI3402-B-GMR; QFN-20_L5.0-W5.0-P0.80-TL-EP2.8; LCSC Part C510771
U7: TLV431; TSOT-23
Y2: ABM8-25.000MHZ-10-D1G-T; Crystal_SMD_3225-4Pin_3.2x2.5mm

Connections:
+3V3: C24.1, C25.1, C26.1, C27.1, C28.1, C29.1, C30.1, C31.1, C32.1, C60.1, L3.2 (TCT), L3.7 (RCT), R11.1, RN3.5 (R4.2), RN3.6 (R3.2), RN3.7 (R2.2), RN3.8 (R1.2), U4.4 (AVDD), U4.8 (AVDD), U4.11 (AVDD), U4.15 (AVDD), U4.17 (AVDD), U4.21 (AVDD), U4.28 (VDD); also elsewhere on the board
+LED: C66.1, C67.1, LED1.2 (VDD), LED2.2 (VDD); also elsewhere on the board
/Ethernet/ACTLED: U4.27 (ACTLED); also elsewhere on the board
/Ethernet/CT1: C33.1, C34.2, C38.1, D2.2 (A), D6.1 (K), L3.10 (RXCT), U6.14 (CT1)
/Ethernet/CT2: C23.1, C35.2, C39.1, D3.2 (A), D7.1 (K), L3.15 (TXCT), U6.13 (CT2)
/Ethernet/INTERRUPT: U4.36 (~INT); also elsewhere on the board
/Ethernet/LINKLED: U4.25 (LINKLED); also elsewhere on the board
/Ethernet/MISO: U4.34 (MISO); also elsewhere on the board
/Ethernet/MOSI: U4.35 (MOSI); also elsewhere on the board
/Ethernet/RD+: C44.2, L3.1 (TD+), RN2.1 (R1.1)
/Ethernet/RD-: C46.2, L3.3 (TD-), RN2.2 (R2.1)
/Ethernet/RST: C42.1, R11.2, U4.37 (~RST); also elsewhere on the board
/Ethernet/RX+: J3.3, L3.16 (TX+)
/Ethernet/RX-: J3.6, L3.14 (TX-)
/Ethernet/RXN: R15.1, U4.5 (RXN)
/Ethernet/RXP: R14.1, U4.6 (RXP)
/Ethernet/SCK: U4.33 (SCLK); also elsewhere on the board
/Ethernet/SCS: U4.32 (~SCS); also elsewhere on the board
/Ethernet/SP1: C21.1, C36.2, C40.1, D4.2 (A), D8.1 (K), J3.7, J3.8, U6.11 (SP1)
/Ethernet/SP2: C20.1, C37.2, C41.1, D5.2 (A), D9.1 (K), J3.4, J3.5, U6.10 (SP2)
/Ethernet/TD+: L3.6 (RD+), R12.2, RN2.3 (R3.1)
/Ethernet/TD-: L3.8 (RD-), R13.2, RN2.4 (R4.1)
/Ethernet/TX+: J3.1, L3.11 (RX+)
/Ethernet/TX-: J3.2, L3.9 (RX-)
/Ethernet/TXN: R13.1, U4.1 (TXN)
/Ethernet/TXP: R12.1, U4.2 (TXP)
/Ethernet/V+: C34.1, C35.1, C36.1, C37.1, C47.2, C50.1, C51.1, C52.1, C53.1, C64.1, D2.1 (K), D3.1 (K), D4.1 (K), D5.1 (K), D11.1 (K), R26.2, T1.1, U6.12 (VPOSF), U6.20 (FB)
/Ethernet/V-: C38.2, C39.2, C40.2, C41.2, C63.1, C64.2, D6.2 (A), D7.2 (A), D8.2 (A), D9.2 (A), R27.2, U6.9 (VNEG), U6.21 (EP)
/LEDS_THRU: LED1.1 (DIN); also elsewhere on the board
GND: C22.2, C24.2, C25.2, C26.2, C27.2, C28.2, C29.2, C30.2, C31.2, C32.2, C42.2, C43.2, C45.2, C48.2, C49.2, C55.2, C56.2, C57.2, C58.2, C60.2, C63.2, C65.2, C66.2, C67.2, LED1.4 (GND), LED2.4 (GND), R19.2, R25.2, T1.9, T1.10, U4.3 (AGND), U4.9 (AGND), U4.14 (AGND), U4.16 (AGND), U4.19 (AGND), U4.29 (GND), U4.48 (AGND), U7.3 (A), Y2.2 (G), Y2.4 (G); also elsewhere on the board
GND1: C50.2, C51.2, C52.2, C53.2, C61.2, C62.2, U5.3, U6.7 (HSO), U6.19 (VSS2)
unnamed: C44.1, R14.2
unnamed: C46.1, R15.2
unnamed: C49.1, R16.1, R17.1, Y2.3
unnamed: C54.2, R18.1
unnamed: C59.2, R23.1
unnamed: C62.1, R22.2
unnamed: C65.1, J3.G1
unnamed: C54.1, D10.2 (A), T1.7, T1.8
unnamed: C56.1, D10.1 (K), L2.1, R18.2
unnamed: D11.2 (A), D12.2 (A)
unnamed: D12.1 (K), T1.2, U6.18 (SWO)
unnamed: LED1.3 (DO), LED2.1 (DIN)
unnamed: R21.1, U5.1
unnamed: C33.2, RN1.1 (R1.1)
unnamed: C22.1, RN1.5 (R4.2), RN1.6 (R3.2), RN1.7 (R2.2), RN1.8 (R1.2)
unnamed: C23.2, RN1.2 (R2.1)
unnamed: C21.2, RN1.3 (R3.1)
unnamed: C20.2, RN1.4 (R4.1)
unnamed: C45.1, RN2.7 (R2.2), RN2.8 (R1.2)
unnamed: C43.1, RN2.5 (R4.2), RN2.6 (R3.2)
unnamed: RN3.1 (R1.1), U4.45 (PMODE0)
unnamed: RN3.2 (R2.1), U4.44 (PMODE1)
unnamed: RN3.3 (R3.1), U4.43 (PMODE2)
unnamed: C57.1, U4.22 (1V2O)
unnamed: R19.1, U4.10 (EXRES1)
unnamed: C58.1, U4.20 (TOCAP)
unnamed: C48.1, R16.2, U4.30 (XI/CLKIN), Y2.1
unnamed: R17.2, U4.31 (XO)
unnamed: R20.2, R22.1, U5.4, U6.1 (EROUT)
unnamed: R27.1, U6.8 (RCL)
unnamed: R26.1, U6.6 (RDET)
unnamed: C59.1, U5.2, U7.2 (K)
unnamed: R23.2, R24.2, R25.1, U7.1 (Test)
VDD: C47.1, C55.1, C61.1, L2.2, R20.1, R21.2, R24.1, U6.3 (VDD); also elsewhere on the board

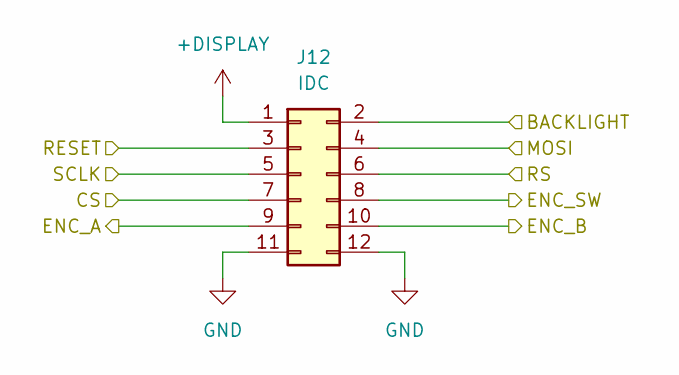
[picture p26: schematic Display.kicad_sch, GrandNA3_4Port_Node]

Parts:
J12: IDC; IDC-Header_2x06_P2.54mm_Vertical

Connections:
+DISPLAY: J12.1; also elsewhere on the board
/Display/BACKLIGHT: J12.2; also elsewhere on the board
/Display/CS: J12.7; also elsewhere on the board
/Display/ENC_A: J12.9; also elsewhere on the board
/Display/ENC_B: J12.10; also elsewhere on the board
/Display/ENC_SW: J12.8; also elsewhere on the board
/Display/MOSI: J12.4; also elsewhere on the board
/Display/RESET: J12.3; also elsewhere on the board
/Display/RS: J12.6; also elsewhere on the board
/Display/SCLK: J12.5; also elsewhere on the board
GND: J12.11, J12.12; also elsewhere on the board

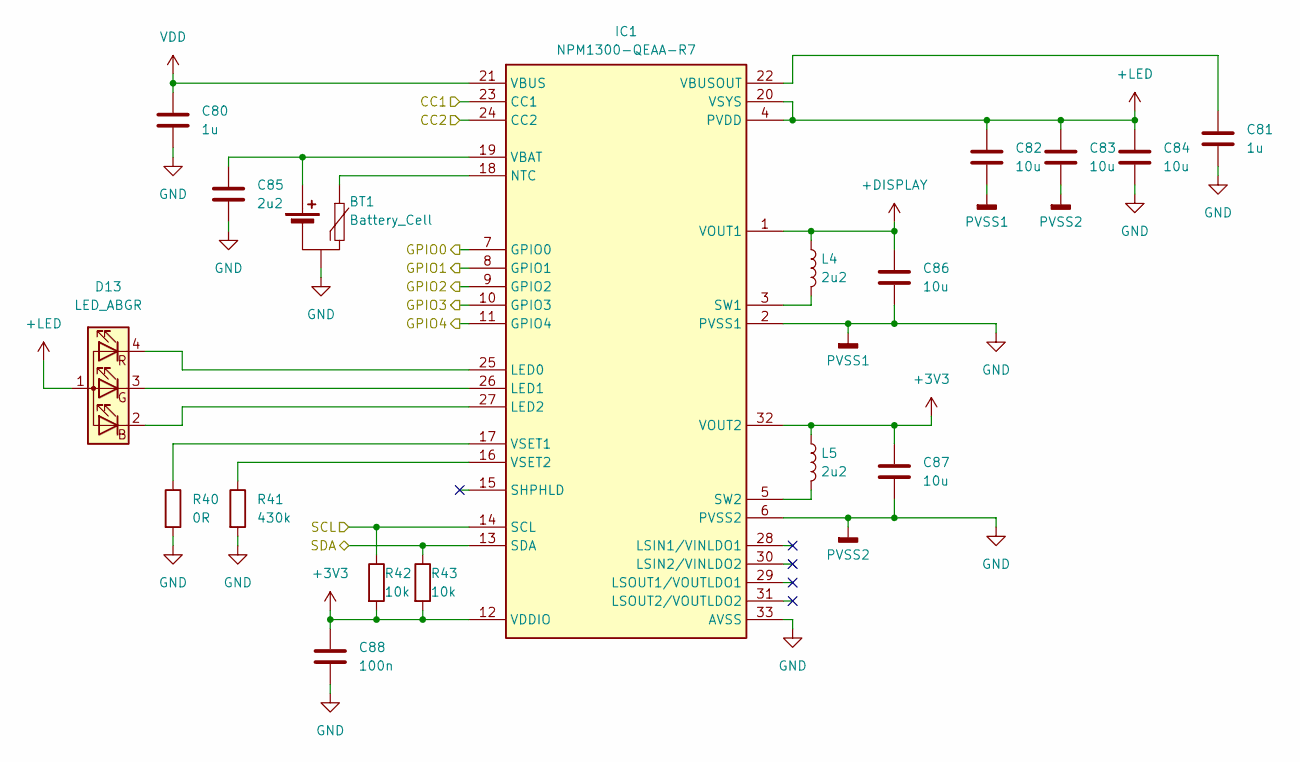
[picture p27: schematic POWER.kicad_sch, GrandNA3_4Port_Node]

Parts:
BT1: Battery_Cell; JST_XH_B3B-XH-A_1x03_P2.50mm_Vertical
C80, C81: 1u; C_0603_1608Metric
C82, C83, C84, C86, C87: 10u; C_0603_1608Metric
C85: 2u2; C_0603_1608Metric
C88: 100n; C_0603_1608Metric
D13: LED_ABGR; LED-SMD_4P-L1.6-W1.5-TR
IC1: NPM1300-QEAA-R7; QFN-32-1EP_5x5mm_P0.5mm_EP3.45x3.45mm_ThermalVias; Mouser Part Number 949-NPM1300-QEAA-R7
L4, L5: 2u2; L_0805_2012Metric
R40: 0R; R_0603_1608Metric
R41: 430k; R_0603_1608Metric
R42, R43: 10k; R_0603_1608Metric

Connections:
+3V3: C87.1, C88.1, IC1.12 (VDDIO), IC1.32 (VOUT2), L5.1, R42.2, R43.2; also elsewhere on the board
+DISPLAY: C86.1, IC1.1 (VOUT1), L4.1; also elsewhere on the board
+LED: C82.1, C83.1, C84.1, D13.1 (A), IC1.4 (PVDD), IC1.20 (VSYS); also elsewhere on the board
/Microcontroller/GPIO16: IC1.11 (GPIO4); also elsewhere on the board
/Microcontroller/GPIO17: IC1.10 (GPIO3); also elsewhere on the board
/Microcontroller/GPIO18: IC1.9 (GPIO2); also elsewhere on the board
/Microcontroller/GPIO19: IC1.8 (GPIO1); also elsewhere on the board
/Microcontroller/GPIO20: IC1.7 (GPIO0); also elsewhere on the board
/Microcontroller/GPIO22_I2C1_SDA: IC1.13 (SDA), R43.1; also elsewhere on the board
/Microcontroller/GPIO23_I2C_SCL: IC1.14 (SCL), R42.1; also elsewhere on the board
/POWER/CC1: IC1.23 (CC1); also elsewhere on the board
/POWER/CC2: IC1.24 (CC2); also elsewhere on the board
GND: BT1.2 (-), C80.2, C81.2, C82.2, C83.2, C84.2, C85.2, C86.2, C87.2, C88.2, IC1.2 (PVSS1), IC1.6 (PVSS2), IC1.33 (AVSS), R40.2, R41.2; also elsewhere on the board
unnamed: BT1.1 (+), C85.1, IC1.19 (VBAT)
unnamed: BT1.3 (NTC), IC1.18 (NTC)
unnamed: D13.2 (BK), IC1.27 (LED2)
unnamed: D13.3 (GK), IC1.26 (LED1)
unnamed: D13.4 (RK), IC1.25 (LED0)
unnamed: IC1.3 (SW1), L4.2
unnamed: IC1.5 (SW2), L5.2
unnamed: C81.1, IC1.22 (VBUSOUT)
unnamed: IC1.17 (VSET1), R40.1
unnamed: IC1.16 (VSET2), R41.1
VDD: C80.1, IC1.21 (VBUS); also elsewhere on the board

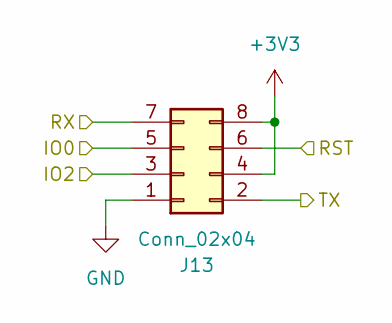
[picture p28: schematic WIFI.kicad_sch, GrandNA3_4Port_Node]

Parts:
J13: Conn_02x04; PinSocket_2x04_P2.54mm_Vertical

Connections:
+3V3: J13.4, J13.8; also elsewhere on the board
/Microcontroller/GPIO11: J13.3; also elsewhere on the board
/Microcontroller/GPIO12: J13.5; also elsewhere on the board
/Microcontroller/GPIO13: J13.6; also elsewhere on the board
/Microcontroller/GPIO14_UART1_TX: J13.7; also elsewhere on the board
/Microcontroller/GPIO15_UART1_RX: J13.2; also elsewhere on the board
GND: J13.1; also elsewhere on the board

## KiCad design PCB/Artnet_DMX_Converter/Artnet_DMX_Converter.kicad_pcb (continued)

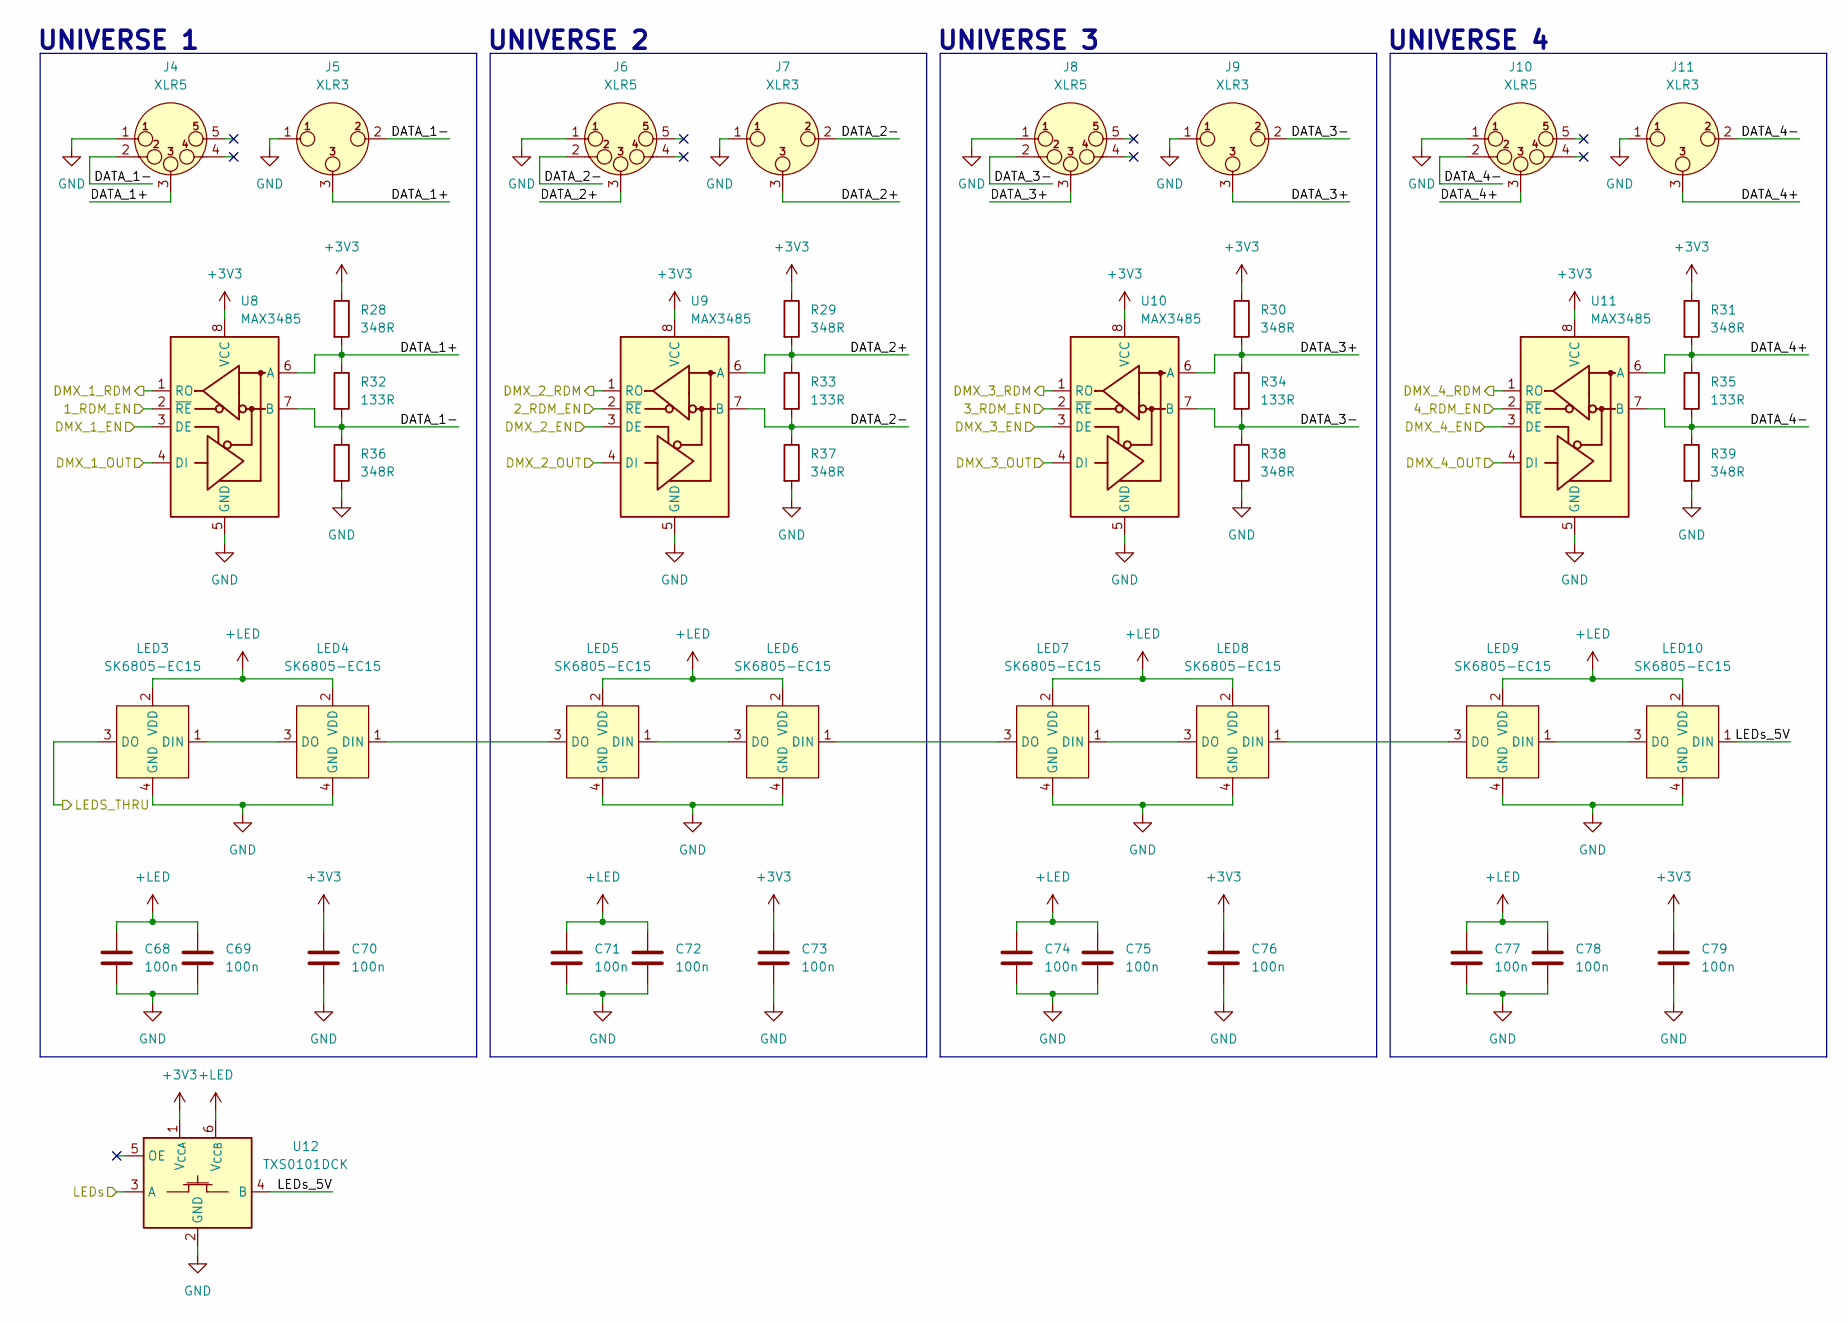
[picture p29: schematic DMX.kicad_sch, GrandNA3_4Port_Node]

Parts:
C68, C69, C70, C71, C72, C73, C74, C75, C76, C77, C78, C79: 100n; C_0603_1608Metric
J4, J6, J8, J10: XLR5; NC5FAH1-LR-DAE
J5, J7, J9, J11: XLR3; NC3FAH2-LR-DAE
LED3, LED4, LED5, LED6, LED7, LED8, LED9, LED10: SK6805-EC15; LED-SMD_4P-L1.5-W1.5-BL; LCSC Part C2890035
R28, R29, R30, R31, R36, R37, R38, R39: 348R; R_0603_1608Metric
R32, R33, R34, R35: 133R; R_0603_1608Metric
U8, U9, U10, U11: MAX3485; SOIC-8_3.9x4.9mm_P1.27mm
U12: TXS0101DCK; SOT-363_SC-70-6

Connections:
+3V3: C70.1, C73.1, C76.1, C79.1, R28.1, R29.1, R30.1, R31.1, U8.8 (VCC), U9.8 (VCC), U10.8 (VCC), U11.8 (VCC), U12.1 (V_{CCA}); also elsewhere on the board
+LED: C68.1, C69.1, C71.1, C72.1, C74.1, C75.1, C77.1, C78.1, LED3.2 (VDD), LED4.2 (VDD), LED5.2 (VDD), LED6.2 (VDD), LED7.2 (VDD), LED8.2 (VDD), LED9.2 (VDD), LED10.2 (VDD), U12.6 (V_{CCB}); also elsewhere on the board
/DMX/1_RDM_EN: U8.2 (~RE); also elsewhere on the board
/DMX/2_RDM_EN: U9.2 (~RE); also elsewhere on the board
/DMX/3_RDM_EN: U10.2 (~RE); also elsewhere on the board
/DMX/4_RDM_EN: U11.2 (~RE); also elsewhere on the board
/DMX/DATA_1+: J4.3, J5.3, R28.2, R32.1, U8.6 (A)
/DMX/DATA_1-: J4.2, J5.2, R32.2, R36.1, U8.7 (B)
/DMX/DATA_2+: J6.3, J7.3, R29.2, R33.1, U9.6 (A)
/DMX/DATA_2-: J6.2, J7.2, R33.2, R37.1, U9.7 (B)
/DMX/DATA_3+: J8.3, J9.3, R30.2, R34.1, U10.6 (A)
/DMX/DATA_3-: J8.2, J9.2, R34.2, R38.1, U10.7 (B)
/DMX/DATA_4+: J10.3, J11.3, R31.2, R35.1, U11.6 (A)
/DMX/DATA_4-: J10.2, J11.2, R35.2, R39.1, U11.7 (B)
/DMX/DMX_1_EN: U8.3 (DE); also elsewhere on the board
/DMX/DMX_1_OUT: U8.4 (DI); also elsewhere on the board
/DMX/DMX_1_RDM: U8.1 (RO); also elsewhere on the board
/DMX/DMX_2_EN: U9.3 (DE); also elsewhere on the board
/DMX/DMX_2_OUT: U9.4 (DI); also elsewhere on the board
/DMX/DMX_2_RDM: U9.1 (RO); also elsewhere on the board
/DMX/DMX_3_EN: U10.3 (DE); also elsewhere on the board
/DMX/DMX_3_OUT: U10.4 (DI); also elsewhere on the board
/DMX/DMX_3_RDM: U10.1 (RO); also elsewhere on the board
/DMX/DMX_4_EN: U11.3 (DE); also elsewhere on the board
/DMX/DMX_4_OUT: U11.4 (DI); also elsewhere on the board
/DMX/DMX_4_RDM: U11.1 (RO); also elsewhere on the board
/DMX/LEDs: U12.3 (A); also elsewhere on the board
/DMX/LEDs_5V: LED10.1 (DIN), U12.4 (B)
/LEDS_THRU: LED3.3 (DO); also elsewhere on the board
GND: C68.2, C69.2, C70.2, C71.2, C72.2, C73.2, C74.2, C75.2, C76.2, C77.2, C78.2, C79.2, J4.1, J5.1, J6.1, J7.1, J8.1, J9.1, J10.1, J11.1, LED3.4 (GND), LED4.4 (GND), LED5.4 (GND), LED6.4 (GND), LED7.4 (GND), LED8.4 (GND), LED9.4 (GND), LED10.4 (GND), R36.2, R37.2, R38.2, R39.2, U8.5 (GND), U9.5 (GND), U10.5 (GND), U11.5 (GND), U12.2 (GND); also elsewhere on the board
unnamed: LED3.1 (DIN), LED4.3 (DO)
unnamed: LED4.1 (DIN), LED5.3 (DO)
unnamed: LED5.1 (DIN), LED6.3 (DO)
unnamed: LED6.1 (DIN), LED7.3 (DO)
unnamed: LED7.1 (DIN), LED8.3 (DO)
unnamed: LED8.1 (DIN), LED9.3 (DO)
unnamed: LED9.1 (DIN), LED10.3 (DO)

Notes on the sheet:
UNIVERSE 1
UNIVERSE 3
UNIVERSE 4
UNIVERSE 2

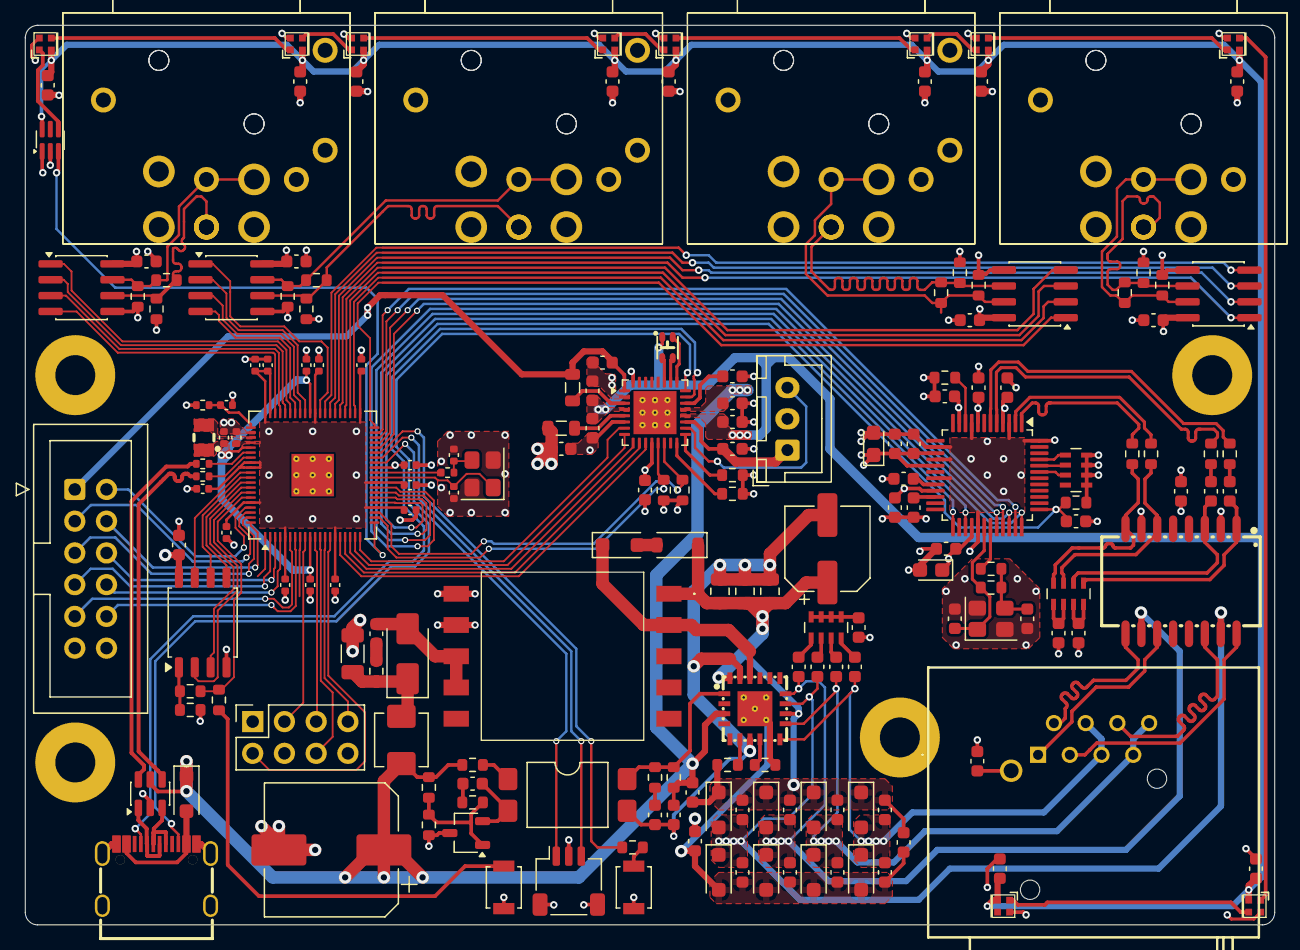
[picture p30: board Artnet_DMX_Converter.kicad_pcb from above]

Board: 4 copper layers, 100.0 x 72.0 mm, 196 parts (0 on the bottom side), 157 nets.

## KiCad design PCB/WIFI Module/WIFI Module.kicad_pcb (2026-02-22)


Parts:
C1: 10u; C_0603_1608Metric
C2, C3, C4, C5, C6: 100n; C_0402_1005Metric
C7, C8: 3p; C_0402_1005Metric
C9, C10: 14p; C_0402_1005Metric
J1: Conn_01x01_Shielded; U.FL_Molex_MCRF_73412-0110_Vertical
J2: Conn_02x04; PinHeader_2x04_P2.54mm_Vertical
L1: 2n; L_0402_1005Metric
R1: 10k; R_0402_1005Metric
TP1, TP2: TestPoint; TestPoint_Pad_D1.0mm
U1: ESP8684; QFN-24-1EP_4x4mm_P0.5mm_EP2.8x2.8mm
Y1: Q22FA12800230; Crystal_SMD_SeikoEpson_FA128-4Pin_2.0x1.6mm

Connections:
+3V3: C1.1, C2.1, C3.1, C4.1, C5.1, C6.1, J2.2, R1.2, U1.2 (VDDA3P3), U1.3 (VDDA3P3), U1.11 (VDD3P3_RTC), U1.17 (VDD3P3_CPU), U1.21 (VDDA), U1.24 (VDDA)
/EN: J2.6, U1.7 (CHIP_EN)
/GPIO9: R1.1, TP2.1, U1.15 (GPIO9/BOOT)
/GPIO10: J2.5, U1.16 (GPIO10/FSPICS0)
/GPIO18: J2.3, U1.18 (GPIO18)
/RST: J2.4
/RX: J2.1, U1.19 (U0RXD/GPIO19)
/TX: J2.8, U1.20 (U0TXD/GPIO20)
GND: C1.2, C2.2, C3.2, C4.2, C5.2, C6.2, C7.2, C8.2, C9.1, C10.1, J1.SH (Shield), J2.7, U1.25 (GND), Y1.2 (G), Y1.4 (G)
unnamed: C7.1, J1.1, L1.1
unnamed: C8.1, L1.2, U1.1 (ANT)
unnamed: TP1.1, U1.14 (GPIO8)
unnamed: C9.2, U1.22 (XTAL_N), Y1.1
unnamed: C10.2, U1.23 (XTAL_P), Y1.3


Board: 4 copper layers, 23.0 x 13.0 mm, 18 parts (1 on the bottom side), 13 nets.

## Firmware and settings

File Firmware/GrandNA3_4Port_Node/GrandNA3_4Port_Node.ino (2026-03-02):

#include <SPI.h>
#include <Ethernet.h>
#include <ArtnetEther.h>
#include <DmxOutput.h>

// --- Configuration ---
byte mac[] = { 0xDE, 0xAD, 0xBE, 0xEF, 0xFE, 0x01 };
IPAddress ip(192, 168, 1, 100); // Set to your network range

// --- Hardware Config ---
const int eth_cs = 29;
const int dmxOutPins[4] = {39, 35, 43, 47};
const int dmxEnPins[4]  = {38, 34, 42, 46};

// Global Artnet Object
ArtnetEtherReceiver artnet; 
uint8_t dmxBuffer[4][512];
DmxOutput dmxOut[4];

void setup() {
  // SPI1 Setup for RP2350
  SPI1.setRX(28);
  SPI1.setTX(31);
  SPI1.setSCK(30);
  
  Ethernet.init(eth_cs);
  Ethernet.begin(mac, ip);

  artnet.begin();

  // Subscribe to 4 Universes (Subnet 0, Universe 0-3)
  for (int i = 0; i < 4; i++) {
    artnet.subscribe(i, [i](const uint8_t* data, uint16_t size) {
      // Copy incoming Art-Net data to the buffer for Core 1 to use
      memcpy(dmxBuffer[i], data, size > 512 ? 512 : size);
    });
  }
}

void loop() {
  artnet.parse(); // Continuously check for Art-Net packets
}

// --- CORE 1: DMX Engine ---
void setup1() {
  for (int i = 0; i < 4; i++) {
    pinMode(dmxEnPins[i], OUTPUT);
    digitalWrite(dmxEnPins[i], HIGH); // Enable Transmit
    dmxOut[i].begin(dmxOutPins[i]);
  }
}

void loop1() {
  for (int i = 0; i < 4; i++) {
    dmxOut[i].write(dmxBuffer[i], 512);
  }
  delay(25); // Maintain ~40Hz
}

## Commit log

2026-02-22 Initial upload of PCB files ext.
    [Artnet_DMX_Converter.csv, Artnet_DMX_Converter.kicad_pcb, Artnet_DMX_Converter.kicad_sch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]
2026-02-22 new bom
2026-02-22 Completed BOM and started renders
    [BOM_ORDER.xlsx]
2026-02-23 Enhance README with detailed project description
    Expanded the README to provide detailed information about the GrandNA3_4Port_Node, including features, motivation, design process, and schematic references.
2026-02-23 Updated KiCad
    [Artnet_DMX_Converter.kicad_pcb, Artnet_DMX_Converter.kicad_sch, DMX.kicad_sch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]
2026-02-23 Updated pcb files again....
    [Artnet_DMX_Converter.kicad_pcb, Ethernet.kicad_sch, Microcontroller.kicad_sch]
2026-02-26 Updated PCB files
    [Artnet_DMX_Converter.kicad_pcb]
2026-03-02 Added firmware and some changes to the PCB
    [Artnet_DMX_Converter.kicad_pcb]
2026-03-02 Fix image paths for case images
    Updated image paths for case images in README.
2026-03-03 Fixed production files and added BOM.csv in BOMs folder and root folder
    [BOM_ORDER.csv, BOM_ORDER.xlsx, Display panel.kicad_pcb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]
2026-03-03 Fixed some more stuff
    [BOM_ORDER.csv]
2026-03-03 Added BOM
2026-03-03 Removed useless .obj
    [GrandNA3_4Port_Node.obj]
2026-03-03 Include Onshape link in README
    Added Onshape link for the project case.
